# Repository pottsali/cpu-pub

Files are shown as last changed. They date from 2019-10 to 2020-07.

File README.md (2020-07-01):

# MUPS/16 Homebrew CPU project

This is public repo for files from the MUPS/16 homebrew CPU project. Please see http://mups16.net for details.

## Files

### Schematics
Currently I've only uploaded the schematics for the PCBs here, and will add more as I complete the last few bits. Most of the schematics are documented on the MUPS/16 [website](http://mups16.net).

### Others
I have a few other sets of files to clean up and upload:
 - A gate-level simulation of the whole system in [Digital](https://github.com/hneemann/Digital) format
 - Microcode generation, for the control ROMs
 - An assembler
 - A very basic monitor to test the system
 
These are not yet in a fit state to upload, but I will add them as I clean them up.

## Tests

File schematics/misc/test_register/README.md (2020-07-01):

# Test register

This is a trivial, single 16-bit register with separate input and dual output buses. Kicad PCB files are included alongside the schematic. Each register has four control inputs:
 - `read`: if this is low then the register will latch the value on the `data` input the next time the `clk` signal goes high;
 - `wrA`: if this is low then the register will output its value to the A output bus
 - `wrB`: if this is low then the register will output its value to the B output bus
 - `clk`: the clock signal

Power input is 5 volts.

Note that this was my first ever attempt at a PCB, so I'm sure that there are a lot of bad design choices here. One thing I've already noticed is that the power and ground traces are too thin. I also over-complicated the routing of traces by not taking advantage of the fact that a trace can happily fit through the gap between pads of any of the ICs.

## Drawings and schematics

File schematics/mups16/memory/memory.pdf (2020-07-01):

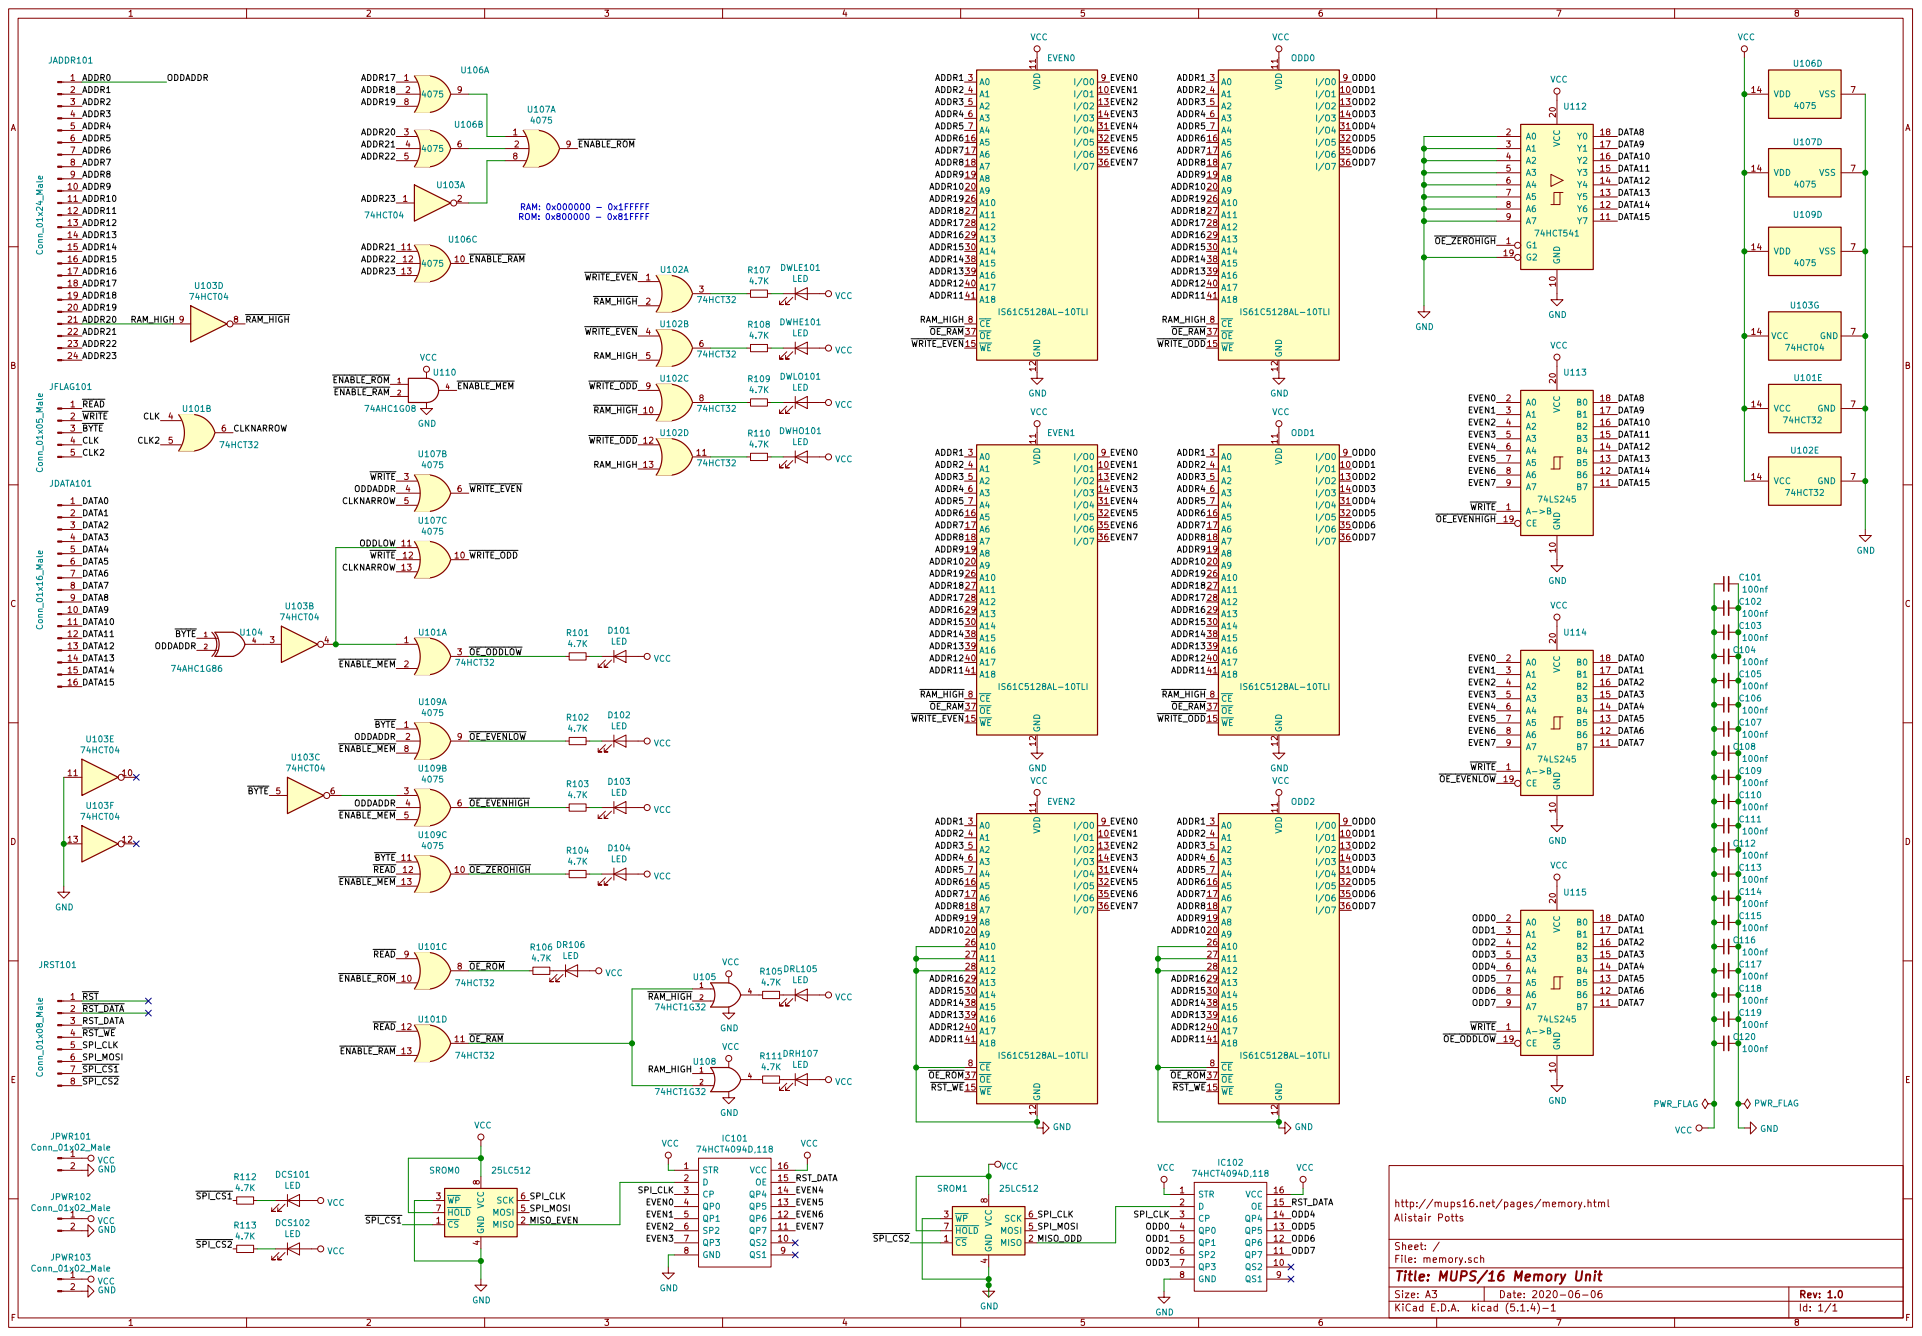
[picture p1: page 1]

4 MOSI 5 SCK 6 HOLD 7 VCC

File: memory.sch Sheet: / Alistair Potts http://mups16.net/pages/memory.html

Id: 1/1 Title: MUPS/16 Memory Unit

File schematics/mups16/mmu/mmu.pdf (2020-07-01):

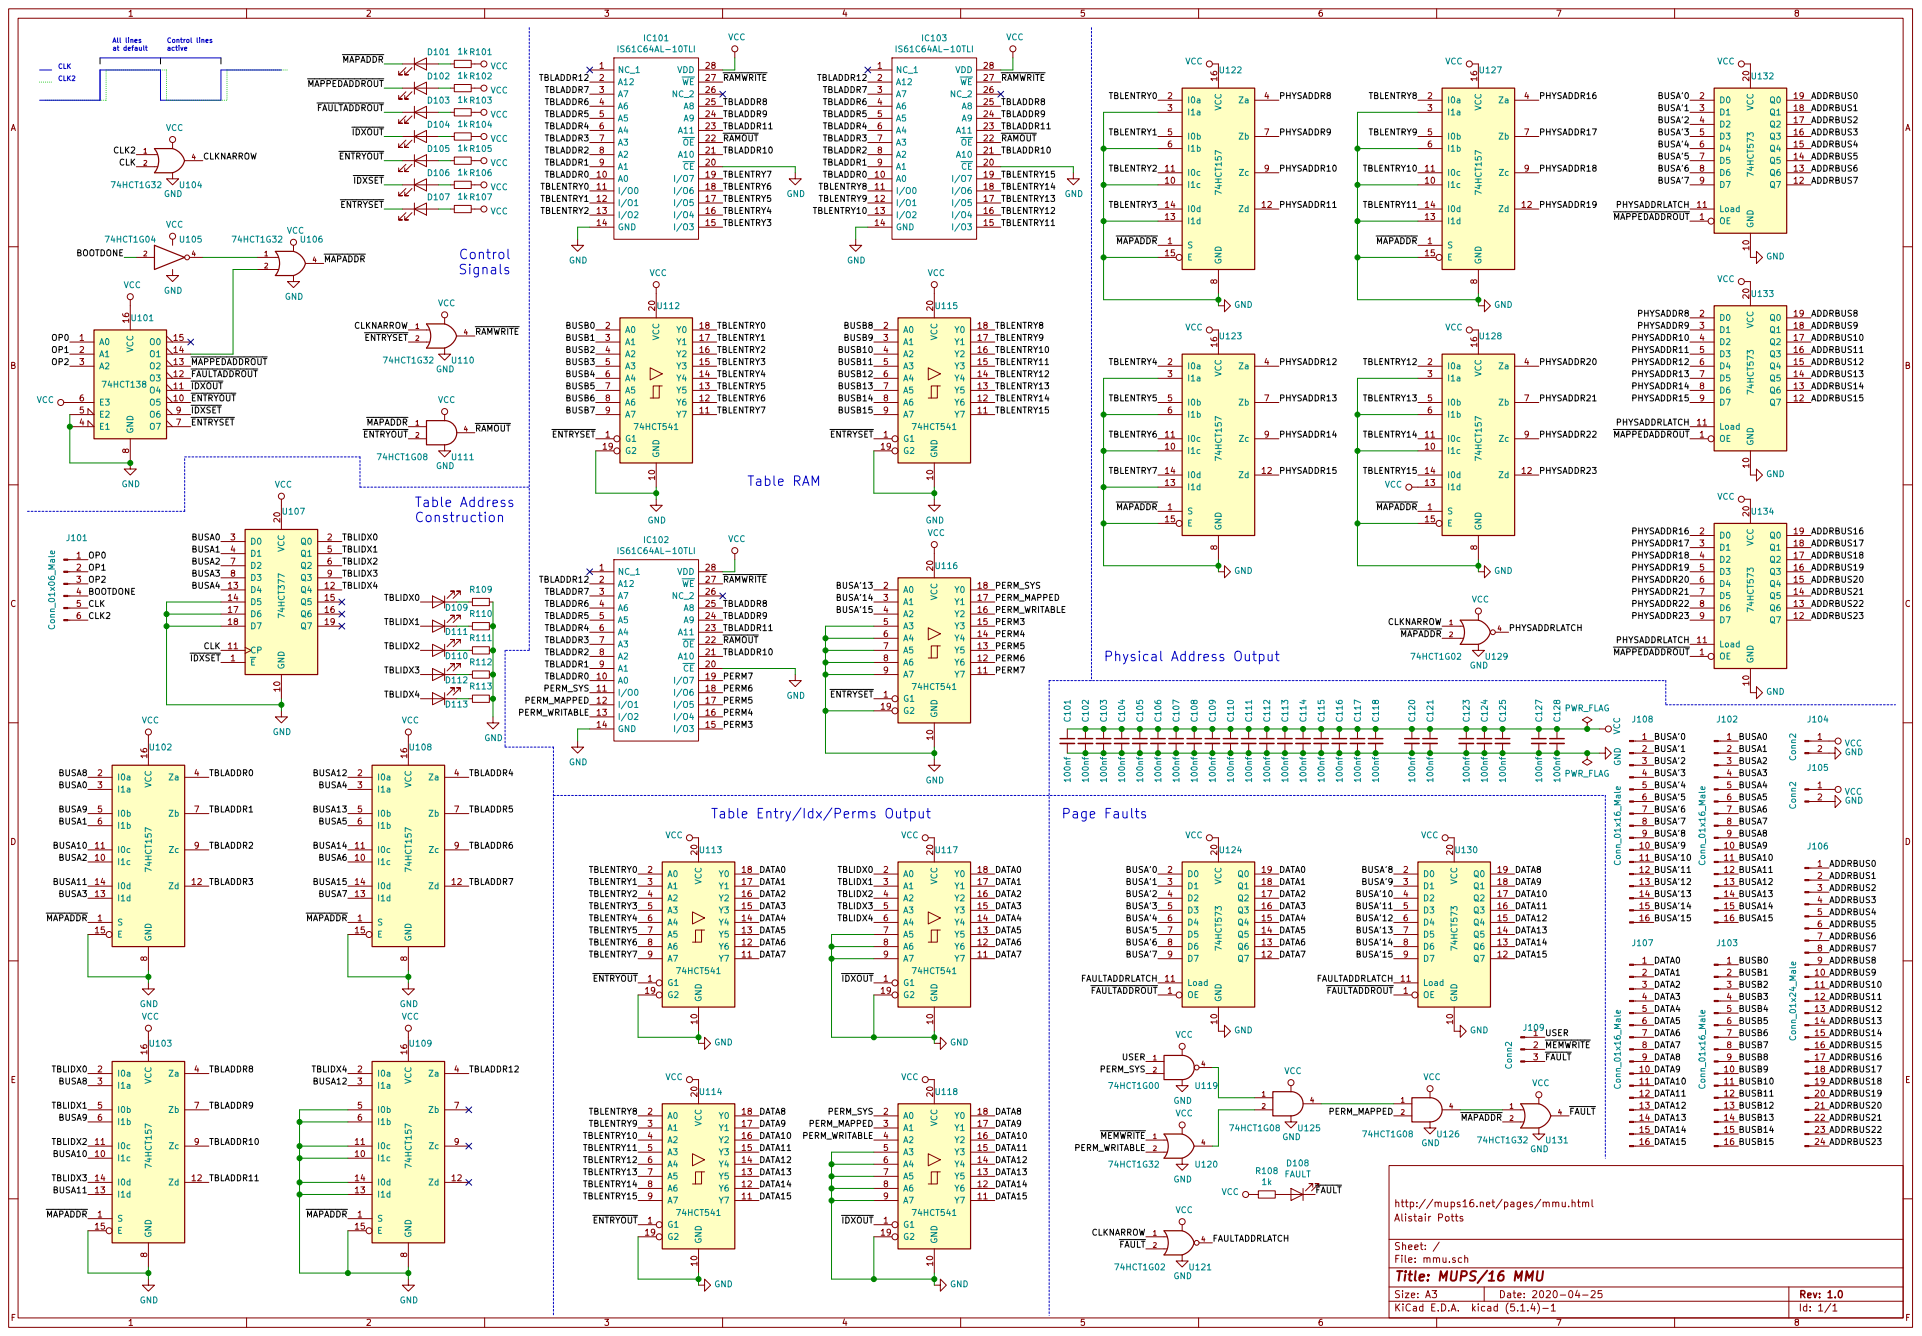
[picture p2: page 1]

BUSA'3 BUSA'2 BUSA'1 BUSA'0

Table Entry/Idx/Perms Output

BUSA'15 BUSA'14 BUSA'13 BUSA'12 BUSA'11 BUSA'10 BUSA'9 BUSA'8 BUSA'7 BUSA'6

File: mmu.sch Sheet: / Alistair Potts http://mups16.net/pages/mmu.html

Id: 1/1 Title: MUPS/16 MMU

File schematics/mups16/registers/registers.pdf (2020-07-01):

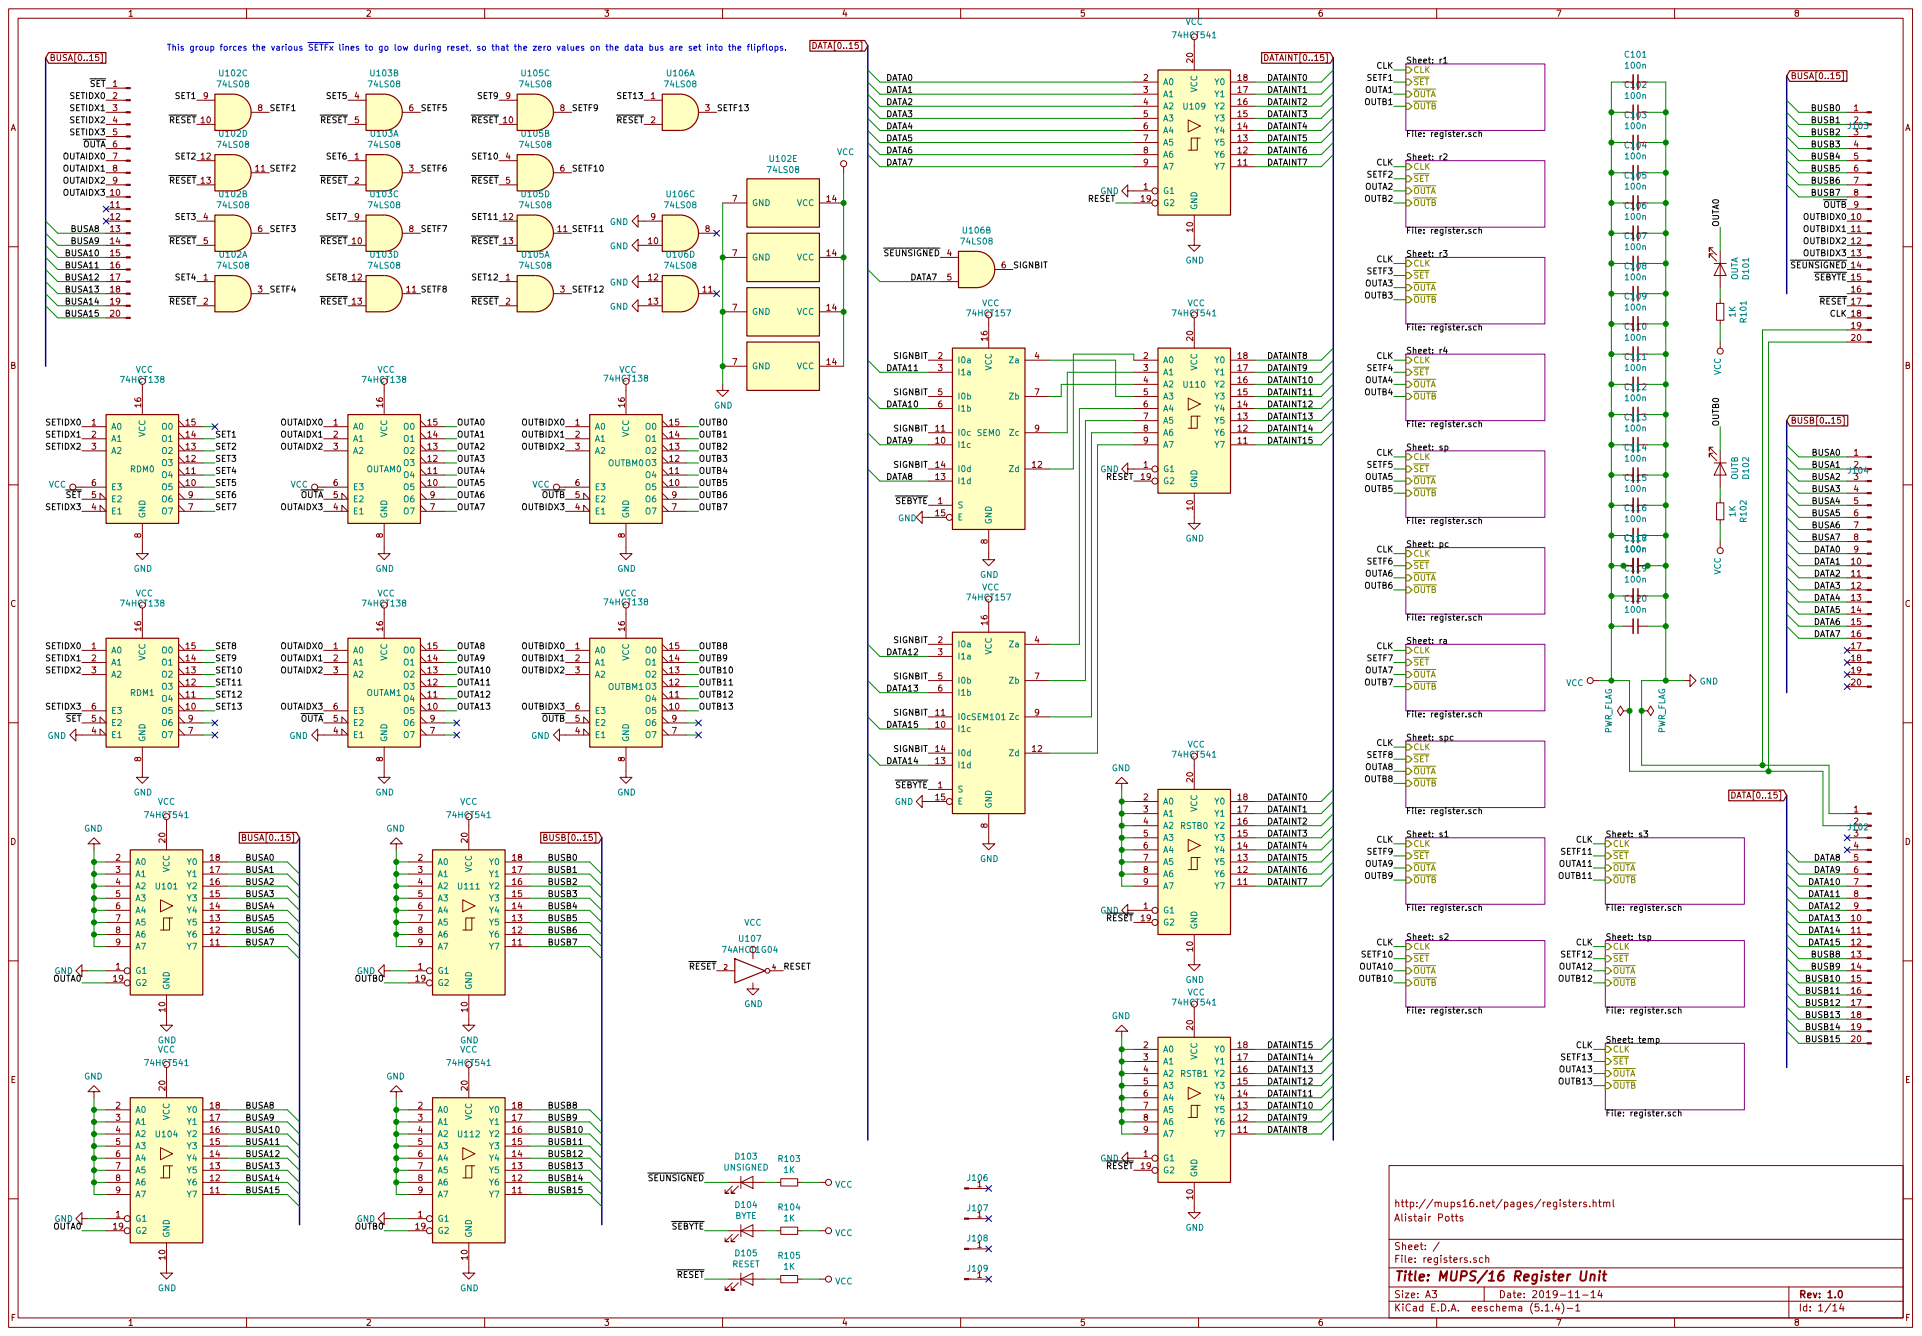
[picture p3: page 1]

This group forces the various SETFx lines to go low during reset, so that the zero values on the data bus are set into the flipflops.

Sheet: r1 File: register.sch CLK

Sheet: r2 File: register.sch CLK
CLK
SETF2 OUTA2

Sheet: r3 File: register.sch CLK
SETF3 OUTA3 OUTB3 CLK

Sheet: r4 File: register.sch CLK
SETF4 OUTA4 OUTB4 CLK

Sheet: sp
File: register.sch CLK
SET OUTA OUTB
SETF8 OUTA5 OUTB8 CLK

Sheet: pc
SETF6 OUTA6 OUTB6 CLK

Sheet: ra File: register.sch CLK
SETF7 OUTA7 OUTB7 CLK

Sheet: spc

Sheet: s1 File: register.sch CLK
SETF9 OUTA9 OUTB9 CLK

Sheet: s3 File: register.sch CLK

Sheet: s2 File: register.sch CLK

Sheet: tsp
SETF12 OUTA12 OUTB12 CLK

Sheet: temp

File: registers.sch Sheet: / Alistair Potts http://mups16.net/pages/registers.html

Id: 1/14 Title: MUPS/16 Register Unit

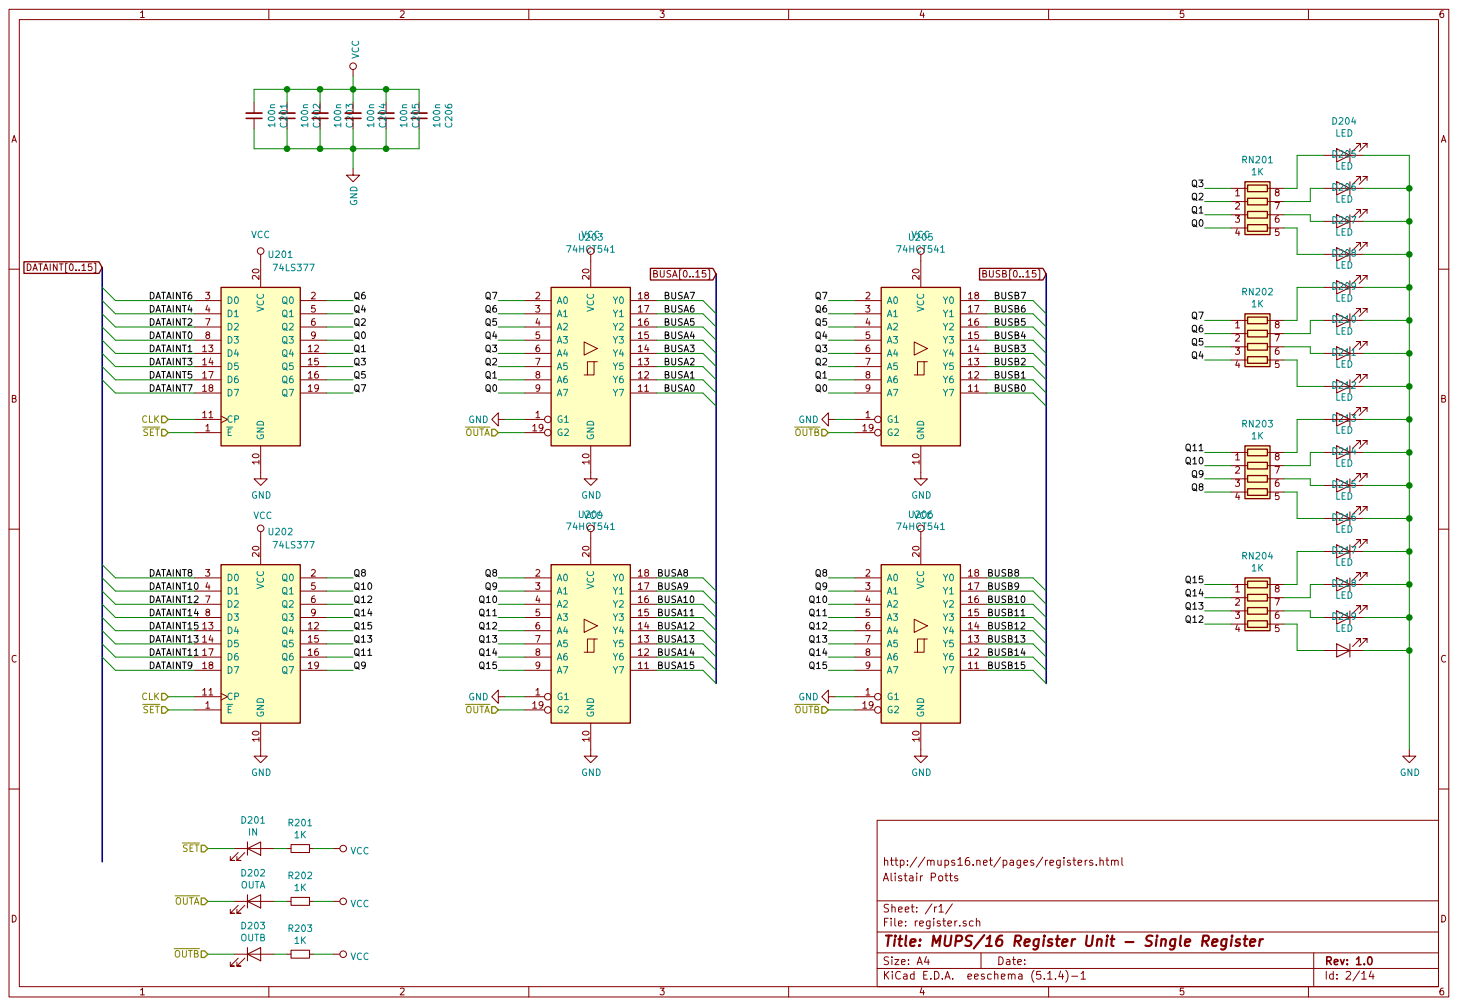
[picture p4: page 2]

File: register.sch Sheet: /r1/ Alistair Potts http://mups16.net/pages/registers.html R201

Id: 2/14 Title: MUPS/16 Register Unit - Single Register

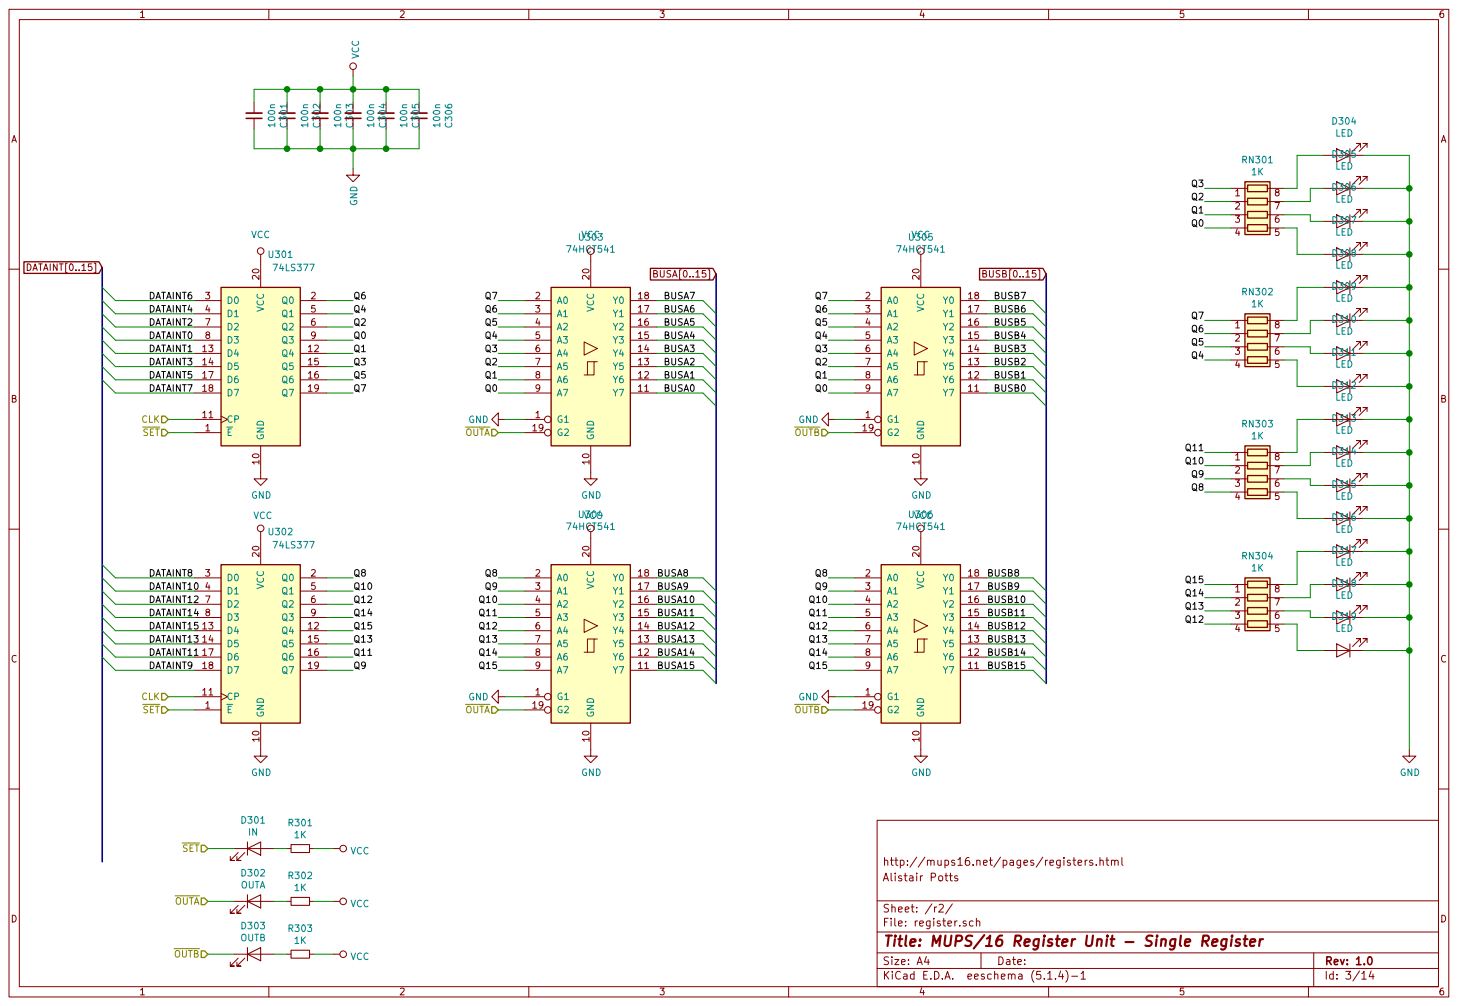
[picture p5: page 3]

File: register.sch Sheet: /r2/ Alistair Potts http://mups16.net/pages/registers.html R301

Id: 3/14 Title: MUPS/16 Register Unit - Single Register

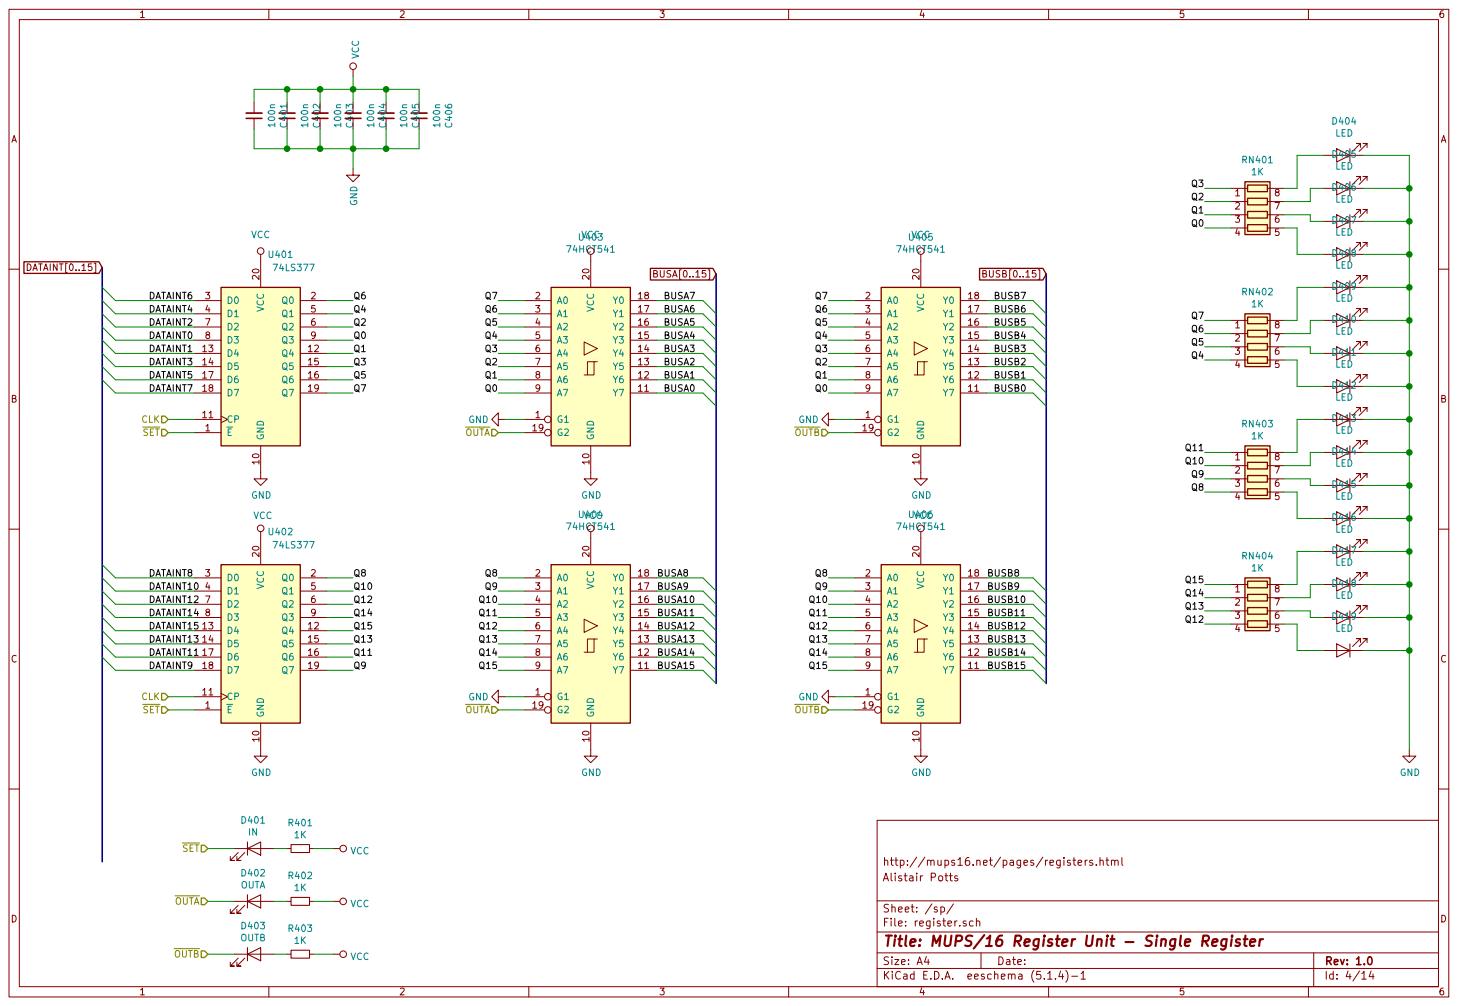
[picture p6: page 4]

Sheet: /sp/ Alistair Potts http://mups16.net/pages/registers.html R401

File: register.sch
Id: 4/14 Title: MUPS/16 Register Unit - Single Register

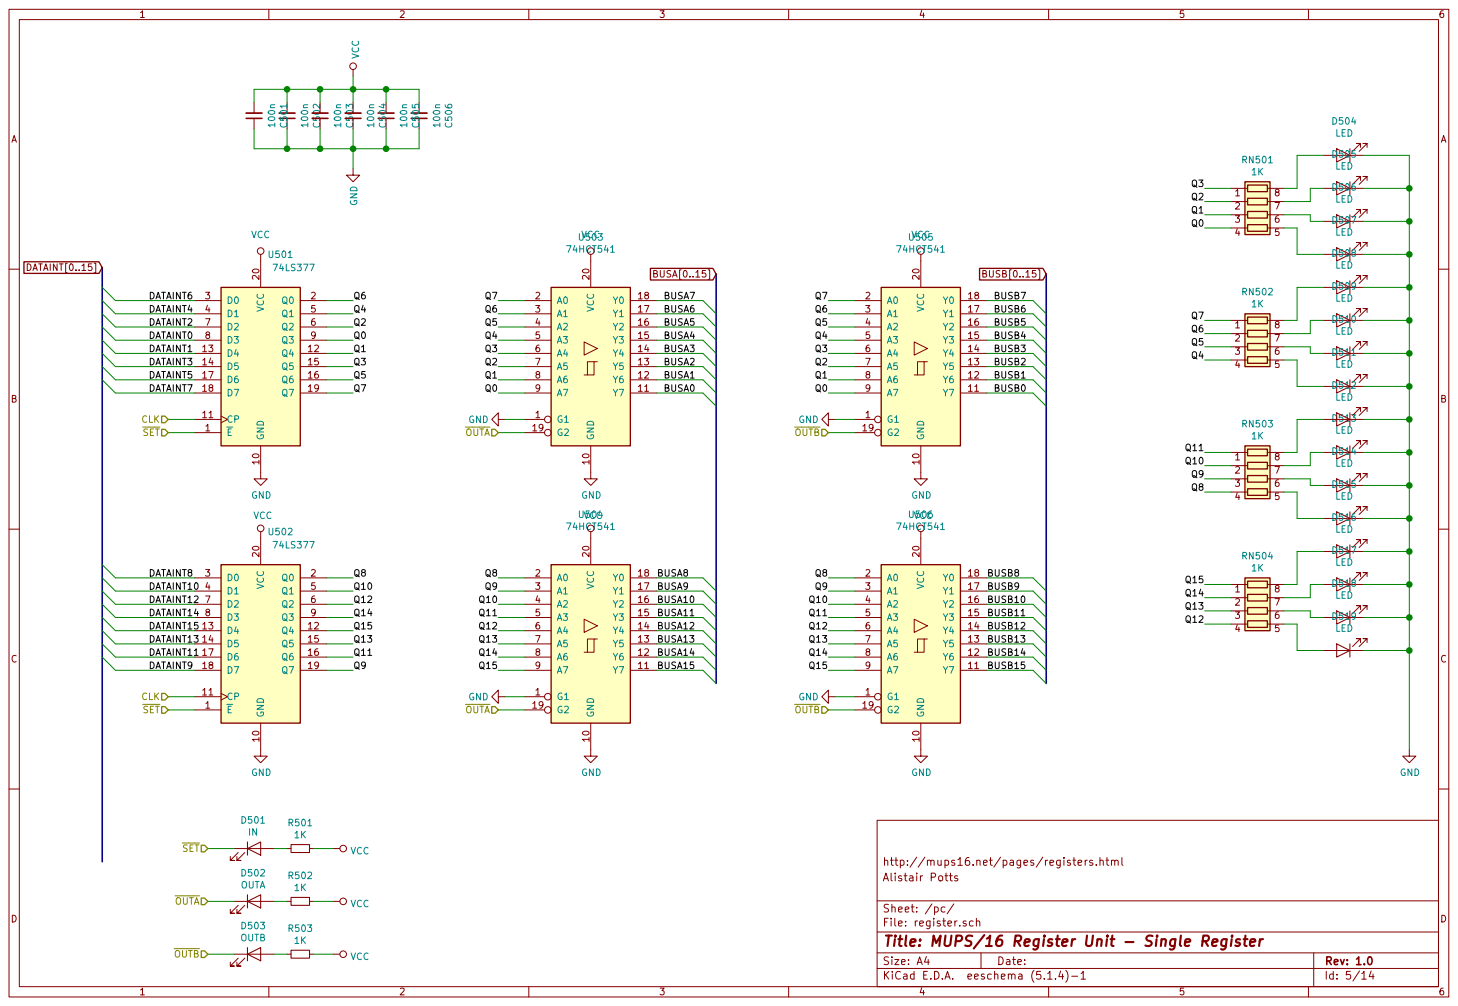
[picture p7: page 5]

Sheet: /pc/ Alistair Potts http://mups16.net/pages/registers.html R501

File: register.sch
Id: 5/14 Title: MUPS/16 Register Unit - Single Register

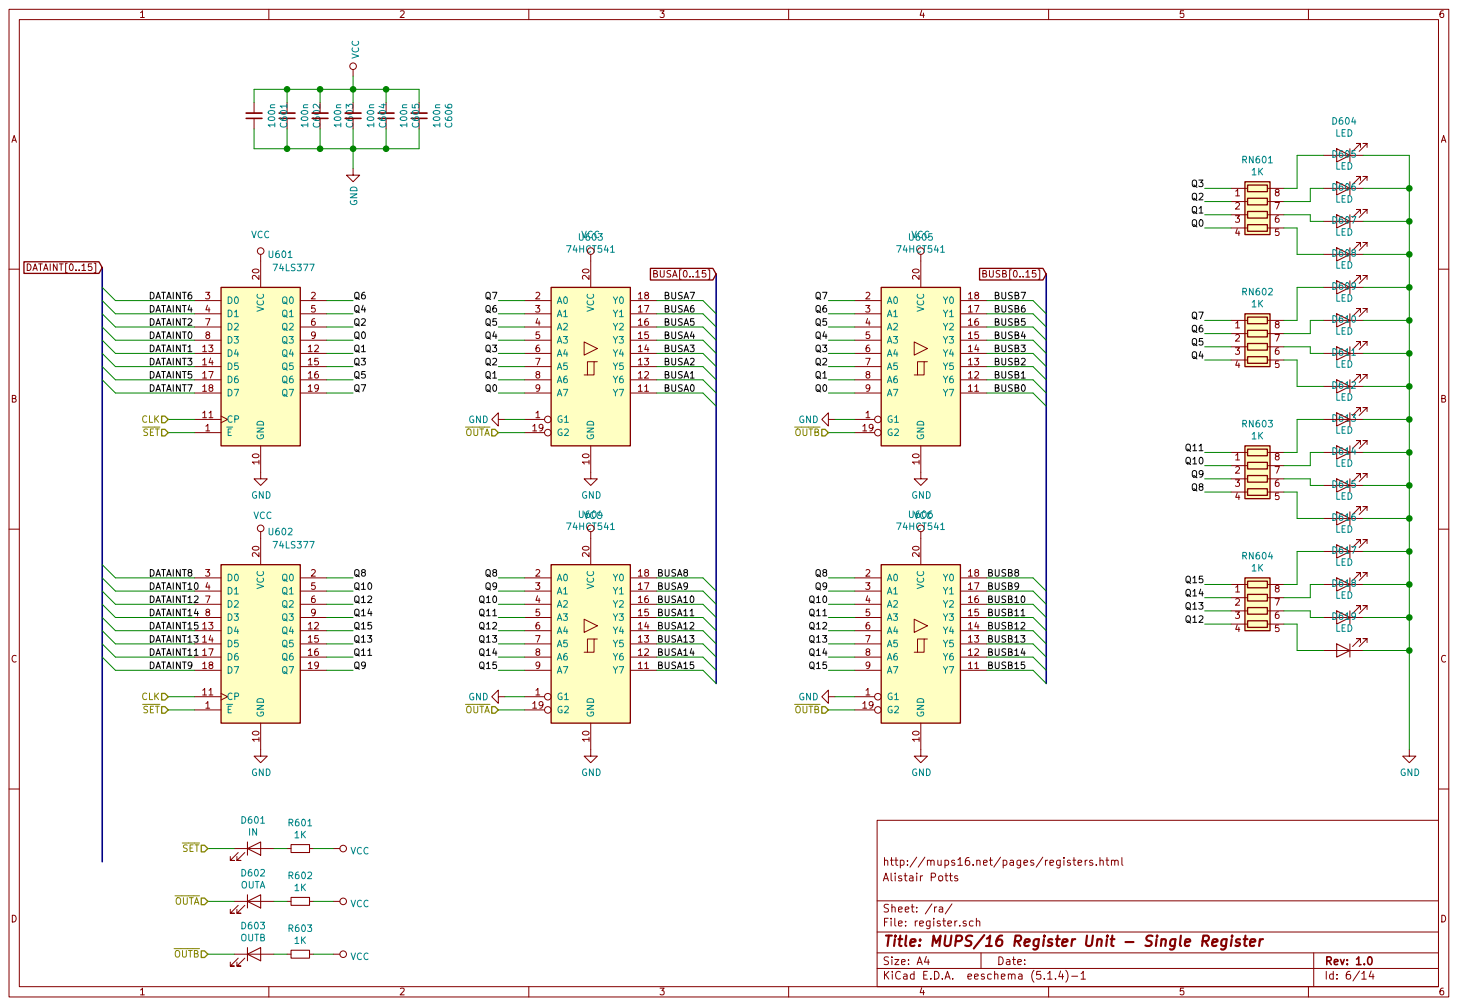
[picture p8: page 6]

File: register.sch Sheet: /ra/ Alistair Potts http://mups16.net/pages/registers.html R601

Id: 6/14 Title: MUPS/16 Register Unit - Single Register

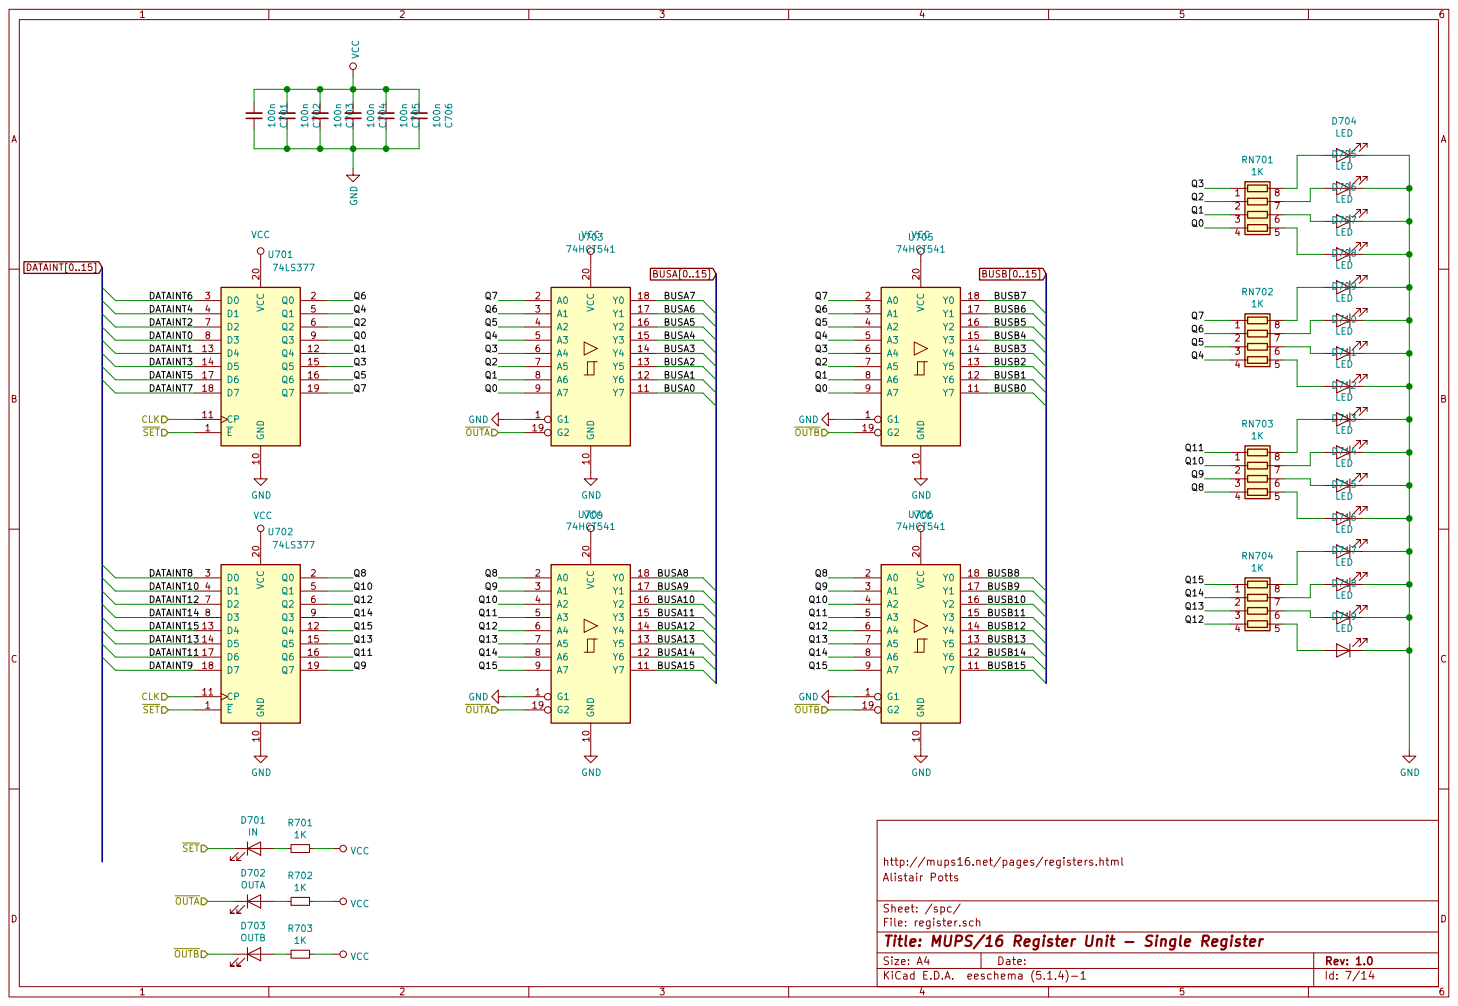
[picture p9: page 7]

Sheet: /spc/ Alistair Potts http://mups16.net/pages/registers.html R701

File: register.sch
Id: 7/14 Title: MUPS/16 Register Unit - Single Register

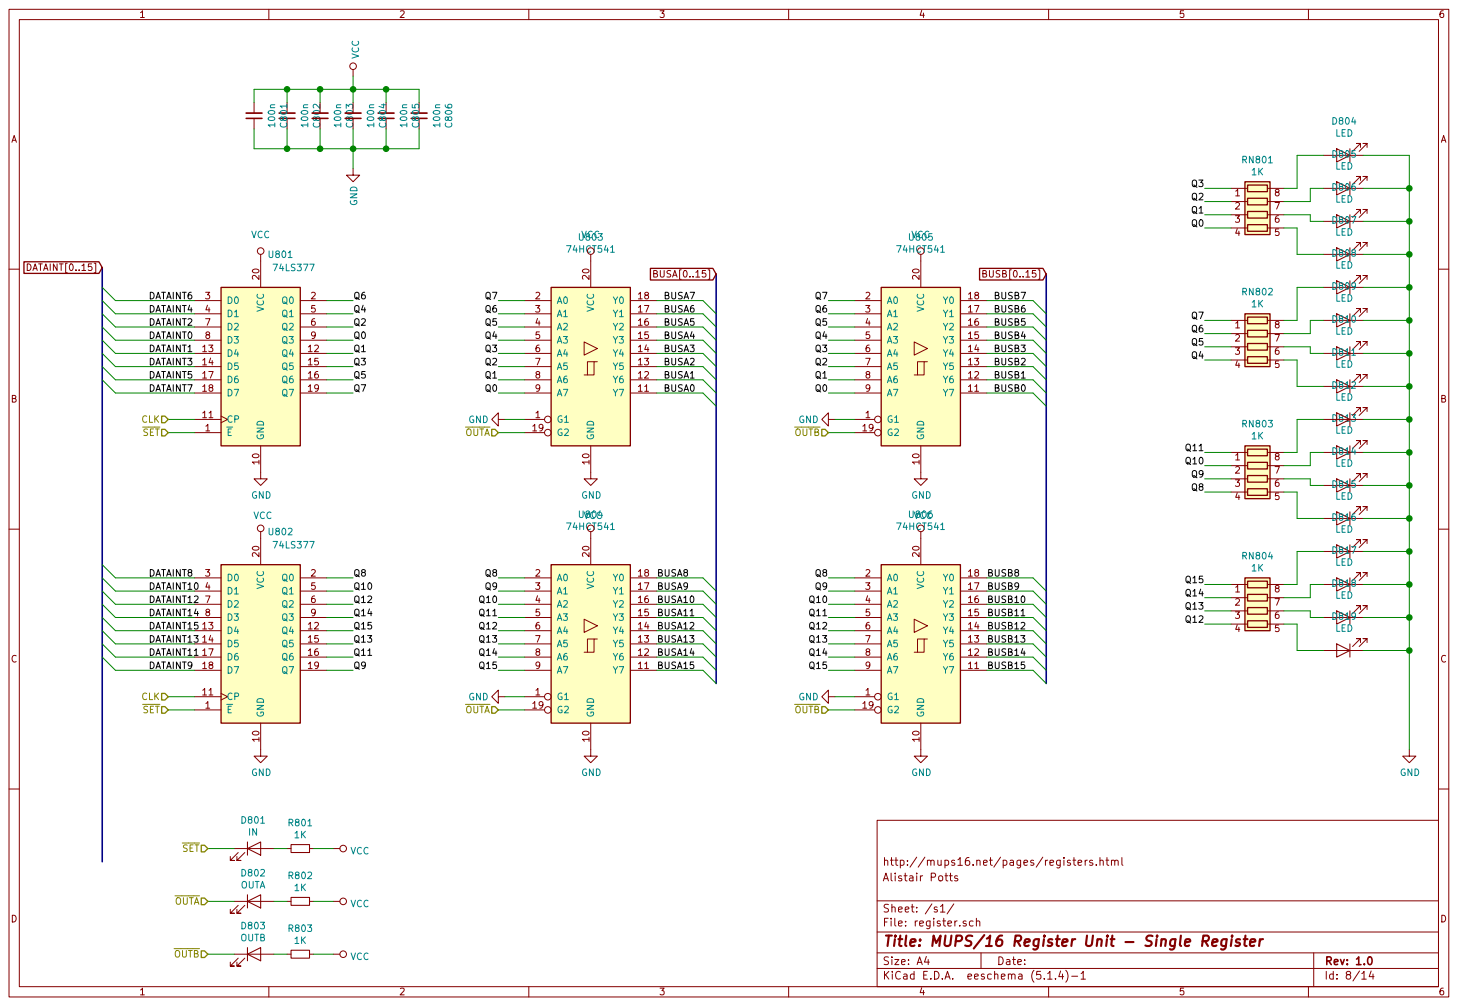
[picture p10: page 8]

File: register.sch Sheet: /s1/ Alistair Potts http://mups16.net/pages/registers.html R801

Id: 8/14 Title: MUPS/16 Register Unit - Single Register

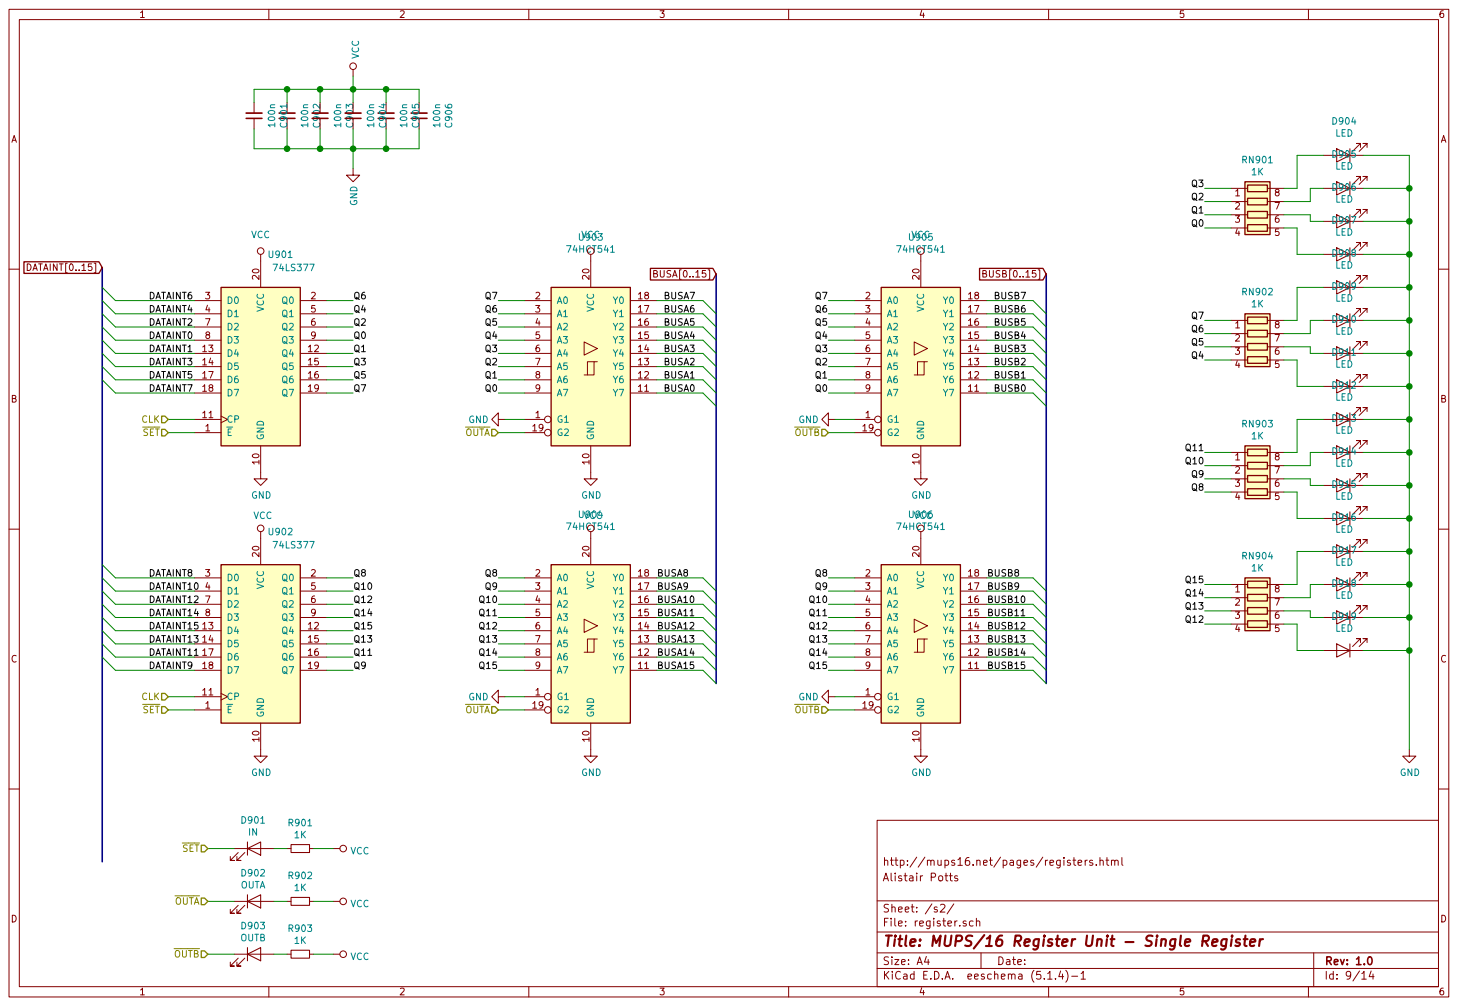
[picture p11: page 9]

File: register.sch Sheet: /s2/ Alistair Potts http://mups16.net/pages/registers.html R901

Id: 9/14 Title: MUPS/16 Register Unit - Single Register

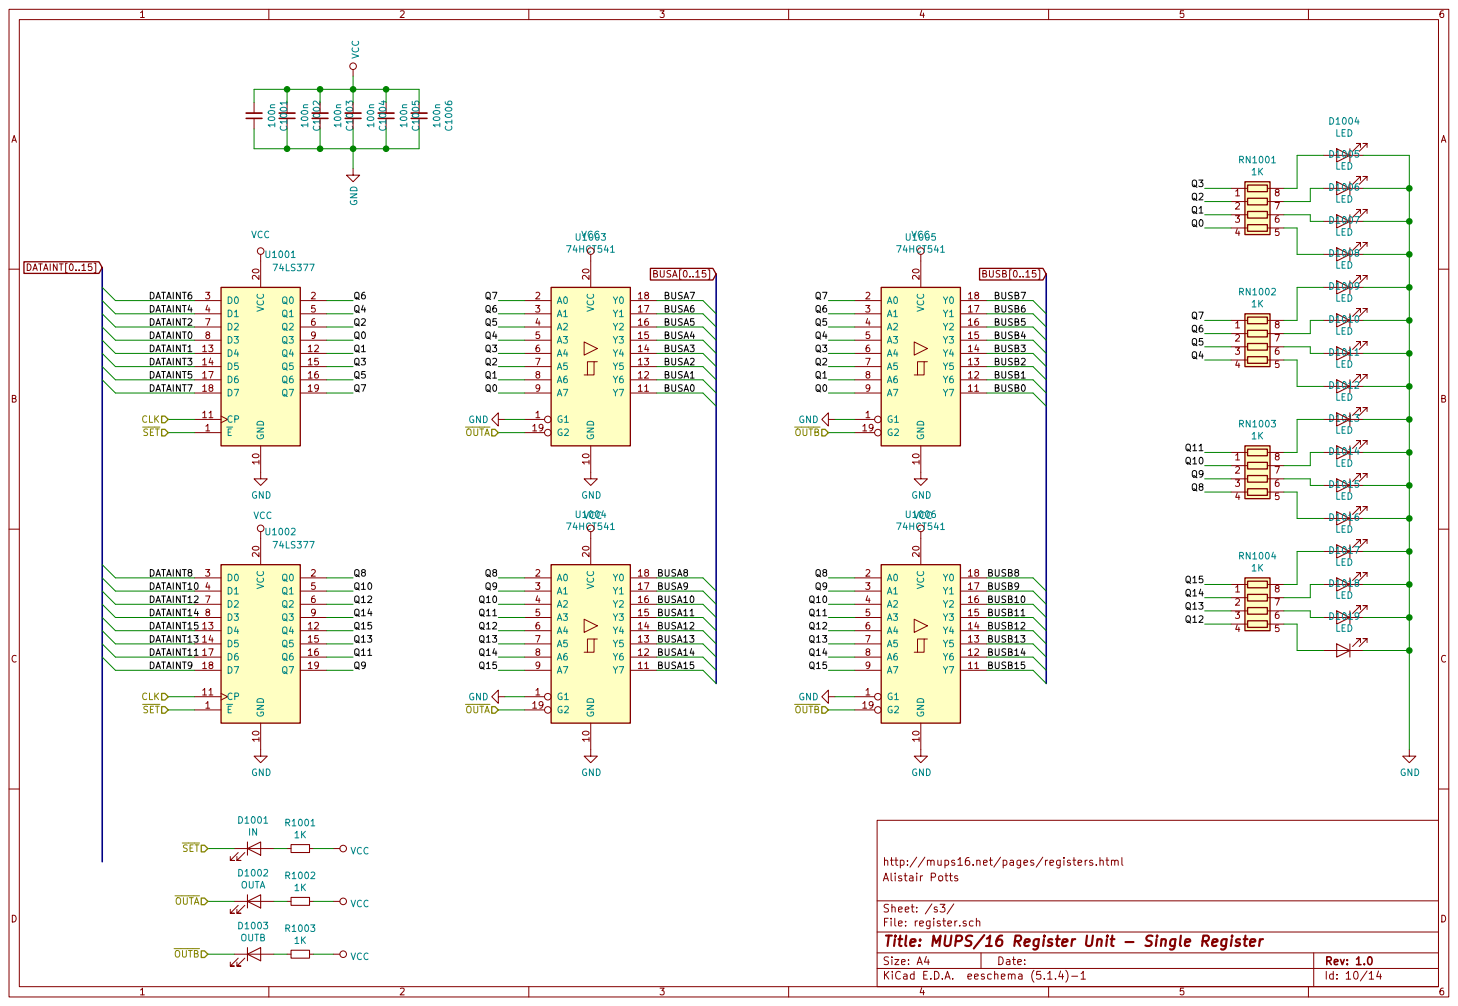
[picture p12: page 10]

File: register.sch Sheet: /s3/ Alistair Potts http://mups16.net/pages/registers.html R1001

Id: 10/14 Title: MUPS/16 Register Unit - Single Register


File: register.sch Sheet: /r3/ Alistair Potts http://mups16.net/pages/registers.html R1101

Id: 11/14 Title: MUPS/16 Register Unit - Single Register


File: register.sch Sheet: /r4/ Alistair Potts http://mups16.net/pages/registers.html R1201

Id: 12/14 Title: MUPS/16 Register Unit - Single Register


Sheet: /tsp/ Alistair Potts http://mups16.net/pages/registers.html R1301

File: register.sch
Id: 13/14 Title: MUPS/16 Register Unit - Single Register


Sheet: /temp/ Alistair Potts http://mups16.net/pages/registers.html R1401

File: register.sch
Id: 14/14 Title: MUPS/16 Register Unit - Single Register

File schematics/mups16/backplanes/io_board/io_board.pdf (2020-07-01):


INT RESET SCL SDA

File: io_board.sch Sheet: / Alistair Potts http://mups16.net/pages/tester.html 1

Id: 1/1 Title: MUPS/16 Tester

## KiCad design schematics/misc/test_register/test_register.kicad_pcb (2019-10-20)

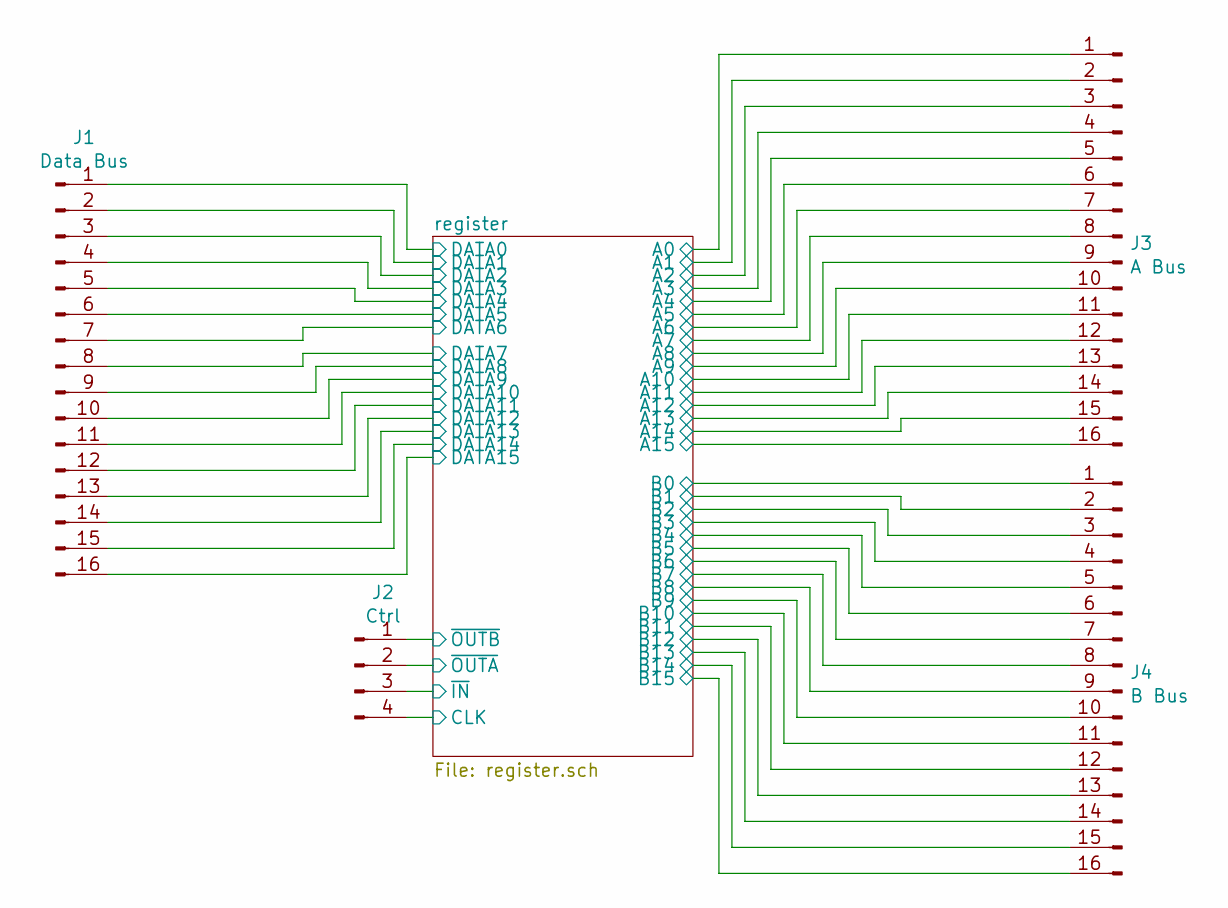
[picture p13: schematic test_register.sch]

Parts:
J1: Data Bus; PinHeader_1x16_P2.54mm_Vertical
J2: Ctrl; PinHeader_1x05_P2.54mm_Vertical
J3: A Bus; PinHeader_1x16_P2.54mm_Vertical
J4: B Bus; PinHeader_1x16_P2.54mm_Vertical

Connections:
/register/A0: J3.1; also elsewhere on the board
/register/A1: J3.2; also elsewhere on the board
/register/A2: J3.3; also elsewhere on the board
/register/A3: J3.4; also elsewhere on the board
/register/A4: J3.5; also elsewhere on the board
/register/A5: J3.6; also elsewhere on the board
/register/A6: J3.7; also elsewhere on the board
/register/A7: J3.8; also elsewhere on the board
/register/A8: J3.9; also elsewhere on the board
/register/A9: J3.10; also elsewhere on the board
/register/A10: J3.11; also elsewhere on the board
/register/A11: J3.12; also elsewhere on the board
/register/A12: J3.13; also elsewhere on the board
/register/A13: J3.14; also elsewhere on the board
/register/A14: J3.15; also elsewhere on the board
/register/A15: J3.16; also elsewhere on the board
/register/B0: J4.1; also elsewhere on the board
/register/B1: J4.2; also elsewhere on the board
/register/B2: J4.3; also elsewhere on the board
/register/B3: J4.4; also elsewhere on the board
/register/B4: J4.5; also elsewhere on the board
/register/B5: J4.6; also elsewhere on the board
/register/B6: J4.7; also elsewhere on the board
/register/B7: J4.8; also elsewhere on the board
/register/B8: J4.9; also elsewhere on the board
/register/B9: J4.10; also elsewhere on the board
/register/B10: J4.11; also elsewhere on the board
/register/B11: J4.12; also elsewhere on the board
/register/B12: J4.13; also elsewhere on the board
/register/B13: J4.14; also elsewhere on the board
/register/B14: J4.15; also elsewhere on the board
/register/B15: J4.16; also elsewhere on the board
/register/CLK: J2.4; also elsewhere on the board
/register/DATA0: J1.1; also elsewhere on the board
/register/DATA1: J1.2; also elsewhere on the board
/register/DATA2: J1.3; also elsewhere on the board
/register/DATA3: J1.4; also elsewhere on the board
/register/DATA4: J1.5; also elsewhere on the board
/register/DATA5: J1.6; also elsewhere on the board
/register/DATA6: J1.7; also elsewhere on the board
/register/DATA7: J1.8; also elsewhere on the board
/register/DATA8: J1.9; also elsewhere on the board
/register/DATA9: J1.10; also elsewhere on the board
/register/DATA10: J1.11; also elsewhere on the board
/register/DATA11: J1.12; also elsewhere on the board
/register/DATA12: J1.13; also elsewhere on the board
/register/DATA13: J1.14; also elsewhere on the board
/register/DATA14: J1.15; also elsewhere on the board
/register/DATA15: J1.16; also elsewhere on the board
/register/~IN: J2.3; also elsewhere on the board
/register/~OUTA: J2.2; also elsewhere on the board
/register/~OUTB: J2.1; also elsewhere on the board

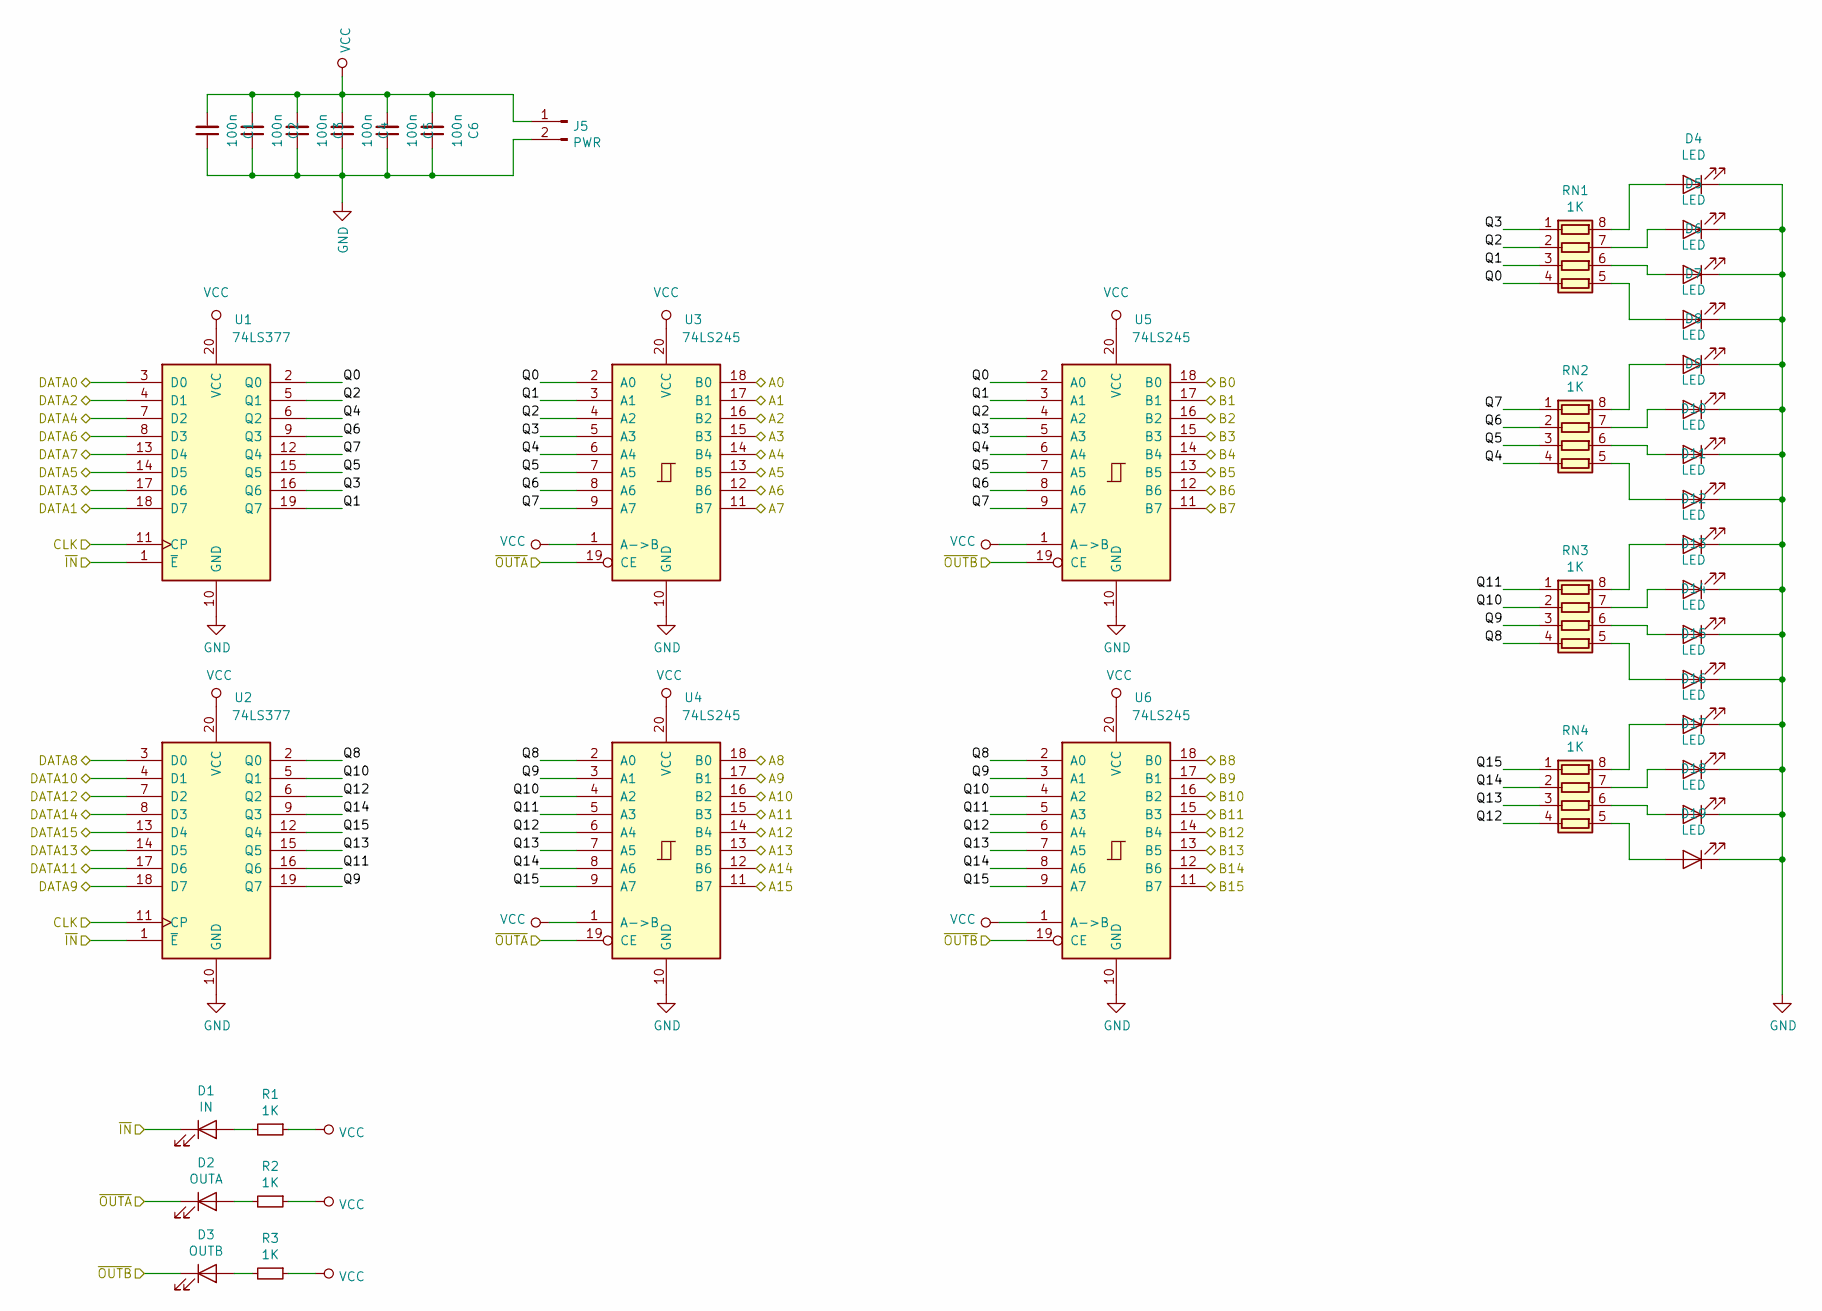
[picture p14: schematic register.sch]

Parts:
C1, C2, C3, C4, C5, C6: 100n; C_0805_2012Metric
D1: IN; LED_0805_2012Metric
D2: OUTA; LED_0805_2012Metric
D3: OUTB; LED_0805_2012Metric
D4, D5, D6, D7, D8, D9, D10, D11, D12, D13, D14, D15, D16, D17, D18, D19: LED; LED_0805_2012Metric
J5: PWR; PinHeader_1x02_P2.54mm_Vertical
R1, R2, R3: 1K; R_0805_2012Metric
RN1, RN2, RN3, RN4: 1K; R_Array_Convex_4x1206
U1, U2: 74LS377; SOIC-20W_7.5x12.8mm_P1.27mm
U3, U4, U5, U6: 74LS245; SOIC-20W_7.5x12.8mm_P1.27mm

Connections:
/register/A0: U3.18 (B0); also elsewhere on the board
/register/A1: U3.17 (B1); also elsewhere on the board
/register/A2: U3.16 (B2); also elsewhere on the board
/register/A3: U3.15 (B3); also elsewhere on the board
/register/A4: U3.14 (B4); also elsewhere on the board
/register/A5: U3.13 (B5); also elsewhere on the board
/register/A6: U3.12 (B6); also elsewhere on the board
/register/A7: U3.11 (B7); also elsewhere on the board
/register/A8: U4.18 (B0); also elsewhere on the board
/register/A9: U4.17 (B1); also elsewhere on the board
/register/A10: U4.16 (B2); also elsewhere on the board
/register/A11: U4.15 (B3); also elsewhere on the board
/register/A12: U4.14 (B4); also elsewhere on the board
/register/A13: U4.13 (B5); also elsewhere on the board
/register/A14: U4.12 (B6); also elsewhere on the board
/register/A15: U4.11 (B7); also elsewhere on the board
/register/B0: U5.18 (B0); also elsewhere on the board
/register/B1: U5.17 (B1); also elsewhere on the board
/register/B2: U5.16 (B2); also elsewhere on the board
/register/B3: U5.15 (B3); also elsewhere on the board
/register/B4: U5.14 (B4); also elsewhere on the board
/register/B5: U5.13 (B5); also elsewhere on the board
/register/B6: U5.12 (B6); also elsewhere on the board
/register/B7: U5.11 (B7); also elsewhere on the board
/register/B8: U6.18 (B0); also elsewhere on the board
/register/B9: U6.17 (B1); also elsewhere on the board
/register/B10: U6.16 (B2); also elsewhere on the board
/register/B11: U6.15 (B3); also elsewhere on the board
/register/B12: U6.14 (B4); also elsewhere on the board
/register/B13: U6.13 (B5); also elsewhere on the board
/register/B14: U6.12 (B6); also elsewhere on the board
/register/B15: U6.11 (B7); also elsewhere on the board
/register/CLK: U1.11 (CP), U2.11 (CP); also elsewhere on the board
/register/DATA0: U1.3 (D0); also elsewhere on the board
/register/DATA1: U1.18 (D7); also elsewhere on the board
/register/DATA2: U1.4 (D1); also elsewhere on the board
/register/DATA3: U1.17 (D6); also elsewhere on the board
/register/DATA4: U1.7 (D2); also elsewhere on the board
/register/DATA5: U1.14 (D5); also elsewhere on the board
/register/DATA6: U1.8 (D3); also elsewhere on the board
/register/DATA7: U1.13 (D4); also elsewhere on the board
/register/DATA8: U2.3 (D0); also elsewhere on the board
/register/DATA9: U2.18 (D7); also elsewhere on the board
/register/DATA10: U2.4 (D1); also elsewhere on the board
/register/DATA11: U2.17 (D6); also elsewhere on the board
/register/DATA12: U2.7 (D2); also elsewhere on the board
/register/DATA13: U2.14 (D5); also elsewhere on the board
/register/DATA14: U2.8 (D3); also elsewhere on the board
/register/DATA15: U2.13 (D4); also elsewhere on the board
/register/Q0: RN1.4 (R4.1), U1.2 (Q0), U3.2 (A0), U5.2 (A0)
/register/Q1: RN1.3 (R3.1), U1.19 (Q7), U3.3 (A1), U5.3 (A1)
/register/Q2: RN1.2 (R2.1), U1.5 (Q1), U3.4 (A2), U5.4 (A2)
/register/Q3: RN1.1 (R1.1), U1.16 (Q6), U3.5 (A3), U5.5 (A3)
/register/Q4: RN2.4 (R4.1), U1.6 (Q2), U3.6 (A4), U5.6 (A4)
/register/Q5: RN2.3 (R3.1), U1.15 (Q5), U3.7 (A5), U5.7 (A5)
/register/Q6: RN2.2 (R2.1), U1.9 (Q3), U3.8 (A6), U5.8 (A6)
/register/Q7: RN2.1 (R1.1), U1.12 (Q4), U3.9 (A7), U5.9 (A7)
/register/Q8: RN3.4 (R4.1), U2.2 (Q0), U4.2 (A0), U6.2 (A0)
/register/Q9: RN3.3 (R3.1), U2.19 (Q7), U4.3 (A1), U6.3 (A1)
/register/Q10: RN3.2 (R2.1), U2.5 (Q1), U4.4 (A2), U6.4 (A2)
/register/Q11: RN3.1 (R1.1), U2.16 (Q6), U4.5 (A3), U6.5 (A3)
/register/Q12: RN4.4 (R4.1), U2.6 (Q2), U4.6 (A4), U6.6 (A4)
/register/Q13: RN4.3 (R3.1), U2.15 (Q5), U4.7 (A5), U6.7 (A5)
/register/Q14: RN4.2 (R2.1), U2.9 (Q3), U4.8 (A6), U6.8 (A6)
/register/Q15: RN4.1 (R1.1), U2.12 (Q4), U4.9 (A7), U6.9 (A7)
/register/~IN: D1.1 (K), U1.1 (~E), U2.1 (~E); also elsewhere on the board
/register/~OUTA: D2.1 (K), U3.19 (CE), U4.19 (CE); also elsewhere on the board
/register/~OUTB: D3.1 (K), U5.19 (CE), U6.19 (CE); also elsewhere on the board
GND: C1.1, C2.1, C3.1, C4.1, C5.1, C6.1, D4.1 (K), D5.1 (K), D6.1 (K), D7.1 (K), D8.1 (K), D9.1 (K), D10.1 (K), D11.1 (K), D12.1 (K), D13.1 (K), D14.1 (K), D15.1 (K), D16.1 (K), D17.1 (K), D18.1 (K), D19.1 (K), J5.2, U1.10 (GND), U2.10 (GND), U3.10 (GND), U4.10 (GND), U5.10 (GND), U6.10 (GND); also elsewhere on the board
unnamed: D1.2 (A), R1.2
unnamed: D2.2 (A), R2.2
unnamed: D3.2 (A), R3.2
unnamed: D4.2 (A), RN1.8 (R1.2)
unnamed: D5.2 (A), RN1.7 (R2.2)
unnamed: D6.2 (A), RN1.6 (R3.2)
unnamed 75: D7.2 (A), RN1.5 (R4.2); also elsewhere on the board
unnamed: D8.2 (A), RN2.8 (R1.2)
unnamed: D9.2 (A), RN2.7 (R2.2)
unnamed: D10.2 (A), RN2.6 (R3.2)
unnamed: D11.2 (A), RN2.5 (R4.2)
unnamed: D12.2 (A), RN3.8 (R1.2)
unnamed: D13.2 (A), RN3.7 (R2.2)
unnamed: D14.2 (A), RN3.6 (R3.2)
unnamed: D15.2 (A), RN3.5 (R4.2)
unnamed: D16.2 (A), RN4.8 (R1.2)
unnamed: D17.2 (A), RN4.7 (R2.2)
unnamed: D18.2 (A), RN4.6 (R3.2)
unnamed: D19.2 (A), RN4.5 (R4.2)
VCC: C1.2, C2.2, C3.2, C4.2, C5.2, C6.2, J5.1, R1.1, R2.1, R3.1, U1.20 (VCC), U2.20 (VCC), U3.1 (A->B), U3.20 (VCC), U4.1 (A->B), U4.20 (VCC), U5.1 (A->B), U5.20 (VCC), U6.1 (A->B), U6.20 (VCC)

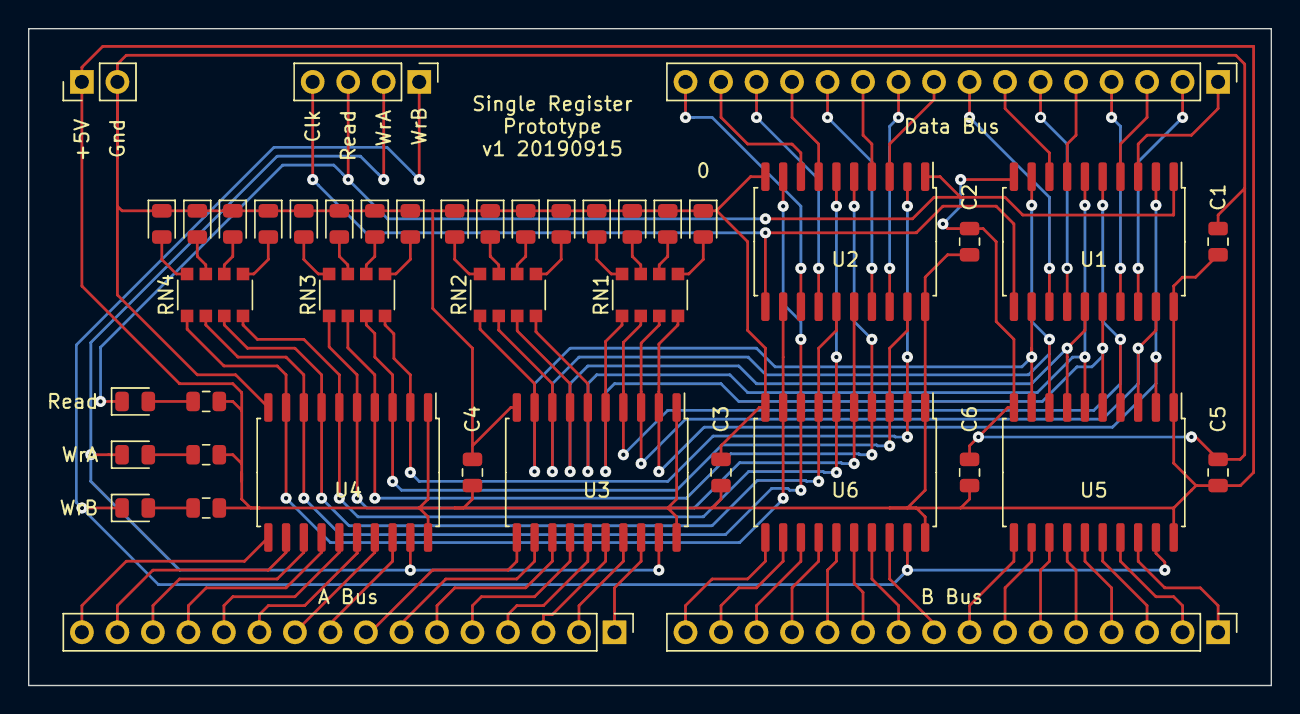
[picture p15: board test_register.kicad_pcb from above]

Board: 2 copper layers, 88.9 x 47.0 mm, 43 parts (0 on the bottom side), 89 nets.

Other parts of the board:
0: LED; LED_0805_2012Metric

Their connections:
GND: 0.1; also elsewhere on the board
unnamed 75: 0.2; also elsewhere on the board

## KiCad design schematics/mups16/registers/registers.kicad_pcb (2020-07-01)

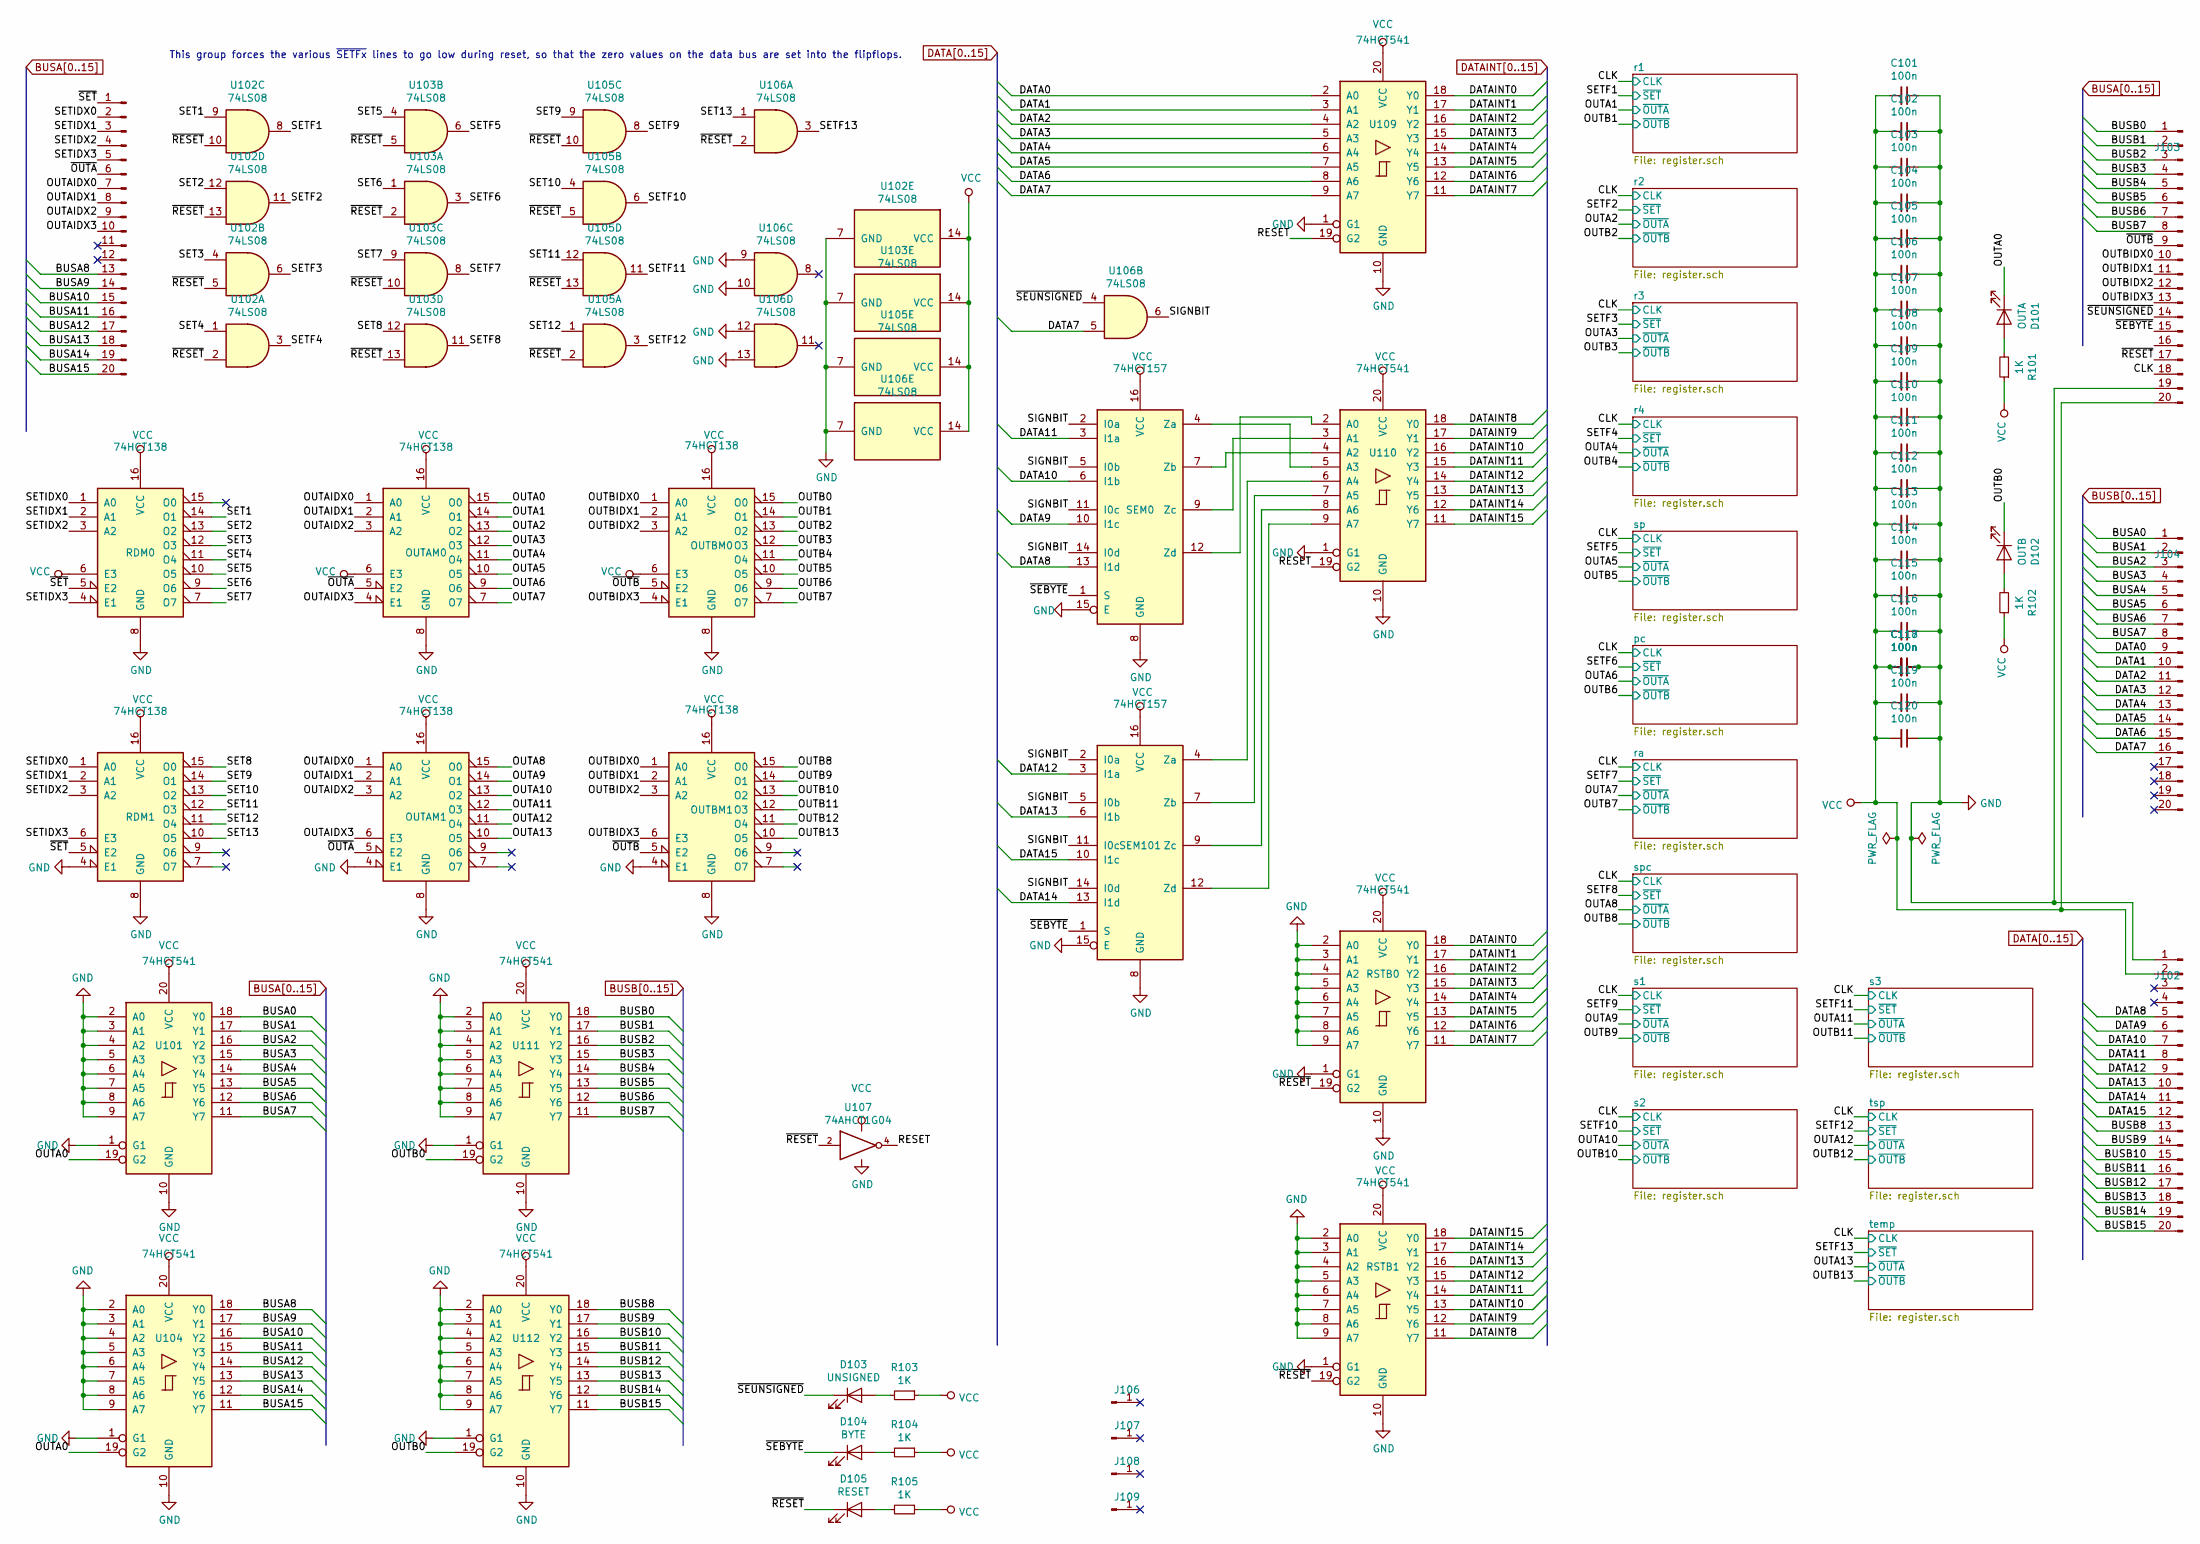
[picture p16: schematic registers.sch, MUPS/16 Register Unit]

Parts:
C101, C102, C103, C104, C105, C106, C107, C108, C109, C110, C111, C112, C113, C114, C115, C116, C117, C118, C119, C120: 100n; C_0805_2012Metric
D101: OUTA; LED_0805_2012Metric
D102: OUTB; LED_0805_2012Metric
D103: UNSIGNED; LED_0805_2012Metric
D104: BYTE; LED_0805_2012Metric
D105: RESET; LED_0805_2012Metric
J101: Conn_01x20_Male; PinHeader_1x20_P2.54mm_Vertical
J102, J103, J104: Conn_01x16_Male; PinHeader_1x20_P2.54mm_Vertical
J106, J107, J108, J109: Conn_01x01_Male; MountingHole_4mm_Pad
OUTAM0, OUTAM1: 74HCT138; SOIC-16_3.9x9.9mm_P1.27mm
OUTBM0, OUTBM1: 74HCT138; SOIC-16_3.9x9.9mm_P1.27mm
R101, R102, R103, R104, R105: 1K; R_0805_2012Metric
RDM0, RDM1: 74HCT138; SOIC-16_3.9x9.9mm_P1.27mm
RSTB0, RSTB1: 74HCT541; SOIC-20W_7.5x12.8mm_P1.27mm
SEM0, SEM101: 74HCT157; SOIC-16_3.9x9.9mm_P1.27mm
U101, U104, U109, U110, U111, U112: 74HCT541; SOIC-20W_7.5x12.8mm_P1.27mm
U102, U103, U105, U106: 74LS08; SOIC-14_3.9x8.7mm_P1.27mm
U107: 74AHCT1G04; TSOP-5_1.65x3.05mm_P0.95mm

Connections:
/CLK: J103.18; also elsewhere on the board
/OUTA0: D101.1 (K), OUTAM0.15 (O0), U101.19 (G2), U104.19 (G2)
/OUTA1: OUTAM0.14 (O1); also elsewhere on the board
/OUTA2: OUTAM0.13 (O2); also elsewhere on the board
/OUTA3: OUTAM0.12 (O3); also elsewhere on the board
/OUTA4: OUTAM0.11 (O4); also elsewhere on the board
/OUTA5: OUTAM0.10 (O5); also elsewhere on the board
/OUTA6: OUTAM0.9 (O6); also elsewhere on the board
/OUTA7: OUTAM0.7 (O7); also elsewhere on the board
/OUTA8: OUTAM1.15 (O0); also elsewhere on the board
/OUTA9: OUTAM1.14 (O1); also elsewhere on the board
/OUTA10: OUTAM1.13 (O2); also elsewhere on the board
/OUTA11: OUTAM1.12 (O3); also elsewhere on the board
/OUTA12: OUTAM1.11 (O4); also elsewhere on the board
/OUTA13: OUTAM1.10 (O5); also elsewhere on the board
/OUTAIDX0: J101.7, OUTAM0.1 (A0), OUTAM1.1 (A0)
/OUTAIDX1: J101.8, OUTAM0.2 (A1), OUTAM1.2 (A1)
/OUTAIDX2: J101.9, OUTAM0.3 (A2), OUTAM1.3 (A2)
/OUTAIDX3: J101.10, OUTAM0.4 (E1), OUTAM1.6 (E3)
/OUTB0: D102.1 (K), OUTBM0.15 (O0), U111.19 (G2), U112.19 (G2)
/OUTB1: OUTBM0.14 (O1); also elsewhere on the board
/OUTB2: OUTBM0.13 (O2); also elsewhere on the board
/OUTB3: OUTBM0.12 (O3); also elsewhere on the board
/OUTB4: OUTBM0.11 (O4); also elsewhere on the board
/OUTB5: OUTBM0.10 (O5); also elsewhere on the board
/OUTB6: OUTBM0.9 (O6); also elsewhere on the board
/OUTB7: OUTBM0.7 (O7); also elsewhere on the board
/OUTB8: OUTBM1.15 (O0); also elsewhere on the board
/OUTB9: OUTBM1.14 (O1); also elsewhere on the board
/OUTB10: OUTBM1.13 (O2); also elsewhere on the board
/OUTB11: OUTBM1.12 (O3); also elsewhere on the board
/OUTB12: OUTBM1.11 (O4); also elsewhere on the board
/OUTB13: OUTBM1.10 (O5); also elsewhere on the board
/OUTBIDX0: J103.10, OUTBM0.1 (A0), OUTBM1.1 (A0)
/OUTBIDX1: J103.11, OUTBM0.2 (A1), OUTBM1.2 (A1)
/OUTBIDX2: J103.12, OUTBM0.3 (A2), OUTBM1.3 (A2)
/OUTBIDX3: J103.13, OUTBM0.4 (E1), OUTBM1.6 (E3)
/RESET: U107.4, U109.19 (G2), U110.19 (G2)
/SET1: RDM0.14 (O1), U102.9
/SET2: RDM0.13 (O2), U102.12
/SET3: RDM0.12 (O3), U102.4
/SET4: RDM0.11 (O4), U102.1
/SET5: RDM0.10 (O5), U103.4
/SET6: RDM0.9 (O6), U103.1
/SET7: RDM0.7 (O7), U103.9
/SET8: RDM1.15 (O0), U103.12
/SET9: RDM1.14 (O1), U105.9
/SET10: RDM1.13 (O2), U105.4
/SET11: RDM1.12 (O3), U105.12
/SET12: RDM1.11 (O4), U105.1
/SET13: RDM1.10 (O5), U106.1
/SETF1: U102.8; also elsewhere on the board
/SETF2: U102.11; also elsewhere on the board
/SETF3: U102.6; also elsewhere on the board
/SETF4: U102.3; also elsewhere on the board
/SETF5: U103.6; also elsewhere on the board
/SETF6: U103.3; also elsewhere on the board
/SETF7: U103.8; also elsewhere on the board
/SETF8: U103.11; also elsewhere on the board
/SETF9: U105.8; also elsewhere on the board
/SETF10: U105.6; also elsewhere on the board
/SETF11: U105.11; also elsewhere on the board
/SETF12: U105.3; also elsewhere on the board
/SETF13: U106.3; also elsewhere on the board
/SETIDX0: J101.2, RDM0.1 (A0), RDM1.1 (A0)
/SETIDX1: J101.3, RDM0.2 (A1), RDM1.2 (A1)
/SETIDX2: J101.4, RDM0.3 (A2), RDM1.3 (A2)
/SETIDX3: J101.5, RDM0.4 (E1), RDM1.6 (E3)
/SIGNBIT: SEM0.2 (I0a), SEM0.5 (I0b), SEM0.11 (I0c), SEM0.14 (I0d), SEM101.2 (I0a), SEM101.5 (I0b), SEM101.11 (I0c), SEM101.14 (I0d), U106.6
/~OUTA: J101.6, OUTAM0.5 (E2), OUTAM1.5 (E2)
/~OUTB: J103.9, OUTBM0.5 (E2), OUTBM1.5 (E2)
/~RESET: D105.1 (K), J103.17, RSTB0.19 (G2), RSTB1.19 (G2), U102.2, U102.5, U102.10, U102.13, U103.2, U103.5, U103.10, U103.13, U105.2, U105.5, U105.10, U105.13, U106.2, U107.2
/~SEBYTE: D104.1 (K), J103.15, SEM0.1 (S), SEM101.1 (S)
/~SET: J101.1, RDM0.5 (E2), RDM1.5 (E2)
/~SEUNSIGNED: D103.1 (K), J103.14, U106.4
BUSA0: J104.1, U101.18 (Y0); also elsewhere on the board
BUSA1: J104.2, U101.17 (Y1); also elsewhere on the board
BUSA2: J104.3, U101.16 (Y2); also elsewhere on the board
BUSA3: J104.4, U101.15 (Y3); also elsewhere on the board
BUSA4: J104.5, U101.14 (Y4); also elsewhere on the board
BUSA5: J104.6, U101.13 (Y5); also elsewhere on the board
BUSA6: J104.7, U101.12 (Y6); also elsewhere on the board
BUSA7: J104.8, U101.11 (Y7); also elsewhere on the board
BUSA8: J101.13, U104.18 (Y0); also elsewhere on the board
BUSA9: J101.14, U104.17 (Y1); also elsewhere on the board
BUSA10: J101.15, U104.16 (Y2); also elsewhere on the board
BUSA11: J101.16, U104.15 (Y3); also elsewhere on the board
BUSA12: J101.17, U104.14 (Y4); also elsewhere on the board
BUSA13: J101.18, U104.13 (Y5); also elsewhere on the board
BUSA14: J101.19, U104.12 (Y6); also elsewhere on the board
BUSA15: J101.20, U104.11 (Y7); also elsewhere on the board
BUSB0: J103.1, U111.18 (Y0); also elsewhere on the board
BUSB1: J103.2, U111.17 (Y1); also elsewhere on the board
BUSB2: J103.3, U111.16 (Y2); also elsewhere on the board
BUSB3: J103.4, U111.15 (Y3); also elsewhere on the board
BUSB4: J103.5, U111.14 (Y4); also elsewhere on the board
BUSB5: J103.6, U111.13 (Y5); also elsewhere on the board
BUSB6: J103.7, U111.12 (Y6); also elsewhere on the board
BUSB7: J103.8, U111.11 (Y7); also elsewhere on the board
BUSB8: J102.13, U112.18 (Y0); also elsewhere on the board
BUSB9: J102.14, U112.17 (Y1); also elsewhere on the board
BUSB10: J102.15, U112.16 (Y2); also elsewhere on the board
BUSB11: J102.16, U112.15 (Y3); also elsewhere on the board
BUSB12: J102.17, U112.14 (Y4); also elsewhere on the board
BUSB13: J102.18, U112.13 (Y5); also elsewhere on the board
BUSB14: J102.19, U112.12 (Y6); also elsewhere on the board
BUSB15: J102.20, U112.11 (Y7); also elsewhere on the board
DATA0: J104.9, U109.2 (A0)
DATA1: J104.10, U109.3 (A1)
DATA2: J104.11, U109.4 (A2)
DATA3: J104.12, U109.5 (A3)
DATA4: J104.13, U109.6 (A4)
DATA5: J104.14, U109.7 (A5)
DATA6: J104.15, U109.8 (A6)
DATA7: J104.16, U106.5, U109.9 (A7)
DATA8: J102.5, SEM0.13 (I1d)
DATA9: J102.6, SEM0.10 (I1c)
DATA10: J102.7, SEM0.6 (I1b)
DATA11: J102.8, SEM0.3 (I1a)
DATA12: J102.9, SEM101.3 (I1a)
DATA13: J102.10, SEM101.6 (I1b)
DATA14: J102.11, SEM101.13 (I1d)
DATA15: J102.12, SEM101.10 (I1c)
DATAINT0: RSTB0.18 (Y0), U109.18 (Y0); also elsewhere on the board
DATAINT1: RSTB0.17 (Y1), U109.17 (Y1); also elsewhere on the board
DATAINT2: RSTB0.16 (Y2), U109.16 (Y2); also elsewhere on the board
DATAINT3: RSTB0.15 (Y3), U109.15 (Y3); also elsewhere on the board
DATAINT4: RSTB0.14 (Y4), U109.14 (Y4); also elsewhere on the board
DATAINT5: RSTB0.13 (Y5), U109.13 (Y5); also elsewhere on the board
DATAINT6: RSTB0.12 (Y6), U109.12 (Y6); also elsewhere on the board
DATAINT7: RSTB0.11 (Y7), U109.11 (Y7); also elsewhere on the board
DATAINT8: RSTB1.11 (Y7), U110.18 (Y0); also elsewhere on the board
DATAINT9: RSTB1.12 (Y6), U110.17 (Y1); also elsewhere on the board
DATAINT10: RSTB1.13 (Y5), U110.16 (Y2); also elsewhere on the board
DATAINT11: RSTB1.14 (Y4), U110.15 (Y3); also elsewhere on the board
DATAINT12: RSTB1.15 (Y3), U110.14 (Y4); also elsewhere on the board
DATAINT13: RSTB1.16 (Y2), U110.13 (Y5); also elsewhere on the board
DATAINT14: RSTB1.17 (Y1), U110.12 (Y6); also elsewhere on the board
DATAINT15: RSTB1.18 (Y0), U110.11 (Y7); also elsewhere on the board
GND: C101.1, C102.1, C103.1, C104.1, C105.1, C106.1, C107.1, C108.1, C109.1, C110.1, C111.1, C112.1, C113.1, C114.1, C115.1, C116.1, C117.1, C118.1, C119.1, C120.1, J102.1, J103.19, OUTAM0.8 (GND), OUTAM1.4 (E1), OUTAM1.8 (GND), OUTBM0.8 (GND), OUTBM1.4 (E1), OUTBM1.8 (GND), RDM0.8 (GND), RDM1.4 (E1), RDM1.8 (GND), RSTB0.1 (G1), RSTB0.2 (A0), RSTB0.3 (A1), RSTB0.4 (A2), RSTB0.5 (A3), RSTB0.6 (A4), RSTB0.7 (A5), RSTB0.8 (A6), RSTB0.9 (A7), RSTB0.10 (GND), RSTB1.1 (G1), RSTB1.2 (A0), RSTB1.3 (A1), RSTB1.4 (A2), RSTB1.5 (A3), RSTB1.6 (A4), RSTB1.7 (A5), RSTB1.8 (A6), RSTB1.9 (A7), RSTB1.10 (GND), SEM0.8 (GND), SEM0.15 (E), SEM101.8 (GND), SEM101.15 (E), U101.1 (G1), U101.2 (A0), U101.3 (A1), U101.4 (A2), U101.5 (A3), U101.6 (A4), U101.7 (A5), U101.8 (A6), U101.9 (A7), U101.10 (GND), U102.7 (GND), U103.7 (GND), U104.1 (G1), U104.2 (A0), U104.3 (A1), U104.4 (A2), U104.5 (A3), U104.6 (A4), U104.7 (A5), U104.8 (A6), U104.9 (A7), U104.10 (GND), U105.7 (GND), U106.7 (GND), U106.9, U106.10, U106.12, U106.13, U107.3 (GND), U109.1 (G1), U109.10 (GND), U110.1 (G1), U110.10 (GND), U111.1 (G1), U111.2 (A0), U111.3 (A1), U111.4 (A2), U111.5 (A3), U111.6 (A4), U111.7 (A5), U111.8 (A6), U111.9 (A7), U111.10 (GND), U112.1 (G1), U112.2 (A0), U112.3 (A1), U112.4 (A2), U112.5 (A3), U112.6 (A4), U112.7 (A5), U112.8 (A6), U112.9 (A7), U112.10 (GND); also elsewhere on the board
unnamed: D101.2 (A), R101.2
unnamed: D102.2 (A), R102.2
unnamed: D103.2 (A), R103.2
unnamed: D104.2 (A), R104.2
unnamed: D105.2 (A), R105.2
unnamed: SEM0.4 (Za), U110.5 (A3)
unnamed: SEM0.7 (Zb), U110.4 (A2)
unnamed: SEM0.9 (Zc), U110.3 (A1)
unnamed: SEM0.12 (Zd), U110.2 (A0)
unnamed: SEM101.4 (Za), U110.6 (A4)
unnamed: SEM101.7 (Zb), U110.7 (A5)
unnamed: SEM101.9 (Zc), U110.8 (A6)
unnamed: SEM101.12 (Zd), U110.9 (A7)
VCC: C101.2, C102.2, C103.2, C104.2, C105.2, C106.2, C107.2, C108.2, C109.2, C110.2, C111.2, C112.2, C113.2, C114.2, C115.2, C116.2, C117.2, C118.2, C119.2, C120.2, J102.2, J103.20, OUTAM0.6 (E3), OUTAM0.16 (VCC), OUTAM1.16 (VCC), OUTBM0.6 (E3), OUTBM0.16 (VCC), OUTBM1.16 (VCC), R101.1, R102.1, R103.1, R104.1, R105.1, RDM0.6 (E3), RDM0.16 (VCC), RDM1.16 (VCC), RSTB0.20 (VCC), RSTB1.20 (VCC), SEM0.16 (VCC), SEM101.16 (VCC), U101.20 (VCC), U102.14 (VCC), U103.14 (VCC), U104.20 (VCC), U105.14 (VCC), U106.14 (VCC), U107.5 (VCC), U109.20 (VCC), U110.20 (VCC), U111.20 (VCC), U112.20 (VCC); also elsewhere on the board

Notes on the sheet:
This group forces the various ~SETFx~ lines to go low during reset, so that the zero values on the data bus are set into the flipflops.

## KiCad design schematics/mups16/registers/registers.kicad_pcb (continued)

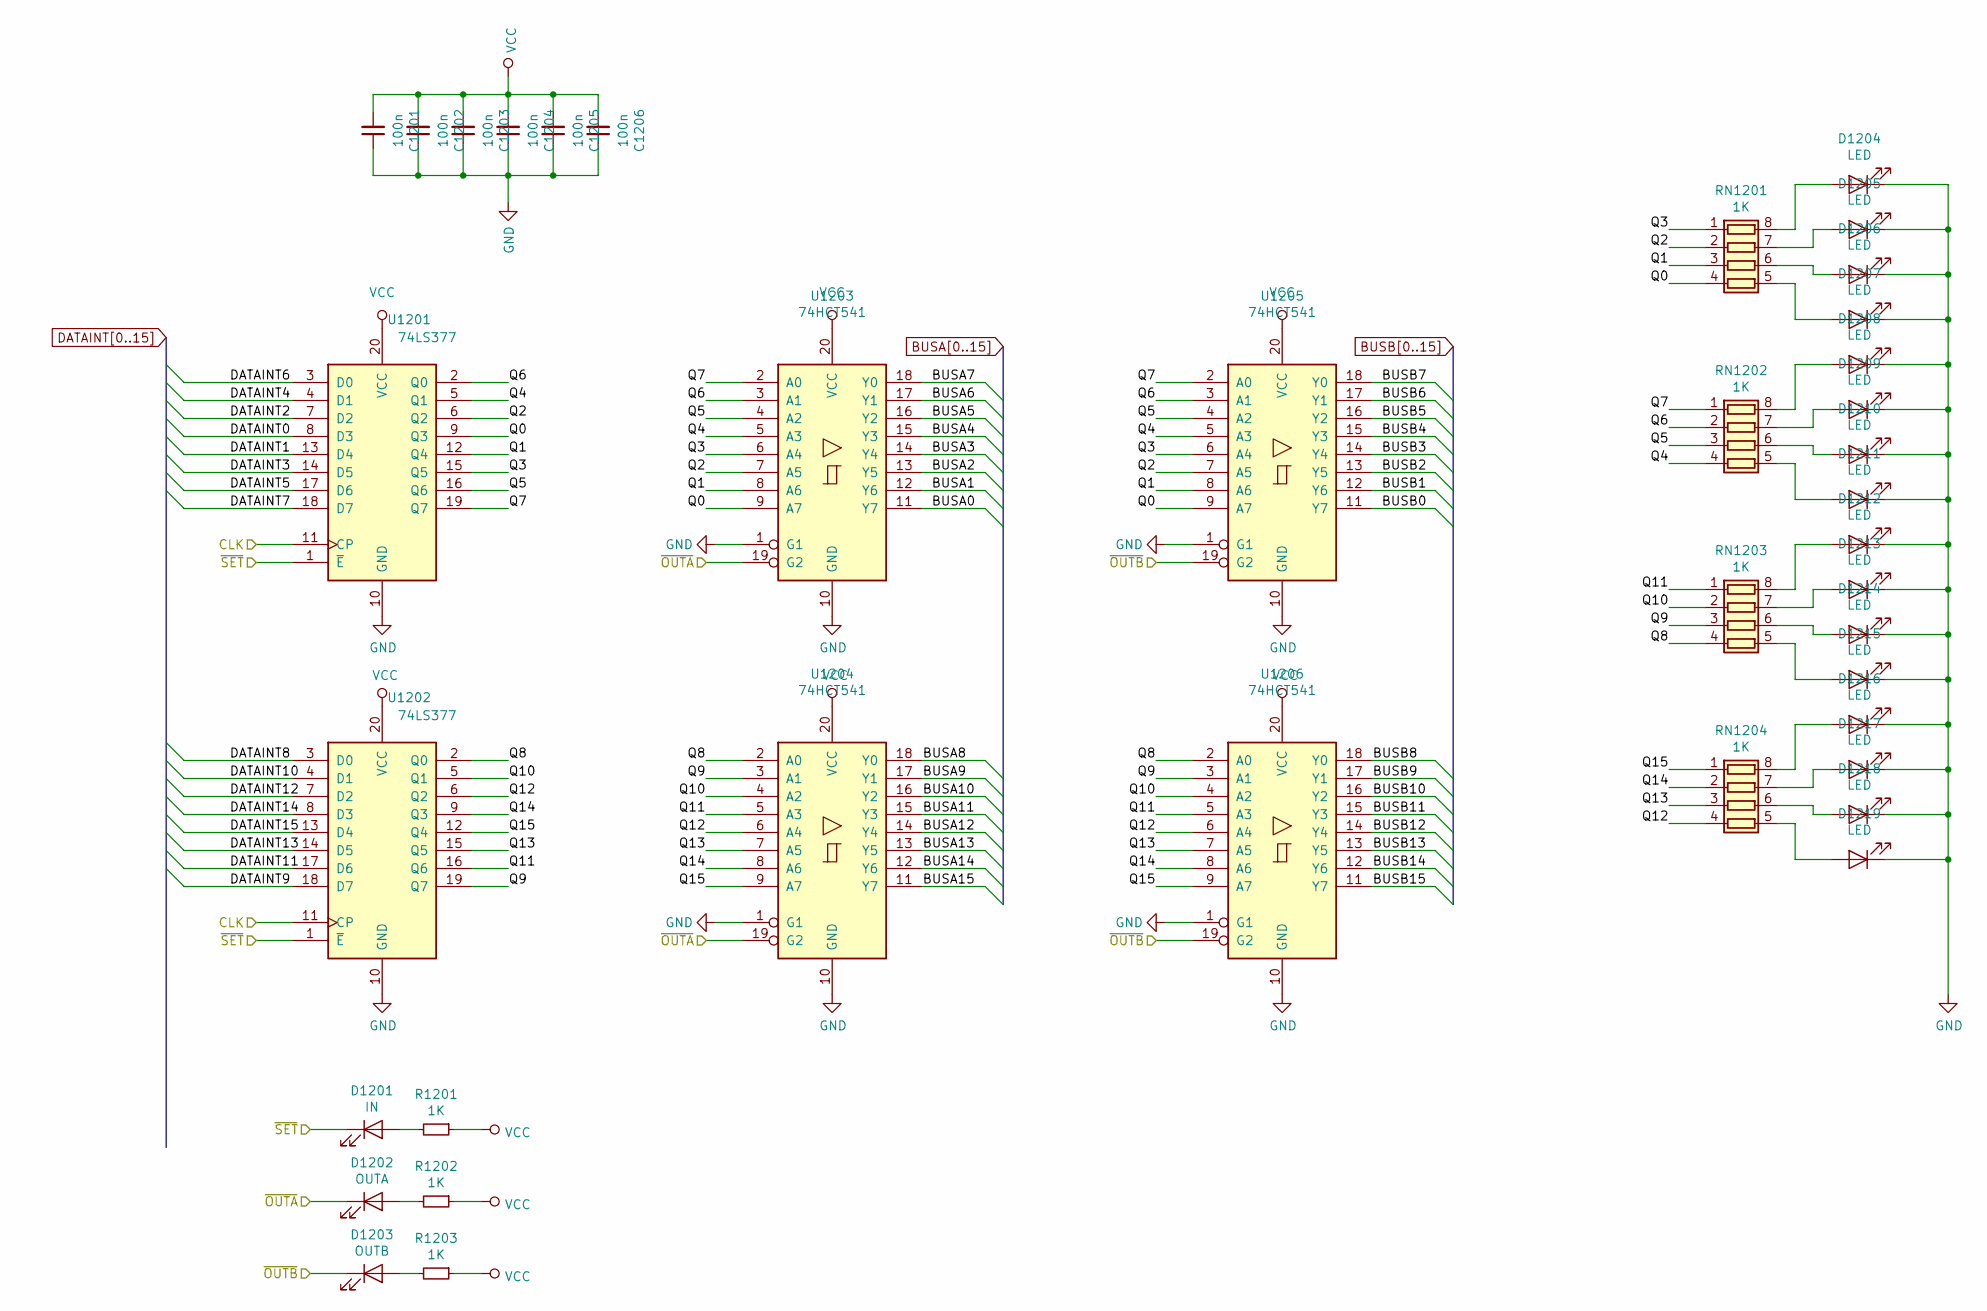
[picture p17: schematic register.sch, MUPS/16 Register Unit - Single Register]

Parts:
C201, C202, C203, C204, C205, C206: 100n; C_0805_2012Metric
D201: IN; LED_0805_2012Metric
D202: OUTA; LED_0805_2012Metric
D203: OUTB; LED_0805_2012Metric
D204, D205, D206, D207, D208, D209, D210, D211, D212, D213, D214, D215, D216, D217, D218, D219: LED; LED_0805_2012Metric
R201, R202, R203: 1K; R_0805_2012Metric
RN201, RN202, RN203, RN204: 1K; R_Array_Convex_4x1206
U201, U202: 74LS377; SOIC-20W_7.5x12.8mm_P1.27mm
U203, U204, U205, U206: 74HCT541; SOIC-20W_7.5x12.8mm_P1.27mm

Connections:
/CLK: U201.11 (CP), U202.11 (CP); also elsewhere on the board
/OUTA1: D202.1 (K), U203.19 (G2), U204.19 (G2); also elsewhere on the board
/OUTB1: D203.1 (K), U205.19 (G2), U206.19 (G2); also elsewhere on the board
/SETF1: D201.1 (K), U201.1 (~E), U202.1 (~E); also elsewhere on the board
/r1/Q0: RN201.4 (R4.1), U201.9 (Q3), U203.9 (A7), U205.9 (A7)
/r1/Q1: RN201.3 (R3.1), U201.12 (Q4), U203.8 (A6), U205.8 (A6)
/r1/Q2: RN201.2 (R2.1), U201.6 (Q2), U203.7 (A5), U205.7 (A5)
/r1/Q3: RN201.1 (R1.1), U201.15 (Q5), U203.6 (A4), U205.6 (A4)
/r1/Q4: RN202.4 (R4.1), U201.5 (Q1), U203.5 (A3), U205.5 (A3)
/r1/Q5: RN202.3 (R3.1), U201.16 (Q6), U203.4 (A2), U205.4 (A2)
/r1/Q6: RN202.2 (R2.1), U201.2 (Q0), U203.3 (A1), U205.3 (A1)
/r1/Q7: RN202.1 (R1.1), U201.19 (Q7), U203.2 (A0), U205.2 (A0)
/r1/Q8: RN203.4 (R4.1), U202.2 (Q0), U204.2 (A0), U206.2 (A0)
/r1/Q9: RN203.3 (R3.1), U202.19 (Q7), U204.3 (A1), U206.3 (A1)
/r1/Q10: RN203.2 (R2.1), U202.5 (Q1), U204.4 (A2), U206.4 (A2)
/r1/Q11: RN203.1 (R1.1), U202.16 (Q6), U204.5 (A3), U206.5 (A3)
/r1/Q12: RN204.4 (R4.1), U202.6 (Q2), U204.6 (A4), U206.6 (A4)
/r1/Q13: RN204.3 (R3.1), U202.15 (Q5), U204.7 (A5), U206.7 (A5)
/r1/Q14: RN204.2 (R2.1), U202.9 (Q3), U204.8 (A6), U206.8 (A6)
/r1/Q15: RN204.1 (R1.1), U202.12 (Q4), U204.9 (A7), U206.9 (A7)
BUSA0: U203.11 (Y7); also elsewhere on the board
BUSA1: U203.12 (Y6); also elsewhere on the board
BUSA2: U203.13 (Y5); also elsewhere on the board
BUSA3: U203.14 (Y4); also elsewhere on the board
BUSA4: U203.15 (Y3); also elsewhere on the board
BUSA5: U203.16 (Y2); also elsewhere on the board
BUSA6: U203.17 (Y1); also elsewhere on the board
BUSA7: U203.18 (Y0); also elsewhere on the board
BUSA8: U204.18 (Y0); also elsewhere on the board
BUSA9: U204.17 (Y1); also elsewhere on the board
BUSA10: U204.16 (Y2); also elsewhere on the board
BUSA11: U204.15 (Y3); also elsewhere on the board
BUSA12: U204.14 (Y4); also elsewhere on the board
BUSA13: U204.13 (Y5); also elsewhere on the board
BUSA14: U204.12 (Y6); also elsewhere on the board
BUSA15: U204.11 (Y7); also elsewhere on the board
BUSB0: U205.11 (Y7); also elsewhere on the board
BUSB1: U205.12 (Y6); also elsewhere on the board
BUSB2: U205.13 (Y5); also elsewhere on the board
BUSB3: U205.14 (Y4); also elsewhere on the board
BUSB4: U205.15 (Y3); also elsewhere on the board
BUSB5: U205.16 (Y2); also elsewhere on the board
BUSB6: U205.17 (Y1); also elsewhere on the board
BUSB7: U205.18 (Y0); also elsewhere on the board
BUSB8: U206.18 (Y0); also elsewhere on the board
BUSB9: U206.17 (Y1); also elsewhere on the board
BUSB10: U206.16 (Y2); also elsewhere on the board
BUSB11: U206.15 (Y3); also elsewhere on the board
BUSB12: U206.14 (Y4); also elsewhere on the board
BUSB13: U206.13 (Y5); also elsewhere on the board
BUSB14: U206.12 (Y6); also elsewhere on the board
BUSB15: U206.11 (Y7); also elsewhere on the board
DATAINT0: U201.8 (D3); also elsewhere on the board
DATAINT1: U201.13 (D4); also elsewhere on the board
DATAINT2: U201.7 (D2); also elsewhere on the board
DATAINT3: U201.14 (D5); also elsewhere on the board
DATAINT4: U201.4 (D1); also elsewhere on the board
DATAINT5: U201.17 (D6); also elsewhere on the board
DATAINT6: U201.3 (D0); also elsewhere on the board
DATAINT7: U201.18 (D7); also elsewhere on the board
DATAINT8: U202.3 (D0); also elsewhere on the board
DATAINT9: U202.18 (D7); also elsewhere on the board
DATAINT10: U202.4 (D1); also elsewhere on the board
DATAINT11: U202.17 (D6); also elsewhere on the board
DATAINT12: U202.7 (D2); also elsewhere on the board
DATAINT13: U202.14 (D5); also elsewhere on the board
DATAINT14: U202.8 (D3); also elsewhere on the board
DATAINT15: U202.13 (D4); also elsewhere on the board
GND: C201.1, C202.1, C203.1, C204.1, C205.1, C206.1, D204.1 (K), D205.1 (K), D206.1 (K), D207.1 (K), D208.1 (K), D209.1 (K), D210.1 (K), D211.1 (K), D212.1 (K), D213.1 (K), D214.1 (K), D215.1 (K), D216.1 (K), D217.1 (K), D218.1 (K), D219.1 (K), U201.10 (GND), U202.10 (GND), U203.1 (G1), U203.10 (GND), U204.1 (G1), U204.10 (GND), U205.1 (G1), U205.10 (GND), U206.1 (G1), U206.10 (GND); also elsewhere on the board
unnamed: D201.2 (A), R201.2
unnamed: D202.2 (A), R202.2
unnamed: D203.2 (A), R203.2
unnamed: D204.2 (A), RN201.8 (R1.2)
unnamed: D205.2 (A), RN201.7 (R2.2)
unnamed: D206.2 (A), RN201.6 (R3.2)
unnamed: D207.2 (A), RN201.5 (R4.2)
unnamed: D208.2 (A), RN202.8 (R1.2)
unnamed: D209.2 (A), RN202.7 (R2.2)
unnamed: D210.2 (A), RN202.6 (R3.2)
unnamed: D211.2 (A), RN202.5 (R4.2)
unnamed: D212.2 (A), RN203.8 (R1.2)
unnamed: D213.2 (A), RN203.7 (R2.2)
unnamed: D214.2 (A), RN203.6 (R3.2)
unnamed: D215.2 (A), RN203.5 (R4.2)
unnamed: D216.2 (A), RN204.8 (R1.2)
unnamed: D217.2 (A), RN204.7 (R2.2)
unnamed: D218.2 (A), RN204.6 (R3.2)
unnamed: D219.2 (A), RN204.5 (R4.2)
VCC: C201.2, C202.2, C203.2, C204.2, C205.2, C206.2, R201.1, R202.1, R203.1, U201.20 (VCC), U202.20 (VCC), U203.20 (VCC), U204.20 (VCC), U205.20 (VCC), U206.20 (VCC); also elsewhere on the board

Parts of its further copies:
C301, C302, C303, C304, C305, C306, C401, C402, C403, C404, C405, C406, C501, C502, C503, C504, C505, C506, C601, C602, C603, C604, C605, C606, C701, C702, C703, C704, C705, C706, C801, C802, C803, C804, C805, C806, C901, C902, C903, C904, C905, C906, C1001, C1002, C1003, C1004, C1005, C1006, C1101, C1102, C1103, C1104, C1105, C1106, C1201, C1202, C1203, C1204, C1205, C1206, C1301, C1302, C1303, C1304, C1305, C1306, C1401, C1402, C1403, C1404, C1405, C1406: 100n; C_0805_2012Metric
D301, D401, D501, D601, D701, D801, D901, D1001, D1101, D1201, D1301, D1401: IN; LED_0805_2012Metric
D302, D402, D502, D602, D702, D802, D902, D1002, D1102, D1202, D1302, D1402: OUTA; LED_0805_2012Metric
D303, D403, D503, D603, D703, D803, D903, D1003, D1103, D1203, D1303, D1403: OUTB; LED_0805_2012Metric
D304, D305, D306, D307, D308, D309, D310, D311, D312, D313, D314, D315, D316, D317, D318, D319, D404, D405, D406, D407, D408, D409, D410, D411, D412, D413, D414, D415, D416, D417, D418, D419, D504, D505, D506, D507, D508, D509, D510, D511, D512, D513, D514, D515, D516, D517, D518, D519, D604, D605, D606, D607, D608, D609, D610, D611, D612, D613, D614, D615, D616, D617, D618, D619, D704, D705, D706, D707, D708, D709, D710, D711, D712, D713, D714, D715, D716, D717, D718, D719, D804, D805, D806, D807, D808, D809, D810, D811, D812, D813, D814, D815, D816, D817, D818, D819, D904, D905, D906, D907, D908, D909, D910, D911, D912, D913, D914, D915, D916, D917, D918, D919, D1004, D1005, D1006, D1007, D1008, D1009, D1010, D1011, D1012, D1013, D1014, D1015, D1016, D1017, D1018, D1019, D1104, D1105, D1106, D1107, D1108, D1109, D1110, D1111, D1112, D1113, D1114, D1115, D1116, D1117, D1118, D1119, D1204, D1205, D1206, D1207, D1208, D1209, D1210, D1211, D1212, D1213, D1214, D1215, D1216, D1217, D1218, D1219, D1304, D1305, D1306, D1307, D1308, D1309, D1310, D1311, D1312, D1313, D1314, D1315, D1316, D1317, D1318, D1319, D1404, D1405, D1406, D1407, D1408, D1409, D1410, D1411, D1412, D1413, D1414, D1415, D1416, D1417, D1418, D1419: LED; LED_0805_2012Metric
R301, R302, R303, R401, R402, R403, R501, R502, R503, R601, R602, R603, R701, R702, R703, R801, R802, R803, R901, R902, R903, R1001, R1002, R1003, R1101, R1102, R1103, R1201, R1202, R1203, R1301, R1302, R1303, R1401, R1402, R1403: 1K; R_0805_2012Metric
RN301, RN302, RN303, RN304, RN401, RN402, RN403, RN404, RN501, RN502, RN503, RN504, RN601, RN602, RN603, RN604, RN701, RN702, RN703, RN704, RN801, RN802, RN803, RN804, RN901, RN902, RN903, RN904, RN1001, RN1002, RN1003, RN1004, RN1101, RN1102, RN1103, RN1104, RN1201, RN1202, RN1203, RN1204, RN1301, RN1302, RN1303, RN1304, RN1401, RN1402, RN1403, RN1404: 1K; R_Array_Convex_4x1206
U301, U302, U401, U402, U501, U502, U601, U602, U701, U702, U801, U802, U901, U902, U1001, U1002, U1101, U1102, U1201, U1202, U1301, U1302, U1401, U1402: 74LS377; SOIC-20W_7.5x12.8mm_P1.27mm
U303, U304, U305, U306, U403, U404, U405, U406, U503, U504, U505, U506, U603, U604, U605, U606, U703, U704, U705, U706, U803, U804, U805, U806, U903, U904, U905, U906, U1003, U1004, U1005, U1006, U1103, U1104, U1105, U1106, U1203, U1204, U1205, U1206, U1303, U1304, U1305, U1306, U1403, U1404, U1405, U1406: 74HCT541; SOIC-20W_7.5x12.8mm_P1.27mm

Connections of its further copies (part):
/CLK: U301.11 (CP), U302.11 (CP), U401.11 (CP), U402.11 (CP), U501.11 (CP), U502.11 (CP), U601.11 (CP), U602.11 (CP), U701.11 (CP), U702.11 (CP), U801.11 (CP), U802.11 (CP), U901.11 (CP), U902.11 (CP), U1001.11 (CP), U1002.11 (CP), U1101.11 (CP), U1102.11 (CP), U1201.11 (CP), U1202.11 (CP), U1301.11 (CP), U1302.11 (CP), U1401.11 (CP), U1402.11 (CP); also elsewhere on the board
/OUTA2: D302.1 (K), U303.19 (G2), U304.19 (G2); also elsewhere on the board
/OUTA3: D1102.1 (K), U1103.19 (G2), U1104.19 (G2); also elsewhere on the board
/OUTA4: D1202.1 (K), U1203.19 (G2), U1204.19 (G2); also elsewhere on the board
/OUTA5: D402.1 (K), U403.19 (G2), U404.19 (G2); also elsewhere on the board
/OUTA6: D502.1 (K), U503.19 (G2), U504.19 (G2); also elsewhere on the board
/OUTA7: D602.1 (K), U603.19 (G2), U604.19 (G2); also elsewhere on the board
/OUTA8: D702.1 (K), U703.19 (G2), U704.19 (G2); also elsewhere on the board
/OUTA9: D802.1 (K), U803.19 (G2), U804.19 (G2); also elsewhere on the board
/OUTA10: D902.1 (K), U903.19 (G2), U904.19 (G2); also elsewhere on the board
/OUTA11: D1002.1 (K), U1003.19 (G2), U1004.19 (G2); also elsewhere on the board
/OUTA12: D1302.1 (K), U1303.19 (G2), U1304.19 (G2); also elsewhere on the board
/OUTA13: D1402.1 (K), U1403.19 (G2), U1404.19 (G2); also elsewhere on the board
/OUTB2: D303.1 (K), U305.19 (G2), U306.19 (G2); also elsewhere on the board
/OUTB3: D1103.1 (K), U1105.19 (G2), U1106.19 (G2); also elsewhere on the board
/OUTB4: D1203.1 (K), U1205.19 (G2), U1206.19 (G2); also elsewhere on the board
/OUTB5: D403.1 (K), U405.19 (G2), U406.19 (G2); also elsewhere on the board
/OUTB6: D503.1 (K), U505.19 (G2), U506.19 (G2); also elsewhere on the board
/OUTB7: D603.1 (K), U605.19 (G2), U606.19 (G2); also elsewhere on the board
/OUTB8: D703.1 (K), U705.19 (G2), U706.19 (G2); also elsewhere on the board
/OUTB9: D803.1 (K), U805.19 (G2), U806.19 (G2); also elsewhere on the board
/OUTB10: D903.1 (K), U905.19 (G2), U906.19 (G2); also elsewhere on the board
/OUTB11: D1003.1 (K), U1005.19 (G2), U1006.19 (G2); also elsewhere on the board
/OUTB12: D1303.1 (K), U1305.19 (G2), U1306.19 (G2); also elsewhere on the board
/OUTB13: D1403.1 (K), U1405.19 (G2), U1406.19 (G2); also elsewhere on the board
/SETF2: D301.1 (K), U301.1 (~E), U302.1 (~E); also elsewhere on the board
/SETF3: D1101.1 (K), U1101.1 (~E), U1102.1 (~E); also elsewhere on the board
/SETF4: D1201.1 (K), U1201.1 (~E), U1202.1 (~E); also elsewhere on the board
/SETF5: D401.1 (K), U401.1 (~E), U402.1 (~E); also elsewhere on the board
/SETF6: D501.1 (K), U501.1 (~E), U502.1 (~E); also elsewhere on the board
/SETF7: D601.1 (K), U601.1 (~E), U602.1 (~E); also elsewhere on the board
/SETF8: D701.1 (K), U701.1 (~E), U702.1 (~E); also elsewhere on the board
/SETF9: D801.1 (K), U801.1 (~E), U802.1 (~E); also elsewhere on the board
/SETF10: D901.1 (K), U901.1 (~E), U902.1 (~E); also elsewhere on the board
/SETF11: D1001.1 (K), U1001.1 (~E), U1002.1 (~E); also elsewhere on the board
/SETF12: D1301.1 (K), U1301.1 (~E), U1302.1 (~E); also elsewhere on the board
/SETF13: D1401.1 (K), U1401.1 (~E), U1402.1 (~E); also elsewhere on the board
/pc/Q0: RN501.4 (R4.1), U501.9 (Q3), U503.9 (A7), U505.9 (A7)
/pc/Q1: RN501.3 (R3.1), U501.12 (Q4), U503.8 (A6), U505.8 (A6)
/pc/Q2: RN501.2 (R2.1), U501.6 (Q2), U503.7 (A5), U505.7 (A5)
/pc/Q3: RN501.1 (R1.1), U501.15 (Q5), U503.6 (A4), U505.6 (A4)
/pc/Q4: RN502.4 (R4.1), U501.5 (Q1), U503.5 (A3), U505.5 (A3)
/pc/Q5: RN502.3 (R3.1), U501.16 (Q6), U503.4 (A2), U505.4 (A2)
/pc/Q6: RN502.2 (R2.1), U501.2 (Q0), U503.3 (A1), U505.3 (A1)
/pc/Q7: RN502.1 (R1.1), U501.19 (Q7), U503.2 (A0), U505.2 (A0)
/pc/Q8: RN503.4 (R4.1), U502.2 (Q0), U504.2 (A0), U506.2 (A0)
/pc/Q9: RN503.3 (R3.1), U502.19 (Q7), U504.3 (A1), U506.3 (A1)
/pc/Q10: RN503.2 (R2.1), U502.5 (Q1), U504.4 (A2), U506.4 (A2)
/pc/Q11: RN503.1 (R1.1), U502.16 (Q6), U504.5 (A3), U506.5 (A3)
/pc/Q12: RN504.4 (R4.1), U502.6 (Q2), U504.6 (A4), U506.6 (A4)
/pc/Q13: RN504.3 (R3.1), U502.15 (Q5), U504.7 (A5), U506.7 (A5)
/pc/Q14: RN504.2 (R2.1), U502.9 (Q3), U504.8 (A6), U506.8 (A6)
/pc/Q15: RN504.1 (R1.1), U502.12 (Q4), U504.9 (A7), U506.9 (A7)
/r2/Q0: RN301.4 (R4.1), U301.9 (Q3), U303.9 (A7), U305.9 (A7)
/r2/Q1: RN301.3 (R3.1), U301.12 (Q4), U303.8 (A6), U305.8 (A6)
/r2/Q2: RN301.2 (R2.1), U301.6 (Q2), U303.7 (A5), U305.7 (A5)
/r2/Q3: RN301.1 (R1.1), U301.15 (Q5), U303.6 (A4), U305.6 (A4)
/r2/Q4: RN302.4 (R4.1), U301.5 (Q1), U303.5 (A3), U305.5 (A3)
/r2/Q5: RN302.3 (R3.1), U301.16 (Q6), U303.4 (A2), U305.4 (A2)
/r2/Q6: RN302.2 (R2.1), U301.2 (Q0), U303.3 (A1), U305.3 (A1)
/r2/Q7: RN302.1 (R1.1), U301.19 (Q7), U303.2 (A0), U305.2 (A0)
/r2/Q8: RN303.4 (R4.1), U302.2 (Q0), U304.2 (A0), U306.2 (A0)
/r2/Q9: RN303.3 (R3.1), U302.19 (Q7), U304.3 (A1), U306.3 (A1)
/r2/Q10: RN303.2 (R2.1), U302.5 (Q1), U304.4 (A2), U306.4 (A2)
/r2/Q11: RN303.1 (R1.1), U302.16 (Q6), U304.5 (A3), U306.5 (A3)
/r2/Q12: RN304.4 (R4.1), U302.6 (Q2), U304.6 (A4), U306.6 (A4)
/r2/Q13: RN304.3 (R3.1), U302.15 (Q5), U304.7 (A5), U306.7 (A5)
/r2/Q14: RN304.2 (R2.1), U302.9 (Q3), U304.8 (A6), U306.8 (A6)
/r2/Q15: RN304.1 (R1.1), U302.12 (Q4), U304.9 (A7), U306.9 (A7)
/r3/Q0: RN1101.4 (R4.1), U1101.9 (Q3), U1103.9 (A7), U1105.9 (A7)
/r3/Q1: RN1101.3 (R3.1), U1101.12 (Q4), U1103.8 (A6), U1105.8 (A6)
/r3/Q2: RN1101.2 (R2.1), U1101.6 (Q2), U1103.7 (A5), U1105.7 (A5)
/r3/Q3: RN1101.1 (R1.1), U1101.15 (Q5), U1103.6 (A4), U1105.6 (A4)
/r3/Q4: RN1102.4 (R4.1), U1101.5 (Q1), U1103.5 (A3), U1105.5 (A3)
/r3/Q5: RN1102.3 (R3.1), U1101.16 (Q6), U1103.4 (A2), U1105.4 (A2)
/r3/Q6: RN1102.2 (R2.1), U1101.2 (Q0), U1103.3 (A1), U1105.3 (A1)
/r3/Q7: RN1102.1 (R1.1), U1101.19 (Q7), U1103.2 (A0), U1105.2 (A0)
/r3/Q8: RN1103.4 (R4.1), U1102.2 (Q0), U1104.2 (A0), U1106.2 (A0)
/r3/Q9: RN1103.3 (R3.1), U1102.19 (Q7), U1104.3 (A1), U1106.3 (A1)
/r3/Q10: RN1103.2 (R2.1), U1102.5 (Q1), U1104.4 (A2), U1106.4 (A2)
/r3/Q11: RN1103.1 (R1.1), U1102.16 (Q6), U1104.5 (A3), U1106.5 (A3)
/r3/Q12: RN1104.4 (R4.1), U1102.6 (Q2), U1104.6 (A4), U1106.6 (A4)
/r3/Q13: RN1104.3 (R3.1), U1102.15 (Q5), U1104.7 (A5), U1106.7 (A5)
/r3/Q14: RN1104.2 (R2.1), U1102.9 (Q3), U1104.8 (A6), U1106.8 (A6)
/r3/Q15: RN1104.1 (R1.1), U1102.12 (Q4), U1104.9 (A7), U1106.9 (A7)
/r4/Q0: RN1201.4 (R4.1), U1201.9 (Q3), U1203.9 (A7), U1205.9 (A7)
/r4/Q1: RN1201.3 (R3.1), U1201.12 (Q4), U1203.8 (A6), U1205.8 (A6)
/r4/Q2: RN1201.2 (R2.1), U1201.6 (Q2), U1203.7 (A5), U1205.7 (A5)
/r4/Q3: RN1201.1 (R1.1), U1201.15 (Q5), U1203.6 (A4), U1205.6 (A4)
/r4/Q4: RN1202.4 (R4.1), U1201.5 (Q1), U1203.5 (A3), U1205.5 (A3)
/r4/Q5: RN1202.3 (R3.1), U1201.16 (Q6), U1203.4 (A2), U1205.4 (A2)
/r4/Q6: RN1202.2 (R2.1), U1201.2 (Q0), U1203.3 (A1), U1205.3 (A1)
/r4/Q7: RN1202.1 (R1.1), U1201.19 (Q7), U1203.2 (A0), U1205.2 (A0)
/r4/Q8: RN1203.4 (R4.1), U1202.2 (Q0), U1204.2 (A0), U1206.2 (A0)
/r4/Q9: RN1203.3 (R3.1), U1202.19 (Q7), U1204.3 (A1), U1206.3 (A1)
/r4/Q10: RN1203.2 (R2.1), U1202.5 (Q1), U1204.4 (A2), U1206.4 (A2)
/r4/Q11: RN1203.1 (R1.1), U1202.16 (Q6), U1204.5 (A3), U1206.5 (A3)
/r4/Q12: RN1204.4 (R4.1), U1202.6 (Q2), U1204.6 (A4), U1206.6 (A4)
/r4/Q13: RN1204.3 (R3.1), U1202.15 (Q5), U1204.7 (A5), U1206.7 (A5)
/r4/Q14: RN1204.2 (R2.1), U1202.9 (Q3), U1204.8 (A6), U1206.8 (A6)
/r4/Q15: RN1204.1 (R1.1), U1202.12 (Q4), U1204.9 (A7), U1206.9 (A7)
/ra/Q0: RN601.4 (R4.1), U601.9 (Q3), U603.9 (A7), U605.9 (A7)
/ra/Q1: RN601.3 (R3.1), U601.12 (Q4), U603.8 (A6), U605.8 (A6)
/ra/Q2: RN601.2 (R2.1), U601.6 (Q2), U603.7 (A5), U605.7 (A5)
/ra/Q3: RN601.1 (R1.1), U601.15 (Q5), U603.6 (A4), U605.6 (A4)
/ra/Q4: RN602.4 (R4.1), U601.5 (Q1), U603.5 (A3), U605.5 (A3)
/ra/Q5: RN602.3 (R3.1), U601.16 (Q6), U603.4 (A2), U605.4 (A2)
/ra/Q6: RN602.2 (R2.1), U601.2 (Q0), U603.3 (A1), U605.3 (A1)
/ra/Q7: RN602.1 (R1.1), U601.19 (Q7), U603.2 (A0), U605.2 (A0)
/ra/Q8: RN603.4 (R4.1), U602.2 (Q0), U604.2 (A0), U606.2 (A0)
/ra/Q9: RN603.3 (R3.1), U602.19 (Q7), U604.3 (A1), U606.3 (A1)
/ra/Q10: RN603.2 (R2.1), U602.5 (Q1), U604.4 (A2), U606.4 (A2)
/ra/Q11: RN603.1 (R1.1), U602.16 (Q6), U604.5 (A3), U606.5 (A3)
/ra/Q12: RN604.4 (R4.1), U602.6 (Q2), U604.6 (A4), U606.6 (A4)
/ra/Q13: RN604.3 (R3.1), U602.15 (Q5), U604.7 (A5), U606.7 (A5)
/ra/Q14: RN604.2 (R2.1), U602.9 (Q3), U604.8 (A6), U606.8 (A6)
/ra/Q15: RN604.1 (R1.1), U602.12 (Q4), U604.9 (A7), U606.9 (A7)
/s1/Q0: RN801.4 (R4.1), U801.9 (Q3), U803.9 (A7), U805.9 (A7)
/s1/Q1: RN801.3 (R3.1), U801.12 (Q4), U803.8 (A6), U805.8 (A6)
/s1/Q2: RN801.2 (R2.1), U801.6 (Q2), U803.7 (A5), U805.7 (A5)
/s1/Q3: RN801.1 (R1.1), U801.15 (Q5), U803.6 (A4), U805.6 (A4)
/s1/Q4: RN802.4 (R4.1), U801.5 (Q1), U803.5 (A3), U805.5 (A3)
/s1/Q5: RN802.3 (R3.1), U801.16 (Q6), U803.4 (A2), U805.4 (A2)
/s1/Q6: RN802.2 (R2.1), U801.2 (Q0), U803.3 (A1), U805.3 (A1)
/s1/Q7: RN802.1 (R1.1), U801.19 (Q7), U803.2 (A0), U805.2 (A0)
/s1/Q8: RN803.4 (R4.1), U802.2 (Q0), U804.2 (A0), U806.2 (A0)
/s1/Q9: RN803.3 (R3.1), U802.19 (Q7), U804.3 (A1), U806.3 (A1)
/s1/Q10: RN803.2 (R2.1), U802.5 (Q1), U804.4 (A2), U806.4 (A2)
/s1/Q11: RN803.1 (R1.1), U802.16 (Q6), U804.5 (A3), U806.5 (A3)
/s1/Q12: RN804.4 (R4.1), U802.6 (Q2), U804.6 (A4), U806.6 (A4)
/s1/Q13: RN804.3 (R3.1), U802.15 (Q5), U804.7 (A5), U806.7 (A5)
/s1/Q14: RN804.2 (R2.1), U802.9 (Q3), U804.8 (A6), U806.8 (A6)
/s1/Q15: RN804.1 (R1.1), U802.12 (Q4), U804.9 (A7), U806.9 (A7)
/s2/Q0: RN901.4 (R4.1), U901.9 (Q3), U903.9 (A7), U905.9 (A7)
/s2/Q1: RN901.3 (R3.1), U901.12 (Q4), U903.8 (A6), U905.8 (A6)
/s2/Q2: RN901.2 (R2.1), U901.6 (Q2), U903.7 (A5), U905.7 (A5)
/s2/Q3: RN901.1 (R1.1), U901.15 (Q5), U903.6 (A4), U905.6 (A4)
/s2/Q4: RN902.4 (R4.1), U901.5 (Q1), U903.5 (A3), U905.5 (A3)
/s2/Q5: RN902.3 (R3.1), U901.16 (Q6), U903.4 (A2), U905.4 (A2)
/s2/Q6: RN902.2 (R2.1), U901.2 (Q0), U903.3 (A1), U905.3 (A1)
/s2/Q7: RN902.1 (R1.1), U901.19 (Q7), U903.2 (A0), U905.2 (A0)
/s2/Q8: RN903.4 (R4.1), U902.2 (Q0), U904.2 (A0), U906.2 (A0)
/s2/Q9: RN903.3 (R3.1), U902.19 (Q7), U904.3 (A1), U906.3 (A1)
/s2/Q10: RN903.2 (R2.1), U902.5 (Q1), U904.4 (A2), U906.4 (A2)
/s2/Q11: RN903.1 (R1.1), U902.16 (Q6), U904.5 (A3), U906.5 (A3)
/s2/Q12: RN904.4 (R4.1), U902.6 (Q2), U904.6 (A4), U906.6 (A4)
/s2/Q13: RN904.3 (R3.1), U902.15 (Q5), U904.7 (A5), U906.7 (A5)
/s2/Q14: RN904.2 (R2.1), U902.9 (Q3), U904.8 (A6), U906.8 (A6)
/s2/Q15: RN904.1 (R1.1), U902.12 (Q4), U904.9 (A7), U906.9 (A7)
/s3/Q0: RN1001.4 (R4.1), U1001.9 (Q3), U1003.9 (A7), U1005.9 (A7)
/s3/Q1: RN1001.3 (R3.1), U1001.12 (Q4), U1003.8 (A6), U1005.8 (A6)
/s3/Q2: RN1001.2 (R2.1), U1001.6 (Q2), U1003.7 (A5), U1005.7 (A5)
/s3/Q3: RN1001.1 (R1.1), U1001.15 (Q5), U1003.6 (A4), U1005.6 (A4)
/s3/Q4: RN1002.4 (R4.1), U1001.5 (Q1), U1003.5 (A3), U1005.5 (A3)
/s3/Q5: RN1002.3 (R3.1), U1001.16 (Q6), U1003.4 (A2), U1005.4 (A2)
/s3/Q6: RN1002.2 (R2.1), U1001.2 (Q0), U1003.3 (A1), U1005.3 (A1)
/s3/Q7: RN1002.1 (R1.1), U1001.19 (Q7), U1003.2 (A0), U1005.2 (A0)
/s3/Q8: RN1003.4 (R4.1), U1002.2 (Q0), U1004.2 (A0), U1006.2 (A0)
/s3/Q9: RN1003.3 (R3.1), U1002.19 (Q7), U1004.3 (A1), U1006.3 (A1)
/s3/Q10: RN1003.2 (R2.1), U1002.5 (Q1), U1004.4 (A2), U1006.4 (A2)
/s3/Q11: RN1003.1 (R1.1), U1002.16 (Q6), U1004.5 (A3), U1006.5 (A3)
/s3/Q12: RN1004.4 (R4.1), U1002.6 (Q2), U1004.6 (A4), U1006.6 (A4)
/s3/Q13: RN1004.3 (R3.1), U1002.15 (Q5), U1004.7 (A5), U1006.7 (A5)
/s3/Q14: RN1004.2 (R2.1), U1002.9 (Q3), U1004.8 (A6), U1006.8 (A6)
/s3/Q15: RN1004.1 (R1.1), U1002.12 (Q4), U1004.9 (A7), U1006.9 (A7)
/sp/Q0: RN401.4 (R4.1), U401.9 (Q3), U403.9 (A7), U405.9 (A7)
/sp/Q1: RN401.3 (R3.1), U401.12 (Q4), U403.8 (A6), U405.8 (A6)
/sp/Q2: RN401.2 (R2.1), U401.6 (Q2), U403.7 (A5), U405.7 (A5)
/sp/Q3: RN401.1 (R1.1), U401.15 (Q5), U403.6 (A4), U405.6 (A4)
/sp/Q4: RN402.4 (R4.1), U401.5 (Q1), U403.5 (A3), U405.5 (A3)
/sp/Q5: RN402.3 (R3.1), U401.16 (Q6), U403.4 (A2), U405.4 (A2)
/sp/Q6: RN402.2 (R2.1), U401.2 (Q0), U403.3 (A1), U405.3 (A1)
/sp/Q7: RN402.1 (R1.1), U401.19 (Q7), U403.2 (A0), U405.2 (A0)
/sp/Q8: RN403.4 (R4.1), U402.2 (Q0), U404.2 (A0), U406.2 (A0)
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

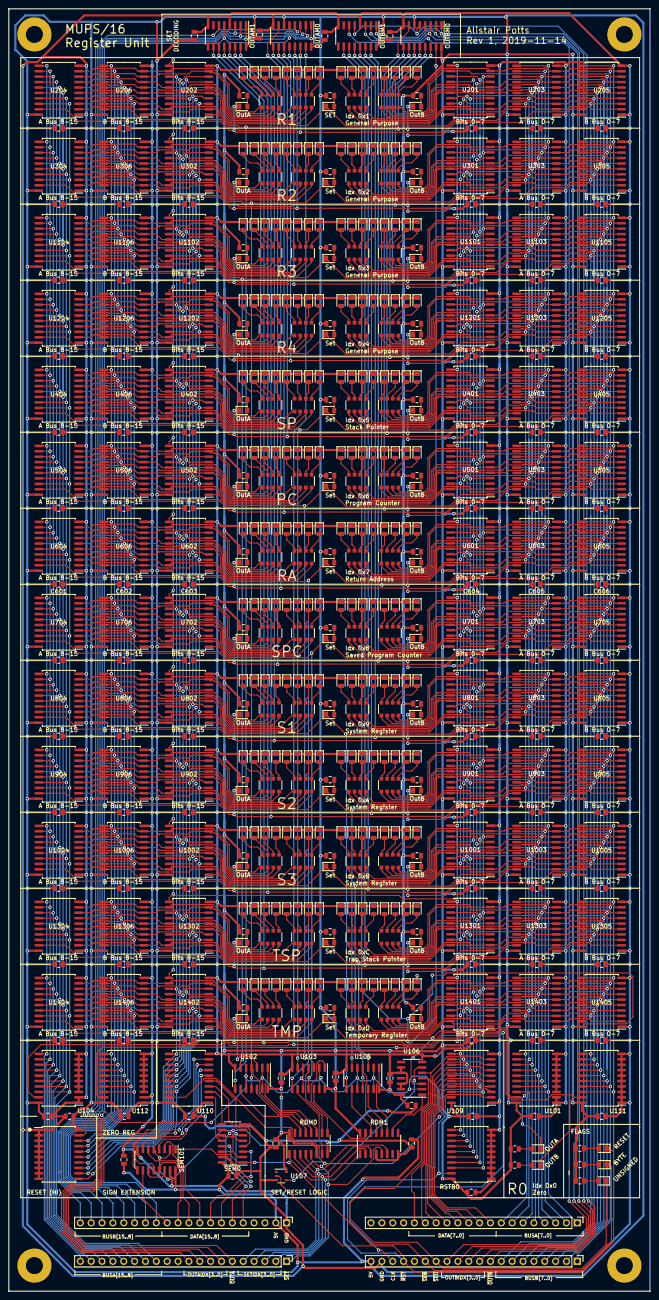
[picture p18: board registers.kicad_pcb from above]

Board: 2 copper layers, 150.0 x 300.0 mm, 553 parts (0 on the bottom side), 609 nets.

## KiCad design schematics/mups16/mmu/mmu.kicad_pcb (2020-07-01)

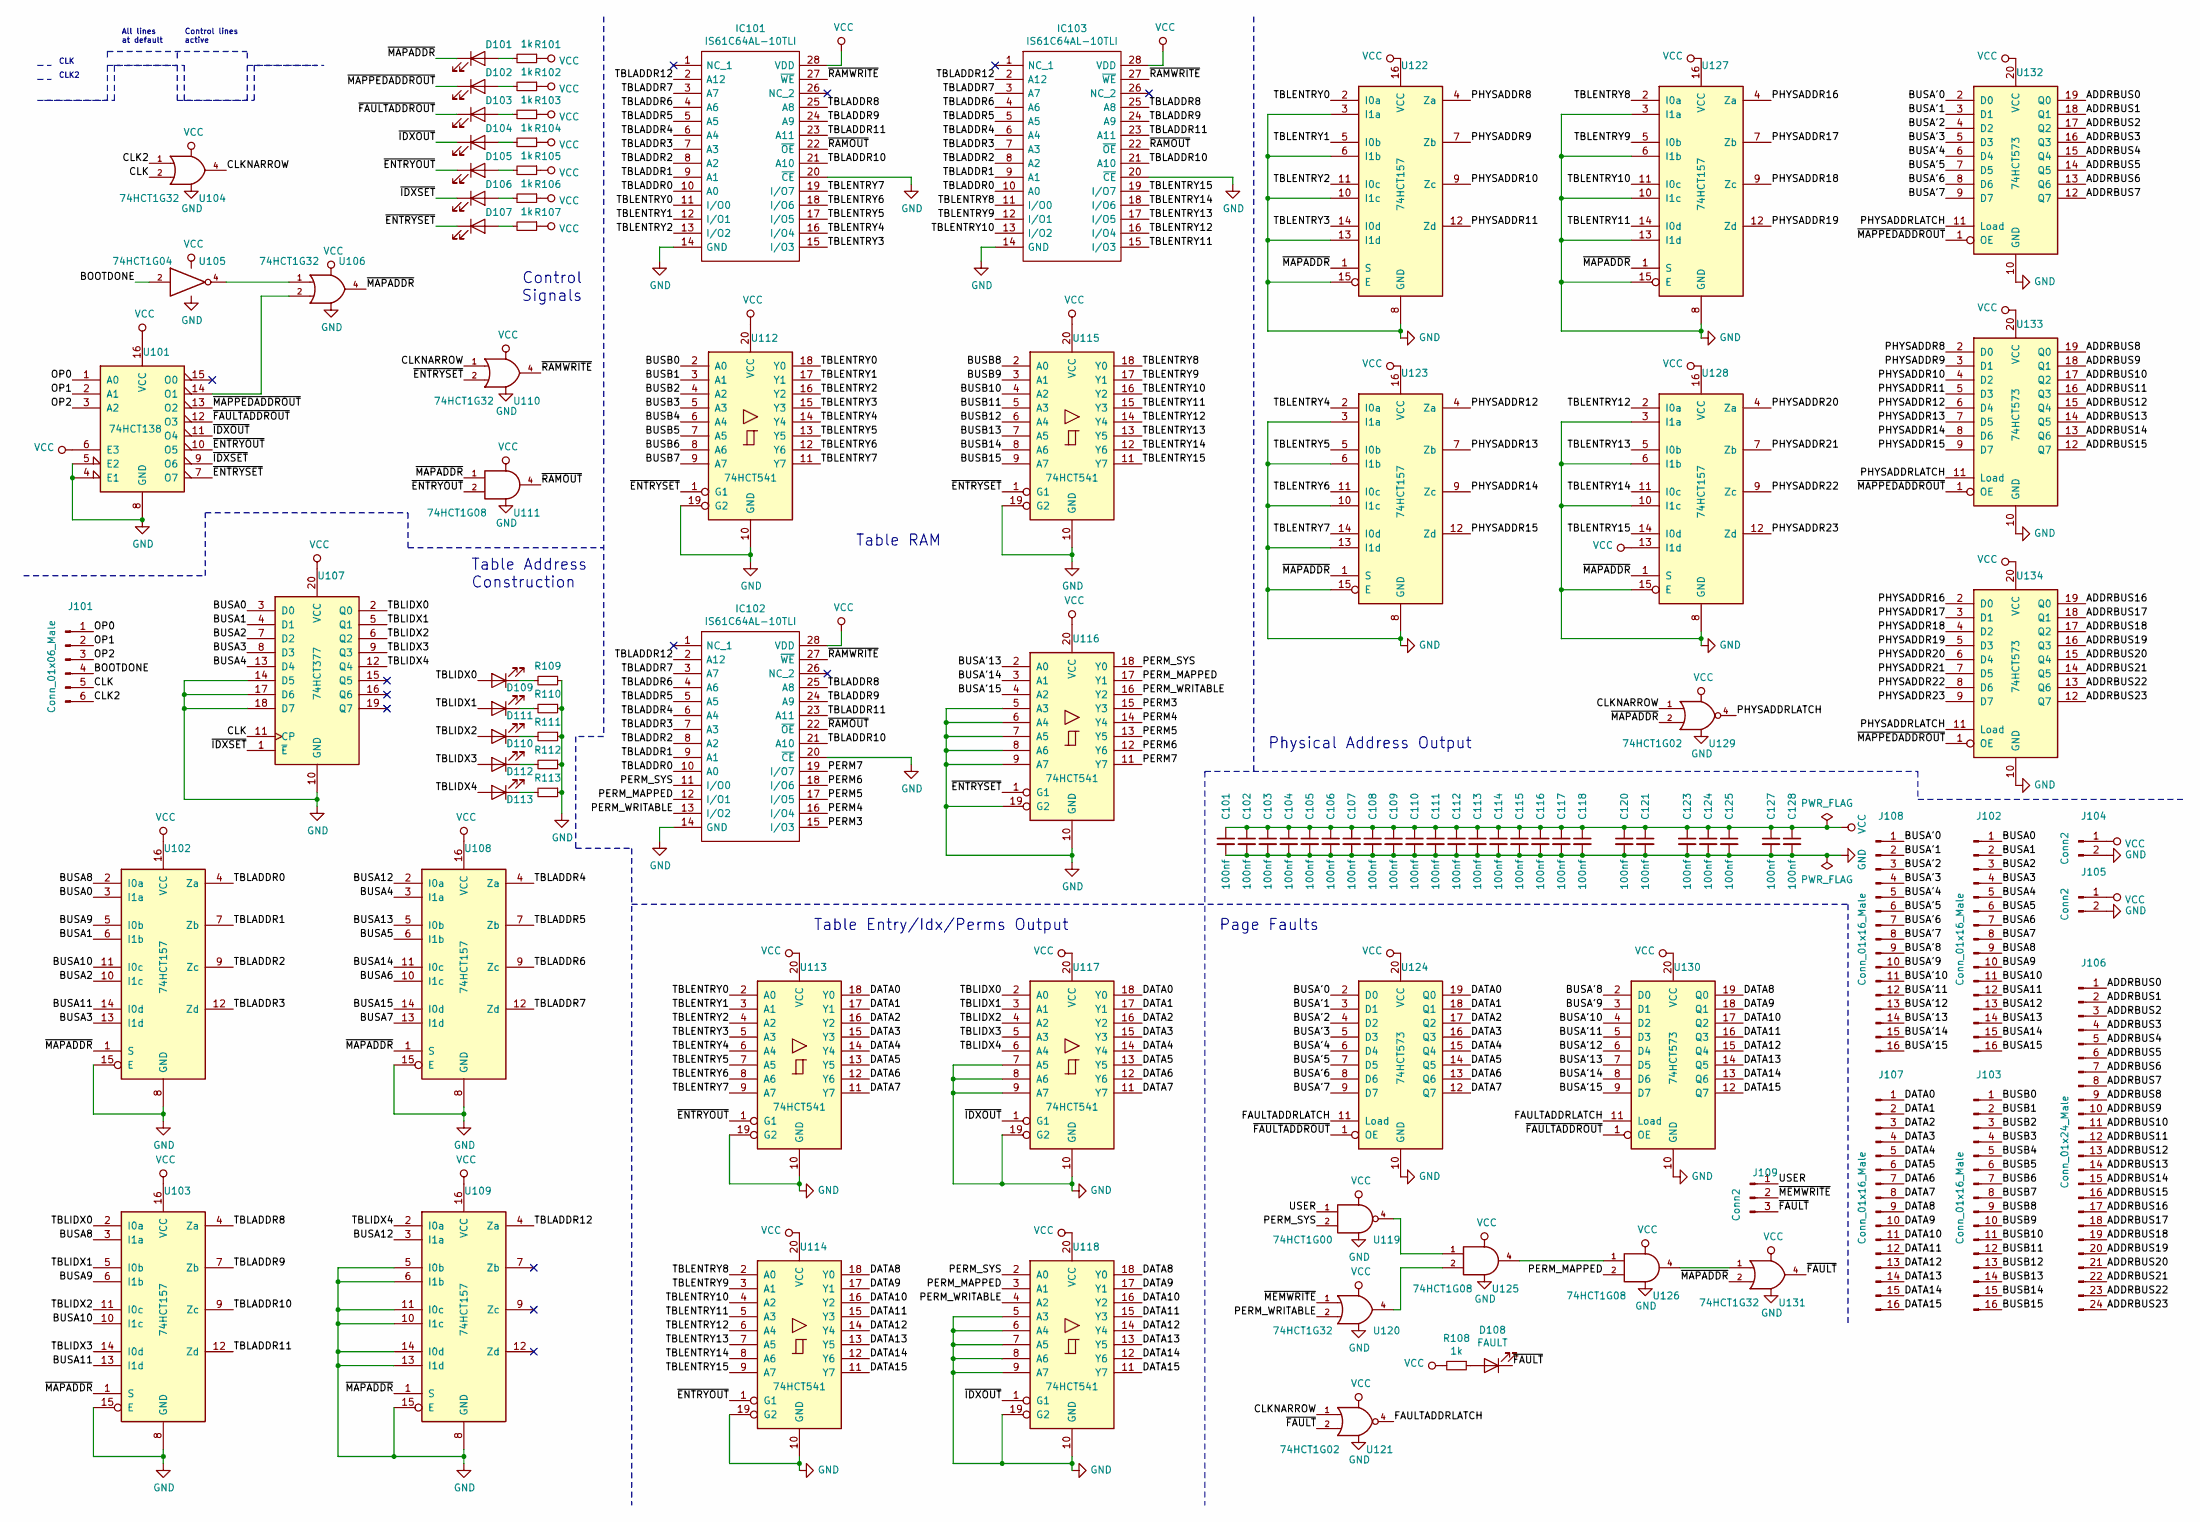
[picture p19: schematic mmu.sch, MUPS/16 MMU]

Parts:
C101, C102, C103, C104, C105, C106, C107, C108, C109, C110, C111, C112, C113, C114, C115, C116, C117, C118, C120, C121, C123, C124, C125, C127, C128: 100nf; C_0805_2012Metric
D101: Map Addr; LED_0805_2012Metric
D102: PAddr Out; LED_0805_2012Metric
D103: FAddr Out; LED_0805_2012Metric
D104: TI/P Out; LED_0805_2012Metric
D105: TE Out; LED_0805_2012Metric
D106: TI Set; LED_0805_2012Metric
D107: TE Set; LED_0805_2012Metric
D108: FAULT; LED_0805_2012Metric
D109, D110, D111, D112, D113: LED; LED_0805_2012Metric
IC101, IC102, IC103: IS61C64AL-10TLI; SOP55P1340X120-28N; Mouser Part Number 870-IS61C64AL-10TLI
J101: Conn_01x06_Male; PinHeader_1x06_P2.54mm_Vertical
J102, J103, J107, J108: Conn_01x16_Male; PinHeader_1x16_P2.54mm_Vertical
J104, J105: Conn2; PinHeader_1x02_P2.54mm_Vertical
J106: Conn_01x24_Male; PinHeader_1x24_P2.54mm_Vertical
J109: Conn2; PinHeader_1x03_P2.54mm_Vertical
R101, R102, R103, R104, R105, R106, R107, R108: 1k; R_0805_2012Metric
R109, R110, R111, R112, R113: R_Small; R_0805_2012Metric
U101: 74HCT138; SOIC-16_3.9x9.9mm_P1.27mm
U102, U103, U108, U109, U122, U123, U127, U128: 74HCT157; SOIC-16_3.9x9.9mm_P1.27mm
U104, U106, U110, U120, U131: 74HCT1G32; TSOP-5_1.65x3.05mm_P0.95mm
U105: 74HCT1G04; TSOP-5_1.65x3.05mm_P0.95mm
U107: 74HCT377; SO-20_12.8x7.5mm_P1.27mm
U111, U125, U126: 74HCT1G08; TSOP-5_1.65x3.05mm_P0.95mm
U112, U113, U114, U115, U116, U117, U118: 74HCT541; SOIC-20W_7.5x12.8mm_P1.27mm
U119: 74HCT1G00; TSOP-5_1.65x3.05mm_P0.95mm
U121, U129: 74HCT1G02; SOT65P212X110-5N
U124, U130, U132, U133, U134: 74HCT573; SO-20_12.8x7.5mm_P1.27mm

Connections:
/ADDRBUS0: J106.1, U132.19 (Q0)
/ADDRBUS1: J106.2, U132.18 (Q1)
/ADDRBUS2: J106.3, U132.17 (Q2)
/ADDRBUS3: J106.4, U132.16 (Q3)
/ADDRBUS4: J106.5, U132.15 (Q4)
/ADDRBUS5: J106.6, U132.14 (Q5)
/ADDRBUS6: J106.7, U132.13 (Q6)
/ADDRBUS7: J106.8, U132.12 (Q7)
/ADDRBUS8: J106.9, U133.19 (Q0)
/ADDRBUS9: J106.10, U133.18 (Q1)
/ADDRBUS10: J106.11, U133.17 (Q2)
/ADDRBUS11: J106.12, U133.16 (Q3)
/ADDRBUS12: J106.13, U133.15 (Q4)
/ADDRBUS13: J106.14, U133.14 (Q5)
/ADDRBUS14: J106.15, U133.13 (Q6)
/ADDRBUS15: J106.16, U133.12 (Q7)
/ADDRBUS16: J106.17, U134.19 (Q0)
/ADDRBUS17: J106.18, U134.18 (Q1)
/ADDRBUS18: J106.19, U134.17 (Q2)
/ADDRBUS19: J106.20, U134.16 (Q3)
/ADDRBUS20: J106.21, U134.15 (Q4)
/ADDRBUS21: J106.22, U134.14 (Q5)
/ADDRBUS22: J106.23, U134.13 (Q6)
/ADDRBUS23: J106.24, U134.12 (Q7)
/BOOTDONE: J101.4, U105.2
/BUSA0: J102.1, U102.3 (I1a), U107.3 (D0)
/BUSA1: J102.2, U102.6 (I1b), U107.4 (D1)
/BUSA2: J102.3, U102.10 (I1c), U107.7 (D2)
/BUSA3: J102.4, U102.13 (I1d), U107.8 (D3)
/BUSA4: J102.5, U107.13 (D4), U108.3 (I1a)
/BUSA5: J102.6, U108.6 (I1b)
/BUSA6: J102.7, U108.10 (I1c)
/BUSA7: J102.8, U108.13 (I1d)
/BUSA8: J102.9, U102.2 (I0a), U103.3 (I1a)
/BUSA9: J102.10, U102.5 (I0b), U103.6 (I1b)
/BUSA10: J102.11, U102.11 (I0c), U103.10 (I1c)
/BUSA11: J102.12, U102.14 (I0d), U103.13 (I1d)
/BUSA12: J102.13, U108.2 (I0a), U109.3 (I1a)
/BUSA13: J102.14, U108.5 (I0b)
/BUSA14: J102.15, U108.11 (I0c)
/BUSA15: J102.16, U108.14 (I0d)
/BUSA'0: J108.1, U124.2 (D0), U132.2 (D0)
/BUSA'1: J108.2, U124.3 (D1), U132.3 (D1)
/BUSA'2: J108.3, U124.4 (D2), U132.4 (D2)
/BUSA'3: J108.4, U124.5 (D3), U132.5 (D3)
/BUSA'4: J108.5, U124.6 (D4), U132.6 (D4)
/BUSA'5: J108.6, U124.7 (D5), U132.7 (D5)
/BUSA'6: J108.7, U124.8 (D6), U132.8 (D6)
/BUSA'7: J108.8, U124.9 (D7), U132.9 (D7)
/BUSA'8: J108.9, U130.2 (D0)
/BUSA'9: J108.10, U130.3 (D1)
/BUSA'10: J108.11, U130.4 (D2)
/BUSA'11: J108.12, U130.5 (D3)
/BUSA'12: J108.13, U130.6 (D4)
/BUSA'13: J108.14, U116.2 (A0), U130.7 (D5)
/BUSA'14: J108.15, U116.3 (A1), U130.8 (D6)
/BUSA'15: J108.16, U116.4 (A2), U130.9 (D7)
/BUSB0: J103.1, U112.2 (A0)
/BUSB1: J103.2, U112.3 (A1)
/BUSB2: J103.3, U112.4 (A2)
/BUSB3: J103.4, U112.5 (A3)
/BUSB4: J103.5, U112.6 (A4)
/BUSB5: J103.6, U112.7 (A5)
/BUSB6: J103.7, U112.8 (A6)
/BUSB7: J103.8, U112.9 (A7)
/BUSB8: J103.9, U115.2 (A0)
/BUSB9: J103.10, U115.3 (A1)
/BUSB10: J103.11, U115.4 (A2)
/BUSB11: J103.12, U115.5 (A3)
/BUSB12: J103.13, U115.6 (A4)
/BUSB13: J103.14, U115.7 (A5)
/BUSB14: J103.15, U115.8 (A6)
/BUSB15: J103.16, U115.9 (A7)
/CLK: J101.5, U104.2, U107.11 (CP)
/CLK2: J101.6, U104.1
/CLKNARROW: U104.4, U110.1, U121.1, U129.1
/DATA0: J107.1, U113.18 (Y0), U117.18 (Y0), U124.19 (Q0)
/DATA1: J107.2, U113.17 (Y1), U117.17 (Y1), U124.18 (Q1)
/DATA2: J107.3, U113.16 (Y2), U117.16 (Y2), U124.17 (Q2)
/DATA3: J107.4, U113.15 (Y3), U117.15 (Y3), U124.16 (Q3)
/DATA4: J107.5, U113.14 (Y4), U117.14 (Y4), U124.15 (Q4)
/DATA5: J107.6, U113.13 (Y5), U117.13 (Y5), U124.14 (Q5)
/DATA6: J107.7, U113.12 (Y6), U117.12 (Y6), U124.13 (Q6)
/DATA7: J107.8, U113.11 (Y7), U117.11 (Y7), U124.12 (Q7)
/DATA8: J107.9, U114.18 (Y0), U118.18 (Y0), U130.19 (Q0)
/DATA9: J107.10, U114.17 (Y1), U118.17 (Y1), U130.18 (Q1)
/DATA10: J107.11, U114.16 (Y2), U118.16 (Y2), U130.17 (Q2)
/DATA11: J107.12, U114.15 (Y3), U118.15 (Y3), U130.16 (Q3)
/DATA12: J107.13, U114.14 (Y4), U118.14 (Y4), U130.15 (Q4)
/DATA13: J107.14, U114.13 (Y5), U118.13 (Y5), U130.14 (Q5)
/DATA14: J107.15, U114.12 (Y6), U118.12 (Y6), U130.13 (Q6)
/DATA15: J107.16, U114.11 (Y7), U118.11 (Y7), U130.12 (Q7)
/FAULTADDRLATCH: U121.4, U124.11 (Load), U130.11 (Load)
/OP0: J101.1, U101.1 (A0)
/OP1: J101.2, U101.2 (A1)
/OP2: J101.3, U101.3 (A2)
/PERM3: IC102.15 (I/O3), U116.15 (Y3)
/PERM4: IC102.16 (I/O4), U116.14 (Y4)
/PERM5: IC102.17 (I/O5), U116.13 (Y5)
/PERM6: IC102.18 (I/O6), U116.12 (Y6)
/PERM7: IC102.19 (I/O7), U116.11 (Y7)
/PERM_MAPPED: IC102.12 (I/O1), U116.17 (Y1), U118.3 (A1), U126.2
/PERM_SYS: IC102.11 (I/O0), U116.18 (Y0), U118.2 (A0), U119.2
/PERM_WRITABLE: IC102.13 (I/O2), U116.16 (Y2), U118.4 (A2), U120.2
/PHYSADDR8: U122.4 (Za), U133.2 (D0)
/PHYSADDR9: U122.7 (Zb), U133.3 (D1)
/PHYSADDR10: U122.9 (Zc), U133.4 (D2)
/PHYSADDR11: U122.12 (Zd), U133.5 (D3)
/PHYSADDR12: U123.4 (Za), U133.6 (D4)
/PHYSADDR13: U123.7 (Zb), U133.7 (D5)
/PHYSADDR14: U123.9 (Zc), U133.8 (D6)
/PHYSADDR15: U123.12 (Zd), U133.9 (D7)
/PHYSADDR16: U127.4 (Za), U134.2 (D0)
/PHYSADDR17: U127.7 (Zb), U134.3 (D1)
/PHYSADDR18: U127.9 (Zc), U134.4 (D2)
/PHYSADDR19: U127.12 (Zd), U134.5 (D3)
/PHYSADDR20: U128.4 (Za), U134.6 (D4)
/PHYSADDR21: U128.7 (Zb), U134.7 (D5)
/PHYSADDR22: U128.9 (Zc), U134.8 (D6)
/PHYSADDR23: U128.12 (Zd), U134.9 (D7)
/PHYSADDRLATCH: U129.4, U132.11 (Load), U133.11 (Load), U134.11 (Load)
/TBLADDR0: IC101.10 (A0), IC102.10 (A0), IC103.10 (A0), U102.4 (Za)
/TBLADDR1: IC101.9 (A1), IC102.9 (A1), IC103.9 (A1), U102.7 (Zb)
/TBLADDR2: IC101.8 (A2), IC102.8 (A2), IC103.8 (A2), U102.9 (Zc)
/TBLADDR3: IC101.7 (A3), IC102.7 (A3), IC103.7 (A3), U102.12 (Zd)
/TBLADDR4: IC101.6 (A4), IC102.6 (A4), IC103.6 (A4), U108.4 (Za)
/TBLADDR5: IC101.5 (A5), IC102.5 (A5), IC103.5 (A5), U108.7 (Zb)
/TBLADDR6: IC101.4 (A6), IC102.4 (A6), IC103.4 (A6), U108.9 (Zc)
/TBLADDR7: IC101.3 (A7), IC102.3 (A7), IC103.3 (A7), U108.12 (Zd)
/TBLADDR8: IC101.25 (A8), IC102.25 (A8), IC103.25 (A8), U103.4 (Za)
/TBLADDR9: IC101.24 (A9), IC102.24 (A9), IC103.24 (A9), U103.7 (Zb)
/TBLADDR10: IC101.21 (A10), IC102.21 (A10), IC103.21 (A10), U103.9 (Zc)
/TBLADDR11: IC101.23 (A11), IC102.23 (A11), IC103.23 (A11), U103.12 (Zd)
/TBLADDR12: IC101.2 (A12), IC102.2 (A12), IC103.2 (A12), U109.4 (Za)
/TBLENTRY0: IC101.11 (I/O0), U112.18 (Y0), U113.2 (A0), U122.2 (I0a)
/TBLENTRY1: IC101.12 (I/O1), U112.17 (Y1), U113.3 (A1), U122.5 (I0b)
/TBLENTRY2: IC101.13 (I/O2), U112.16 (Y2), U113.4 (A2), U122.11 (I0c)
/TBLENTRY3: IC101.15 (I/O3), U112.15 (Y3), U113.5 (A3), U122.14 (I0d)
/TBLENTRY4: IC101.16 (I/O4), U112.14 (Y4), U113.6 (A4), U123.2 (I0a)
/TBLENTRY5: IC101.17 (I/O5), U112.13 (Y5), U113.7 (A5), U123.5 (I0b)
/TBLENTRY6: IC101.18 (I/O6), U112.12 (Y6), U113.8 (A6), U123.11 (I0c)
/TBLENTRY7: IC101.19 (I/O7), U112.11 (Y7), U113.9 (A7), U123.14 (I0d)
/TBLENTRY8: IC103.11 (I/O0), U114.2 (A0), U115.18 (Y0), U127.2 (I0a)
/TBLENTRY9: IC103.12 (I/O1), U114.3 (A1), U115.17 (Y1), U127.5 (I0b)
/TBLENTRY10: IC103.13 (I/O2), U114.4 (A2), U115.16 (Y2), U127.11 (I0c)
/TBLENTRY11: IC103.15 (I/O3), U114.5 (A3), U115.15 (Y3), U127.14 (I0d)
/TBLENTRY12: IC103.16 (I/O4), U114.6 (A4), U115.14 (Y4), U128.2 (I0a)
/TBLENTRY13: IC103.17 (I/O5), U114.7 (A5), U115.13 (Y5), U128.5 (I0b)
/TBLENTRY14: IC103.18 (I/O6), U114.8 (A6), U115.12 (Y6), U128.11 (I0c)
/TBLENTRY15: IC103.19 (I/O7), U114.9 (A7), U115.11 (Y7), U128.14 (I0d)
/TBLIDX0: D109.2 (A), U103.2 (I0a), U107.2 (Q0), U117.2 (A0)
/TBLIDX1: D110.2 (A), U103.5 (I0b), U107.5 (Q1), U117.3 (A1)
/TBLIDX2: D111.2 (A), U103.11 (I0c), U107.6 (Q2), U117.4 (A2)
/TBLIDX3: D112.2 (A), U103.14 (I0d), U107.9 (Q3), U117.5 (A3)
/TBLIDX4: D113.2 (A), U107.12 (Q4), U109.2 (I0a), U117.6 (A4)
/USER: J109.1, U119.1
/~ENTRYOUT: D105.1 (K), U101.10 (O5), U111.2, U113.1 (G1), U114.1 (G1)
/~ENTRYSET: D107.1 (K), U101.7 (O7), U110.2, U112.1 (G1), U115.1 (G1), U116.1 (G1)
/~FAULT: D108.1 (K), J109.3, U121.2, U131.4
/~FAULTADDROUT: D103.1 (K), U101.12 (O3), U124.1 (OE), U130.1 (OE)
/~IDXOUT: D104.1 (K), U101.11 (O4), U117.1 (G1), U118.1 (G1)
/~IDXSET: D106.1 (K), U101.9 (O6), U107.1 (~E)
/~MAPADDR: D101.1 (K), U102.1 (S), U103.1 (S), U106.4, U108.1 (S), U109.1 (S), U111.1, U122.1 (S), U123.1 (S), U127.1 (S), U128.1 (S), U129.2, U131.2
/~MAPPEDADDROUT: D102.1 (K), U101.13 (O2), U132.1 (OE), U133.1 (OE), U134.1 (OE)
/~MEMWRITE: J109.2, U120.1
/~RAMOUT: IC101.22 (~OE), IC102.22 (~OE), IC103.22 (~OE), U111.4
/~RAMWRITE: IC101.27 (~WE), IC102.27 (~WE), IC103.27 (~WE), U110.4
GND: C101.2, C102.2, C103.2, C104.2, C105.2, C106.2, C107.2, C108.2, C109.2, C110.2, C111.2, C112.2, C113.2, C114.2, C115.2, C116.2, C117.2, C118.2, C120.2, C121.2, C123.2, C124.2, C125.2, C127.2, C128.2, IC101.14 (GND), IC101.20 (~CE), IC102.14 (GND), IC102.20 (~CE), IC103.14 (GND), IC103.20 (~CE), J104.2, J105.2, R109.1, R110.1, R111.1, R112.1, R113.1, U101.4 (E1), U101.5 (E2), U101.8 (GND), U102.8 (GND), U102.15 (E), U103.8 (GND), U103.15 (E), U104.3 (GND), U105.3 (GND), U106.3 (GND), U107.10 (GND), U107.14 (D5), U107.17 (D6), U107.18 (D7), U108.8 (GND), U108.15 (E), U109.5 (I0b), U109.6 (I1b), U109.8 (GND), U109.10 (I1c), U109.11 (I0c), U109.13 (I1d), U109.14 (I0d), U109.15 (E), U110.3 (GND), U111.3 (GND), U112.10 (GND), U112.19 (G2), U113.10 (GND), U113.19 (G2), U114.10 (GND), U114.19 (G2), U115.10 (GND), U115.19 (G2), U116.5 (A3), U116.6 (A4), U116.7 (A5), U116.8 (A6), U116.9 (A7), U116.10 (GND), U116.19 (G2), U117.7 (A5), U117.8 (A6), U117.9 (A7), U117.10 (GND), U117.19 (G2), U118.5 (A3), U118.6 (A4), U118.7 (A5), U118.8 (A6), U118.9 (A7), U118.10 (GND), U118.19 (G2), U119.3 (GND), U120.3 (GND), U121.3 (GND), U122.3 (I1a), U122.6 (I1b), U122.8 (GND), U122.10 (I1c), U122.13 (I1d), U122.15 (E), U123.3 (I1a), U123.6 (I1b), U123.8 (GND), U123.10 (I1c), U123.13 (I1d), U123.15 (E), U124.10 (GND), U125.3 (GND), U126.3 (GND), U127.3 (I1a), U127.6 (I1b), U127.8 (GND), U127.10 (I1c), U127.13 (I1d), U127.15 (E), U128.3 (I1a), U128.6 (I1b), U128.8 (GND), U128.10 (I1c), U128.15 (E), U129.3 (GND), U130.10 (GND), U131.3 (GND), U132.10 (GND), U133.10 (GND), U134.10 (GND)
unnamed: D101.2 (A), R101.2
unnamed: D102.2 (A), R102.2
unnamed: D103.2 (A), R103.2
unnamed: D104.2 (A), R104.2
unnamed: D105.2 (A), R105.2
unnamed: D106.2 (A), R106.2
unnamed: D107.2 (A), R107.2
unnamed: D108.2 (A), R108.1
unnamed: D109.1 (K), R109.2
unnamed: D110.1 (K), R110.2
unnamed: D111.1 (K), R111.2
unnamed: D112.1 (K), R112.2
unnamed: D113.1 (K), R113.2
unnamed: U101.14 (O1), U106.2
unnamed: U105.4, U106.1
unnamed: U119.4, U125.1
unnamed: U120.4, U125.2
unnamed: U125.4, U126.1
unnamed: U126.4, U131.1
VCC: C101.1, C102.1, C103.1, C104.1, C105.1, C106.1, C107.1, C108.1, C109.1, C110.1, C111.1, C112.1, C113.1, C114.1, C115.1, C116.1, C117.1, C118.1, C120.1, C121.1, C123.1, C124.1, C125.1, C127.1, C128.1, IC101.28 (VDD), IC102.28 (VDD), IC103.28 (VDD), J104.1, J105.1, R101.1, R102.1, R103.1, R104.1, R105.1, R106.1, R107.1, R108.2, U101.6 (E3), U101.16 (VCC), U102.16 (VCC), U103.16 (VCC), U104.5 (VCC), U105.5 (VCC), U106.5 (VCC), U107.20 (VCC), U108.16 (VCC), U109.16 (VCC), U110.5 (VCC), U111.5 (VCC), U112.20 (VCC), U113.20 (VCC), U114.20 (VCC), U115.20 (VCC), U116.20 (VCC), U117.20 (VCC), U118.20 (VCC), U119.5 (VCC), U120.5 (VCC), U121.5 (VCC), U122.16 (VCC), U123.16 (VCC), U124.20 (VCC), U125.5 (VCC), U126.5 (VCC), U127.16 (VCC), U128.13 (I1d), U128.16 (VCC), U129.5 (VCC), U130.20 (VCC), U131.5 (VCC), U132.20 (VCC), U133.20 (VCC), U134.20 (VCC)

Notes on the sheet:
All lines at default
Control lines active
CLK
CLK2
Table Address Construction
Control Signals
Table RAM
Table Entry/Idx/Perms Output
Physical Address Output
Page Faults

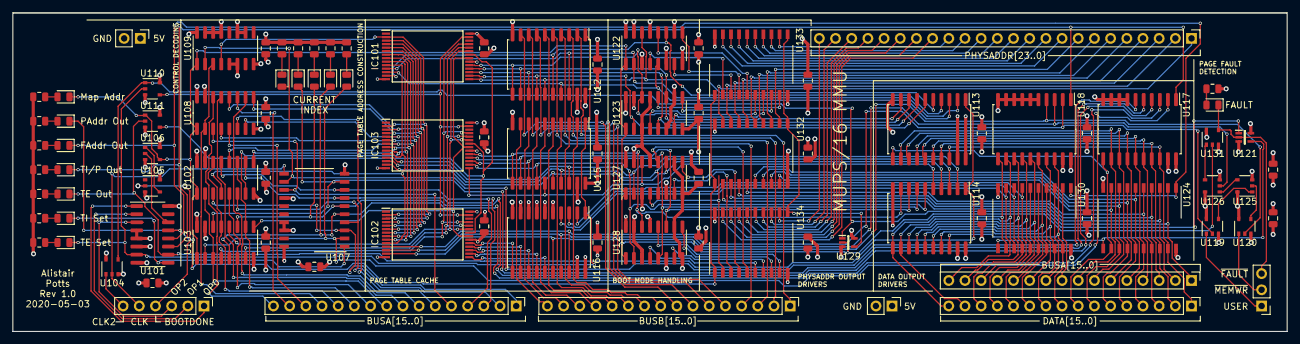
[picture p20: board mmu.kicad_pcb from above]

Board: 4 copper layers, 200.0 x 50.0 mm, 97 parts (0 on the bottom side), 188 nets.

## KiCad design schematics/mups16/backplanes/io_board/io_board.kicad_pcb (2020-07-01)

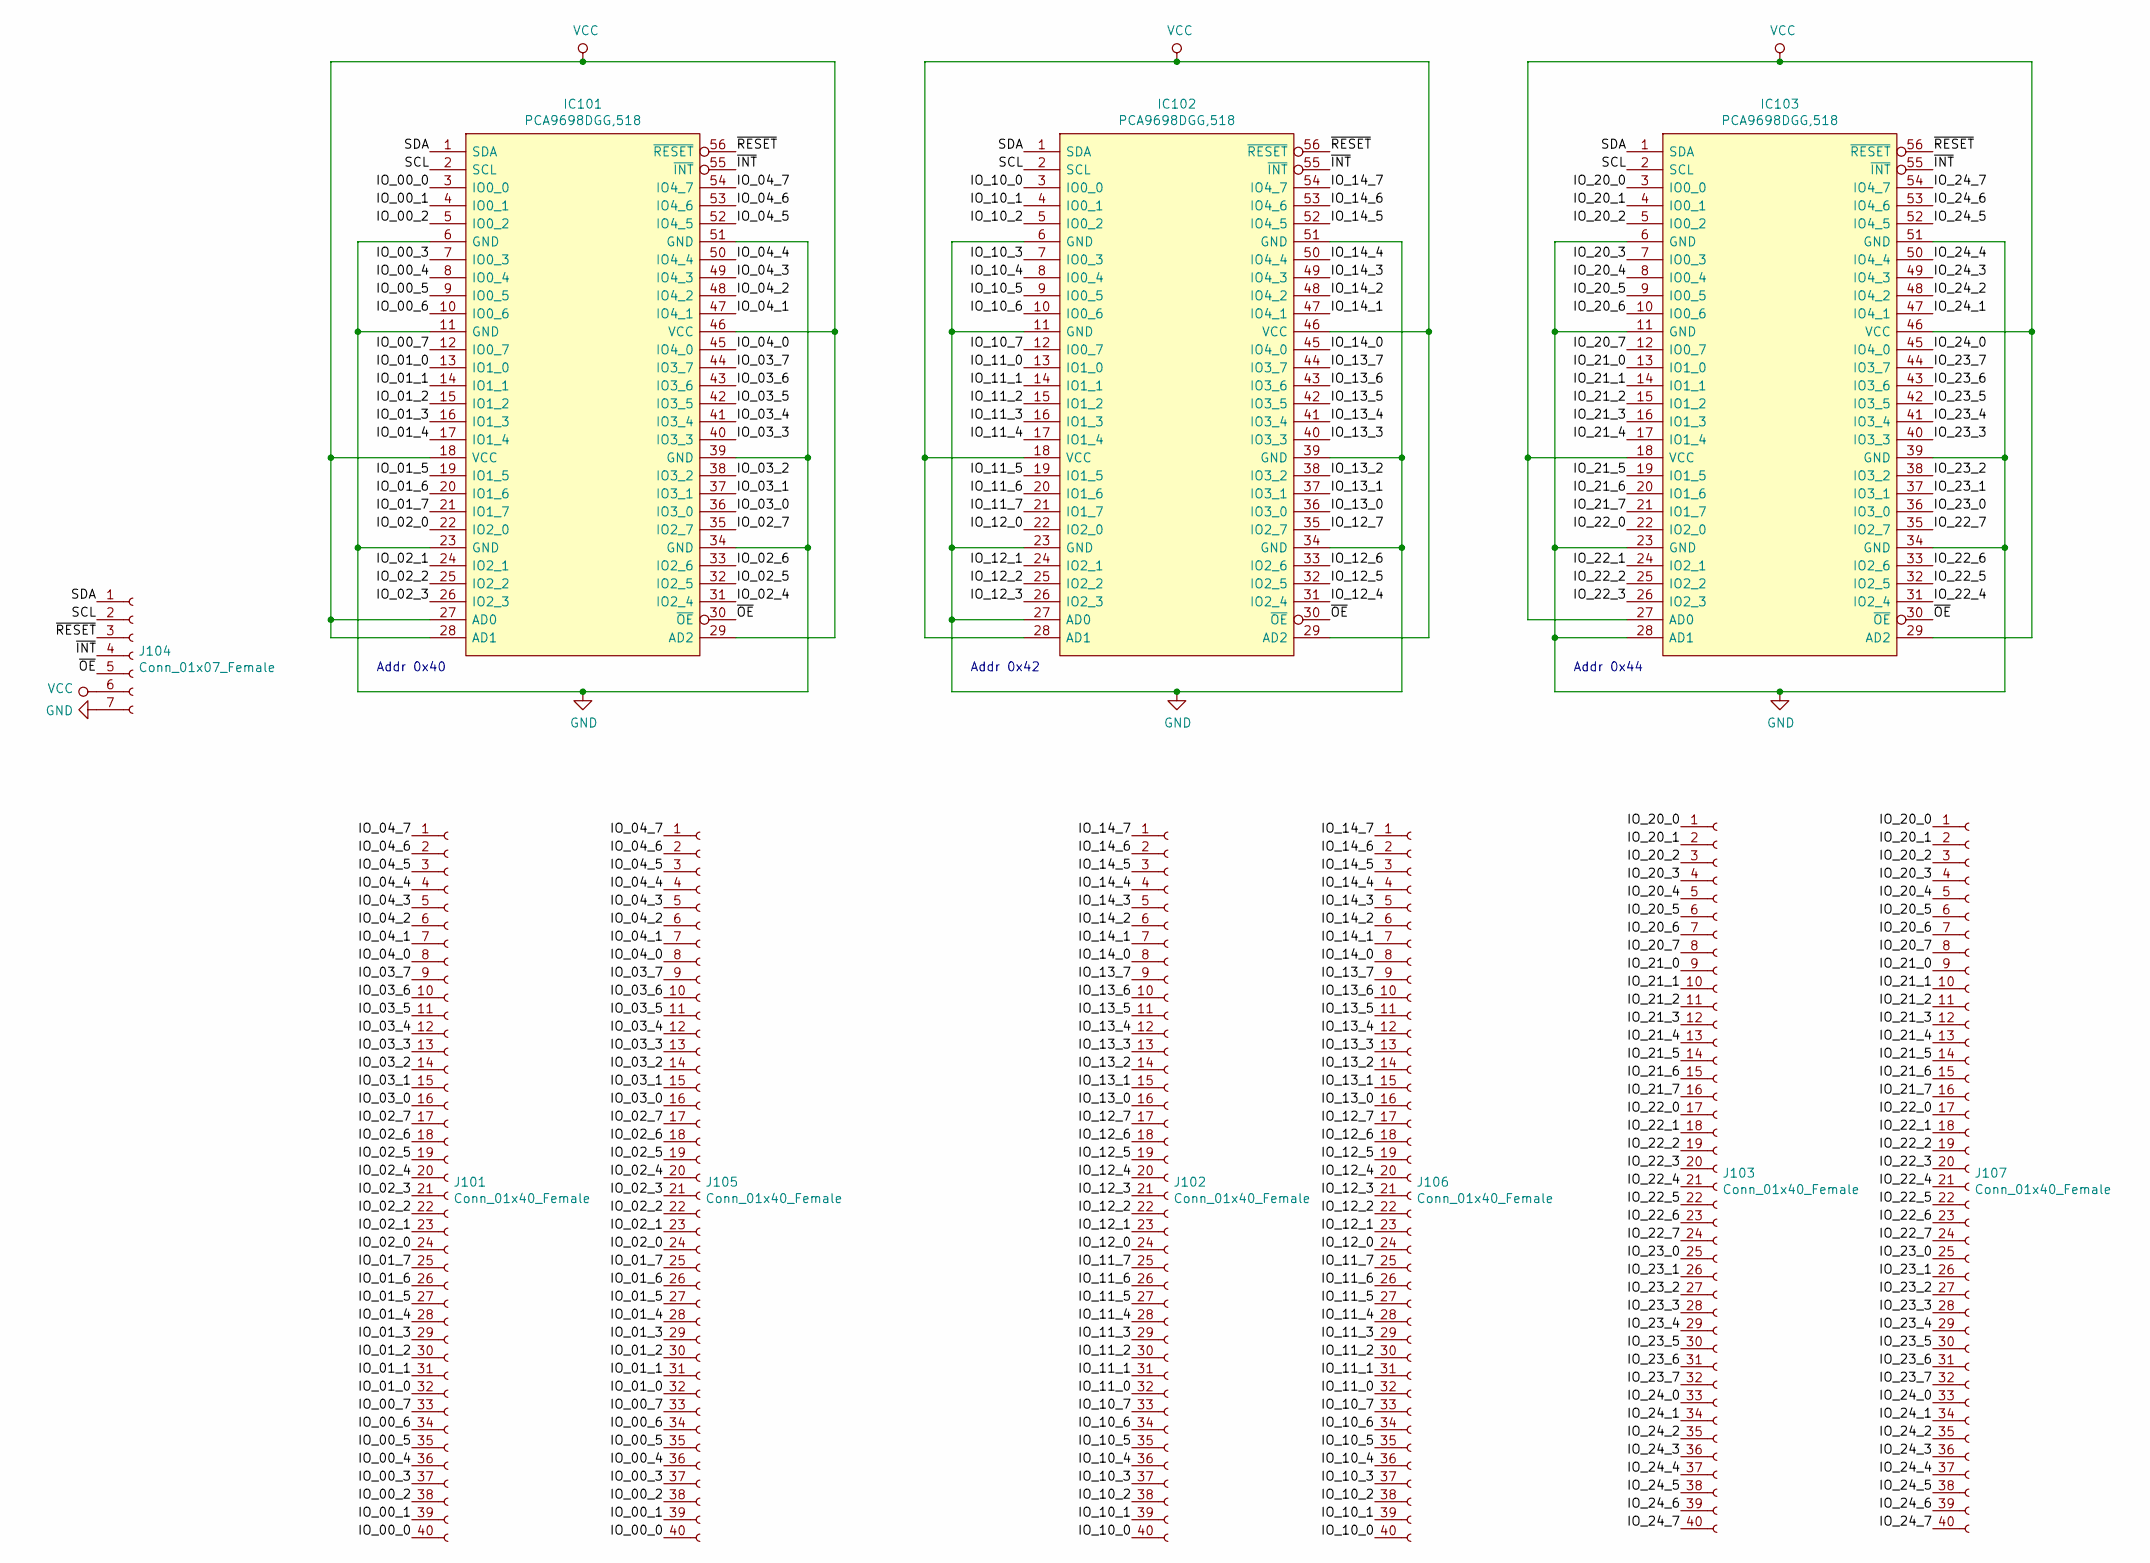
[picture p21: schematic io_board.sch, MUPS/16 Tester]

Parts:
IC101, IC102, IC103: PCA9698DGG,518; SOP50P810X120-56N; Mouser Part Number 771-PCA9698DGG-T
J101, J102, J103, J105, J106, J107: Conn_01x40_Female; PinSocket_2x20_P2.54mm_Vertical
J104: Conn_01x07_Female; PinSocket_1x07_P2.54mm_Vertical

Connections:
/IO_00_0: IC101.3 (IO0_0), J101.40, J105.40
/IO_00_1: IC101.4 (IO0_1), J101.39, J105.39
/IO_00_2: IC101.5 (IO0_2), J101.38, J105.38
/IO_00_3: IC101.7 (IO0_3), J101.37, J105.37
/IO_00_4: IC101.8 (IO0_4), J101.36, J105.36
/IO_00_5: IC101.9 (IO0_5), J101.35, J105.35
/IO_00_6: IC101.10 (IO0_6), J101.34, J105.34
/IO_00_7: IC101.12 (IO0_7), J101.33, J105.33
/IO_01_0: IC101.13 (IO1_0), J101.32, J105.32
/IO_01_1: IC101.14 (IO1_1), J101.31, J105.31
/IO_01_2: IC101.15 (IO1_2), J101.30, J105.30
/IO_01_3: IC101.16 (IO1_3), J101.29, J105.29
/IO_01_4: IC101.17 (IO1_4), J101.28, J105.28
/IO_01_5: IC101.19 (IO1_5), J101.27, J105.27
/IO_01_6: IC101.20 (IO1_6), J101.26, J105.26
/IO_01_7: IC101.21 (IO1_7), J101.25, J105.25
/IO_02_0: IC101.22 (IO2_0), J101.24, J105.24
/IO_02_1: IC101.24 (IO2_1), J101.23, J105.23
/IO_02_2: IC101.25 (IO2_2), J101.22, J105.22
/IO_02_3: IC101.26 (IO2_3), J101.21, J105.21
/IO_02_4: IC101.31 (IO2_4), J101.20, J105.20
/IO_02_5: IC101.32 (IO2_5), J101.19, J105.19
/IO_02_6: IC101.33 (IO2_6), J101.18, J105.18
/IO_02_7: IC101.35 (IO2_7), J101.17, J105.17
/IO_03_0: IC101.36 (IO3_0), J101.16, J105.16
/IO_03_1: IC101.37 (IO3_1), J101.15, J105.15
/IO_03_2: IC101.38 (IO3_2), J101.14, J105.14
/IO_03_3: IC101.40 (IO3_3), J101.13, J105.13
/IO_03_4: IC101.41 (IO3_4), J101.12, J105.12
/IO_03_5: IC101.42 (IO3_5), J101.11, J105.11
/IO_03_6: IC101.43 (IO3_6), J101.10, J105.10
/IO_03_7: IC101.44 (IO3_7), J101.9, J105.9
/IO_04_0: IC101.45 (IO4_0), J101.8, J105.8
/IO_04_1: IC101.47 (IO4_1), J101.7, J105.7
/IO_04_2: IC101.48 (IO4_2), J101.6, J105.6
/IO_04_3: IC101.49 (IO4_3), J101.5, J105.5
/IO_04_4: IC101.50 (IO4_4), J101.4, J105.4
/IO_04_5: IC101.52 (IO4_5), J101.3, J105.3
/IO_04_6: IC101.53 (IO4_6), J101.2, J105.2
/IO_04_7: IC101.54 (IO4_7), J101.1, J105.1
/IO_10_0: IC102.3 (IO0_0), J102.40, J106.40
/IO_10_1: IC102.4 (IO0_1), J102.39, J106.39
/IO_10_2: IC102.5 (IO0_2), J102.38, J106.38
/IO_10_3: IC102.7 (IO0_3), J102.37, J106.37
/IO_10_4: IC102.8 (IO0_4), J102.36, J106.36
/IO_10_5: IC102.9 (IO0_5), J102.35, J106.35
/IO_10_6: IC102.10 (IO0_6), J102.34, J106.34
/IO_10_7: IC102.12 (IO0_7), J102.33, J106.33
/IO_11_0: IC102.13 (IO1_0), J102.32, J106.32
/IO_11_1: IC102.14 (IO1_1), J102.31, J106.31
/IO_11_2: IC102.15 (IO1_2), J102.30, J106.30
/IO_11_3: IC102.16 (IO1_3), J102.29, J106.29
/IO_11_4: IC102.17 (IO1_4), J102.28, J106.28
/IO_11_5: IC102.19 (IO1_5), J102.27, J106.27
/IO_11_6: IC102.20 (IO1_6), J102.26, J106.26
/IO_11_7: IC102.21 (IO1_7), J102.25, J106.25
/IO_12_0: IC102.22 (IO2_0), J102.24, J106.24
/IO_12_1: IC102.24 (IO2_1), J102.23, J106.23
/IO_12_2: IC102.25 (IO2_2), J102.22, J106.22
/IO_12_3: IC102.26 (IO2_3), J102.21, J106.21
/IO_12_4: IC102.31 (IO2_4), J102.20, J106.20
/IO_12_5: IC102.32 (IO2_5), J102.19, J106.19
/IO_12_6: IC102.33 (IO2_6), J102.18, J106.18
/IO_12_7: IC102.35 (IO2_7), J102.17, J106.17
/IO_13_0: IC102.36 (IO3_0), J102.16, J106.16
/IO_13_1: IC102.37 (IO3_1), J102.15, J106.15
/IO_13_2: IC102.38 (IO3_2), J102.14, J106.14
/IO_13_3: IC102.40 (IO3_3), J102.13, J106.13
/IO_13_4: IC102.41 (IO3_4), J102.12, J106.12
/IO_13_5: IC102.42 (IO3_5), J102.11, J106.11
/IO_13_6: IC102.43 (IO3_6), J102.10, J106.10
/IO_13_7: IC102.44 (IO3_7), J102.9, J106.9
/IO_14_0: IC102.45 (IO4_0), J102.8, J106.8
/IO_14_1: IC102.47 (IO4_1), J102.7, J106.7
/IO_14_2: IC102.48 (IO4_2), J102.6, J106.6
/IO_14_3: IC102.49 (IO4_3), J102.5, J106.5
/IO_14_4: IC102.50 (IO4_4), J102.4, J106.4
/IO_14_5: IC102.52 (IO4_5), J102.3, J106.3
/IO_14_6: IC102.53 (IO4_6), J102.2, J106.2
/IO_14_7: IC102.54 (IO4_7), J102.1, J106.1
/IO_20_0: IC103.3 (IO0_0), J103.1, J107.1
/IO_20_1: IC103.4 (IO0_1), J103.2, J107.2
/IO_20_2: IC103.5 (IO0_2), J103.3, J107.3
/IO_20_3: IC103.7 (IO0_3), J103.4, J107.4
/IO_20_4: IC103.8 (IO0_4), J103.5, J107.5
/IO_20_5: IC103.9 (IO0_5), J103.6, J107.6
/IO_20_6: IC103.10 (IO0_6), J103.7, J107.7
/IO_20_7: IC103.12 (IO0_7), J103.8, J107.8
/IO_21_0: IC103.13 (IO1_0), J103.9, J107.9
/IO_21_1: IC103.14 (IO1_1), J103.10, J107.10
/IO_21_2: IC103.15 (IO1_2), J103.11, J107.11
/IO_21_3: IC103.16 (IO1_3), J103.12, J107.12
/IO_21_4: IC103.17 (IO1_4), J103.13, J107.13
/IO_21_5: IC103.19 (IO1_5), J103.14, J107.14
/IO_21_6: IC103.20 (IO1_6), J103.15, J107.15
/IO_21_7: IC103.21 (IO1_7), J103.16, J107.16
/IO_22_0: IC103.22 (IO2_0), J103.17, J107.17
/IO_22_1: IC103.24 (IO2_1), J103.18, J107.18
/IO_22_2: IC103.25 (IO2_2), J103.19, J107.19
/IO_22_3: IC103.26 (IO2_3), J103.20, J107.20
/IO_22_4: IC103.31 (IO2_4), J103.21, J107.21
/IO_22_5: IC103.32 (IO2_5), J103.22, J107.22
/IO_22_6: IC103.33 (IO2_6), J103.23, J107.23
/IO_22_7: IC103.35 (IO2_7), J103.24, J107.24
/IO_23_0: IC103.36 (IO3_0), J103.25, J107.25
/IO_23_1: IC103.37 (IO3_1), J103.26, J107.26
/IO_23_2: IC103.38 (IO3_2), J103.27, J107.27
/IO_23_3: IC103.40 (IO3_3), J103.28, J107.28
/IO_23_4: IC103.41 (IO3_4), J103.29, J107.29
/IO_23_5: IC103.42 (IO3_5), J103.30, J107.30
/IO_23_6: IC103.43 (IO3_6), J103.31, J107.31
/IO_23_7: IC103.44 (IO3_7), J103.32, J107.32
/IO_24_0: IC103.45 (IO4_0), J103.33, J107.33
/IO_24_1: IC103.47 (IO4_1), J103.34, J107.34
/IO_24_2: IC103.48 (IO4_2), J103.35, J107.35
/IO_24_3: IC103.49 (IO4_3), J103.36, J107.36
/IO_24_4: IC103.50 (IO4_4), J103.37, J107.37
/IO_24_5: IC103.52 (IO4_5), J103.38, J107.38
/IO_24_6: IC103.53 (IO4_6), J103.39, J107.39
/IO_24_7: IC103.54 (IO4_7), J103.40, J107.40
/SCL: IC101.2 (SCL), IC102.2 (SCL), IC103.2 (SCL), J104.2
/SDA: IC101.1 (SDA), IC102.1 (SDA), IC103.1 (SDA), J104.1
/~INT: IC101.55 (~INT), IC102.55 (~INT), IC103.55 (~INT), J104.4
/~OE: IC101.30 (~OE), IC102.30 (~OE), IC103.30 (~OE), J104.5
/~RESET: IC101.56 (~RESET), IC102.56 (~RESET), IC103.56 (~RESET), J104.3
GND: IC101.6 (GND), IC101.11 (GND), IC101.23 (GND), IC101.34 (GND), IC101.39 (GND), IC101.51 (GND), IC102.6 (GND), IC102.11 (GND), IC102.23 (GND), IC102.27 (AD0), IC102.34 (GND), IC102.39 (GND), IC102.51 (GND), IC103.6 (GND), IC103.11 (GND), IC103.23 (GND), IC103.28 (AD1), IC103.34 (GND), IC103.39 (GND), IC103.51 (GND), J104.7
VCC: IC101.18 (VCC), IC101.27 (AD0), IC101.28 (AD1), IC101.29 (AD2), IC101.46 (VCC), IC102.18 (VCC), IC102.28 (AD1), IC102.29 (AD2), IC102.46 (VCC), IC103.18 (VCC), IC103.27 (AD0), IC103.29 (AD2), IC103.46 (VCC), J104.6

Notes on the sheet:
Addr 0x40
Addr 0x42
Addr 0x44

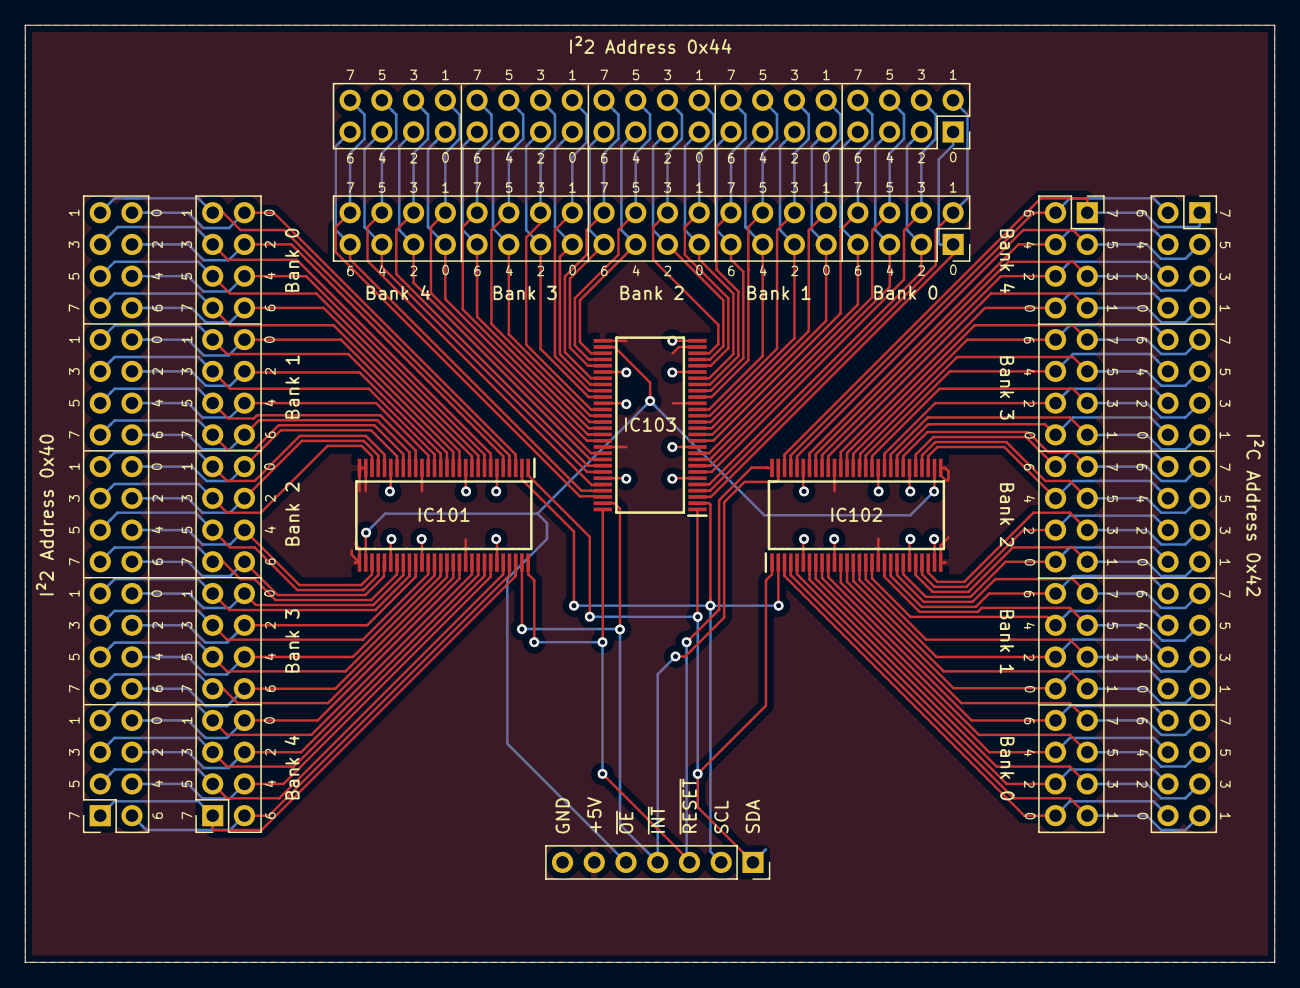
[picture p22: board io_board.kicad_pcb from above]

Board: 2 copper layers, 100.0 x 75.0 mm, 10 parts (0 on the bottom side), 127 nets.

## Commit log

2019-10-20 Initial commit containing test register
    [register.sch, test_register.kicad_pcb, test_register.sch]
2020-07-01 Added schematics and PCBs for all components completed so far
    [alu.kicad_pcb, alu.sch, bus_joiner.sch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]
